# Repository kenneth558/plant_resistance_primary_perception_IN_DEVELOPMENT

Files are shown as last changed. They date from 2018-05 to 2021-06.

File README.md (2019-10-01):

[Project now moved to wiki.  Simply click here](https://github.com/kenneth558/plant_resistance_primary_perception/wiki/Entanglement-GWAAMC), and thank you for correcting your link records!

[Project purchase and building instructions here](https://github.com/kenneth558/plant_resistance_primary_perception/tree/Free/Where%20to%20find%20everything%20for%20making%20your%20own%20GWAAMC%20device)

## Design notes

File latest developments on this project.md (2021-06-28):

<p align=center>Do you have an idea for features?  Now is a great time for all interested parties to ask me about including capabilities you think would make this project as valuable as it can be.  Just submit an "Issue" (see the tab above) describing the device feature that would interest you.  rdetiger asks for compatibility with Adafruit μCs. I think that is a great direction for me to look into. My best guess is that the Adafruit Metro 328 will run this code and accept this board without any trouble.  Thank you!</p>

<dl><dt>28 Jun 2021</dt></dl>Just as I was about to place and solder, I realized that numerous ENIG pads had gotten their gold scratched off by my repeated cleaning the solder off them.  Not having any more unused boards, I have to order more.  Ordered 3 from OSH Park.  They take 10 to 20 days to arrive.

<dl><dt>18 Jun 2021</dt></dl>Apparently my idea of using sparing amount of paste solder on the MSOP-8 packages is not a good idea.  I tried minimizing the amount of paste in order to reduce solder bridging.  I'll need to abandon that idea and order a new stencil having normal apertures for the MSOP-8 packages.

<dl><dt>16 Jun 2021</dt></dl>The oxidized contamination combined with my crazy sleep schedule overwhelmed me and made me miss my sunrise goal...

<dl><dt>15 Jun 2021</dt></dl>I am nearly finished soldering the SMD components to the most populated side of the board.  I expect to start soldering components to the other side by sunrise tomorrow.  I hope to be able to apply power before Saturday 19th at the very, very latest.  NOTE: I expect I'll erase all these development stage updates when the board becomes operational.  The updates will then become informational on discoveries from me and others using the training aid.

A challenge I face is to recognize solder paste oxidizes in short order, the small amounts and just need to be discarded rather than salvaged.  That is against my life's learning about resource management.  What is happening is that I set a small amount of paste solder out to dip from, and as it oxidizes it becomes a source of contamination to the joints I try to add it to.

<dl><dt>03 Jun 2021</dt></dl>I've had to work on the 
[Surveillance project](http://github.com/kenneth558/KingdomComeIMeanItAndIMeanNowSurveillance) instead of this one, but I'm nearing smoother sailing with than one to where I'll be able to come back to this project.  In fact,I'm actually at a point where the final work on the Surveillance project can only be done on site, which means that while I am home I can work on this project.  Thank you Lord!!!

<dl><dt>03 Apr 2021</dt></dl>Basement water problem turned my work area into chaos.  I can't find a clean PCB to build, so I placed another order yesterday for 3 more boards.  It will be a number of days before they arrive.

<dl><dt>06 Feb 2021</dt></dl>My other project is still distracting me from this one......

<dl><dt>20 Jan 2021</dt></dl>Trying to squeegee the paste solder on to the PCB, I find that the stencil retains the paste inside many of the apertures.  I'll see if I can adjust my technique to overcome this latest challenge.

<dl><dt>19 Jan 2021</dt></dl>After dropping an SMD or two, I spread a white drape over my work bench and scrap linoleum under the work table to better allow the finding of such components I'll most surely drop again.  Cost of time and momentum, but I'm returning...

<dl><dt>17 Jan 2021</dt></dl>I received my new solder stencil.  I'll get back to work on this project today after I get a night's rest and attend church later this morning.

<dl><dt>12 Jan 2021</dt></dl>I just discovered that the solder stencil I've had since April had no alignment holes, making it unreasonably difficult to place over the PCB accurately.  I ordered a new one, and it is on its way to me.

<dl><dt>03 Jan 2021</dt></dl>I'm trying to develop a paste solder application scheme.  I have no known finish date, yet.

<dl><dt>27 Dec 2020</dt></dl>I'm just not satisfied with any of the USB microscopes I find for sale.  So instead, I will put together various lenses I have.  The advantage of that is high resolution and accurate color rendering, so I hope it will all be for the better.

<dl><dt>24 Dec 2020</dt></dl>Sigh...  In the re-arranging, my USB microscope broke.  I really need that thing!  Unable to disassemble it (it's probably epoxied).  The good side is that the next one I order should be better quality, if I can make that happen.  Shopping for it next...

<dl><dt>23 Dec 2020</dt></dl>I plan to return to this project today.  FINALLY!

<dl><dt>19 Dec 2020</dt></dl>No updates again, but the security system development is done enough that I'll start now to arrange this project for resumption...after a good night's sleep, maybe two.  During this interim period, I've had to physically re-arrange everything related to this project which makes it not merely a simple matter of picking up where I left off.

<dl><dt>19 Nov 2020</dt></dl>No update again.  Still distracted from this project by having to develop a security system for my father's property.

<dl><dt>08 Sep 2020</dt></dl>No update again.  Still distracted from this project by having to develop a security system for my father's property.

<dl><dt>23 Aug 2020</dt></dl>I'm now being pulled away from this important project by other urgencies, like thieves and vandals to my father's property which make me develop a security system.  His property is where my web server-to-be is located.

<dl><dt>28 Jul 2020</dt></dl>After some weeks of distraction, I am slowly returning to this project.  I think my next step is to place and solder componponents.

<dl><dt>14 Jul 2020</dt></dl>While awaiting components, I am configuring a server for the GWAAMC web site.  It will include a tight firewall ruleset from my poofitee project, knowing how there are so many malicious and mischievous malevolents on the internet.

<dl><dt>11 Jul 2020</dt></dl>My component order ended up being two orders.  One is scheduled to arrive next Thursday, 16 Jul 2020.  The other order, consisting of Q1 and Q2, is pending.  These two P-channel J-FETs one the second order are to demanding specs in noise level and V<sub>gs</sub> cutoff voltage.

<dl><dt>10 Jul 2020</dt></dl>This latest jig looks like it will work.  The quality of print is slightly under past prints I've received, but at least the design that I sent to the printer seems to be correct this time.  Loaded as many components as I had.  Discovered I need to order more components.  Did it.  Waiting for those components to arrive.

<dl><dt>09 Jul 2020</dt></dl>Given clues by the postal service, I found that they delivered to the wrong address.  Jig retrieved, looks like I got it right this time, assembling a board.  Files for printing a jig of your own here -> https://drive.google.com/drive/folders/1_j0E5dFC1kLGvFu55QTtv5UvltjqBdjs?usp=sharing.

<dl><dt>08 Jul 2020</dt></dl>The postal service says they delivered the latest jig to me, but there was no jig in the mailbox or even in the secondary delivery location.  I'll meet the postal delivery person tomorrow and have a talk with them about this.

<dl><dt>02 Jul 2020</dt></dl>Final jig is ordered.  No word if it will go into printing before the July 4 weekend.

<dl><dt>01 Jul 2020</dt></dl>The new jig has some too tight capacitor cavities.  Another one has to be made.  I also realized there are a few components I had yet to order, so I placed component orders.

<dl><dt>30 Jun 2020</dt></dl>While populating the jig, I found a couple issues that really need to be addressed still before it will work.  A new jig will arrive tomorrow which might work.

<dl><dt>27 Jun 2020</dt></dl>Done designing new jig and ordered it.  Now building a board with this jig that I took a utiiity knife to and made it workable.

<dl><dt>26 Jun 2020</dt></dl>Jig received.  Building a board while tweaking the jig design in small ways.

<dl><dt>24 Jun 2020</dt></dl>I will be receiving the jig by Saturday June 27.

<dl><dt>19 Jun 2020</dt></dl>Latest form design ordered.  As a clarification, this is the bottom side form I've been working on.  The top side was very easy and not even necessary but accomlished early on.  Later this day, I received notice that my order has already gone into production.  Based on previous dealings, I expect to receive the jig in 6 or 7 days.

<dl><dt>16 Jun 2020</dt></dl>Received my latest form/holder, and the VSSOP-8 wells are still too small.  Going for one last design now.

<dl><dt>11 Jun 2020</dt></dl>My son offered the term of "form" instead of "cassette" for these components holders.  I didn't care for calling them "cassettes".  I'll change their term to something like "holder" or "form".  They can also be called a "jig", but only as a last resort.

<dl><dt>09 Jun 2020</dt></dl>That cassette was better, but still not right.  Made corrections to design and ordered another.  A return notice is telling me the new cassette is already in production.

<dl><dt>05 Jun 2020</dt></dl>I received notice that my latest cassettes will arrive Monday, 08 Jun.

<dl><dt>03 Jun 2020</dt></dl>Again, The components wells were too small.  Ordered ones with larger wells and using three different materials.  I was promptly notified that my order went into production, for which I am pleased, of course.

<dl><dt>01 Jun 2020</dt></dl>The projected arrival date of my newest cassette has been changed to be today in about 4 hrs.

<dl><dt>28 May 2020</dt></dl>I had to modify the cavity sizes a bit larger in the bottom cassette and order a new one.  It is scheduled to arrive Tuesday June 2.

<dl><dt>17 May 2020</dt></dl>The cassettes are still in "Production started" status according to craftcloud3d web site.

<dl><dt>13 May 2020</dt></dl>I placed a new order for top and bottom resin cassette. No word as of 14 May 9am whether the order will get honored, but my last resin order did get made for me.  Product expected in 9 days.  Once the cassettes arrive I can start constructing boards.  I will also need to locate carbon fiber "tape".  Most of what I see for sale uses the term "graphite" in the sales lit.  Graphite and diamond are the WRONG forms of carbon for me to use.  I wish everyone would stay away from using the term "graphite" unless the molecular structure is actually graphite.  Bad terminology makes me have to dig deeper and even travel hundreds of miles to measure electrical resistance.

<dl><dt>12 May 2020</dt></dl>Both my cassette orders got canceled due to too fine of features for ABS.  I've arranged for someone to see if they can print the bottom.  No word back from them, yet....

<dl><dt>09 May 2020</dt></dl>Placed the order for the bottom cassette. 

<dl><dt>08 May 2020</dt></dl>Just placed an order for a new top aspect cassette.  Still working on the bottom to add one last item - some tin whiskers cages for the larger IC packages.  The design for MSOP package cages are done.  These cages will span across the IC packages to contain any tin whiskers that might form to only the pin they originate from.

<dl><dt>07 May 2020</dt></dl>Now making final changes to the bottom aspect cassette.

<dl><dt>05 May 2020</dt></dl>My cassette top will arrive tomorrow.  The design for the bottom is complete, sans any changes I will learn it needs from examining the top when I get it.  If all is well, I will order a bottom aspect shortly after I approve the top.

<dl><dt>03 May 2020</dt></dl>Still working on the cassette bottom.  Since it is substantially more detailed than the top side, it is taking longer.

<dl><dt>01 May 2020</dt></dl>I ordered a revised top aspect cassette (top "side" sounds strange) yesterday, and it is already being printed.  I'm close to being finished designing the bottom aspect.  It really could be done in an hour by someone with more stamina than I have.  I'll see what I can do...

<dl><dt>29 Apr 2020</dt></dl>I received the top side cassette from the 3D printing service.  The top is the simplest side, so I finished designing it first and will be able to apply whatever I learn to the design of the bottom side cassette.  I've learned the bare PCB needs greater clearance to slip on and off without forcing.  Applying said knowledge to the bottom side design now.

<dl><dt>23 Apr 2020</dt></dl>I've received my paste stencil, but without a cassette printed, I am hindered to lay out the components rapidly enough to before the paste dries.  I am working on designing and 3D printing cassettes to place an entire side of components simultaneously.

<dl><dt>12 Apr 2020</dt></dl>A very blessed Resurrection Sunday to you.  Are you aware we are entering into a season many years long in which many resurrections will take place?  Even some people that have had their bodies cremated will be resurrected!  As I observe our society, I can't help but realize we need some help getting to that point.  People need to learn to put their faith to work, and to work hard.  That is EXACTLY what this project is all about!  In Jesus' name

<dl><dt>11 Apr 2020</dt></dl>I ordered my first solder cream stencil from OSH Stencils.  I am so thankful they priced themselves below China, considering shipping.  Delivery time is also as fast or faster than any Chinese fabricator can do.

<dl><dt>10 Apr 2020</dt></dl>I changed the solder cream layers for the MSOP-10 packages to minimize the component pins mashing the cream into solder bridging between pins.  Added notes into gerbers as well b/c the fab house was confused about guard rings and copper zones joining traces.  Next, I am considering a unique technique to place the components down into previously laid solder cream.  It will consist of a stepped (multilayered) transparent stencil into which the components will be placed upside down.  The freshly creamed board will be laid down on top of the undersides of the components.  The assembly will be flipped over and the top stencil carefully removed.  Viola, one side ready to bake.

<dl><dt>07 Apr 2020</dt></dl>I'm hoping this latest technique works to place MSOP-10s on double-tinned pads works.  After double-tinning while pressing down on the solder (to better displace the gold), I use the hot air tip to smooth the pad flat.  One last solder layer, this time we convert to bismuth, then scoop the pad flat again.  That doesn't leave much solder there, but at least the MSOP-10 package stays put during hot air soldering, plus we've converted to low temp solder _on ENIG_ :-).  Note that you should not allow leaded solder to be sitting anywhere around lest you mistakenly use it and thus corrupt the bismuth.
<dl><dt> </dt></dl>
The sheer tediousness of the job compels me now to order stencils.  Soliciting quotes next...

<dl><dt>05 Apr 2020</dt></dl>MSOP10s are absolute bears!  Still not done.

<dl><dt>31 Mar 2020</dt></dl>Double-tinning without ending in shorts is not so straightforward.  And after that enough gold too often remains so the wetting is impaired.  Not impossible, though.  Continuing the work.

<dl><dt>29 Mar 2020</dt></dl>I am double-tinning the first board, after which I will flatten the solder, then place components.  All of this goes slow so I can update the instructions as I go along while letting wife sleep in the same small room.

<dl><dt>28 Mar 2020</dt></dl>I received my ckt boards from OSH Park and inspected them.  So now I'll change the gerbers to make smaller solder mask holes over the vias so they will be less likely to short over to nearby copper during soldering.  Until that new design is published, you'll just have to give extra attention when soldering those vias.  Some of you may wonder why you'd solder a via?  It's to hermetically seal inside the shields because the REF200 requires it for long-term stability if used for measurements in a laboratory environment.  I'm just trying to permit that use.  Note that I avoid using the term "measure" in normal intended use of this device - its normal use is for "observation", not measurement.  Yet I'll try to design not to preclude measurement use.
<dl><dt> </dt></dl>
BTW, when soldering vias, bismuth solder is preferred b/c it uniquely expands on solidifying.  Make sure you don't mix it with leaded solder, though.  Research it if you don't know why.

<dl><dt>25 Mar 2020</dt></dl>I received notice today that my lead-free HSAL boards from PCBCart will ship April 1.  My ENIG boards have been fabricated through OSH Park and are being shipped today my direction.  I am putting my time to use researching methods of assembly.  I'm planning to use an acrylic "footprint position" stencil made KiCAD's .pos file if I can determine how to render it into a stencil.  

<dl><dt>19 Mar 2020</dt></dl>While awaiting the arrival of boards with the two finishes, I'll state that I have high hopes in my board designs.  What I'm not sure about is which op-amp to specify for U2.  Right now it is the OPA2388.  Regardless, the footprint on the board is VSSOP-8_3.0x3.0mm_P0.65mm, which is a TI specific footprint but I chose it hoping it will also work for similar sized SO-8 dual op amps.

<dl><dt>14 Mar 2020</dt></dl>I am going to try to get boards in lead-free HASL instead of fighting with this ENIG that really needs a soldering fountain to wash off the gold.  I have no soldering fountain, so I'm trying to do it with a soldering pencil, and it is too frustrating.

<dl><dt>11 Mar 2020</dt></dl>In addition to keeping the two-board design, I had to combine boards into a single board design in order to make lead-free HASL quotes more convenient and reliable.  Those new files are available for you but only if you find them in this directory https://github.com/kenneth558/plant_resistance_primary_perception/tree/Free/Where%20to%20find%20everything%20for%20making%20your%20own%20GWAAMC%20device/Files%20you%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.

<dl><dt>04 Mar 2020</dt></dl>Received 1 oz boards and am losing pads during the double-tinning ENIG wash.  The 2 oz boards were more robust against this problem, but I am not given the ordering option of expediting 2 oz boards.  I do not advise 1 oz ENIG boards.  I will investigate ordering lead-free HASL boards from China unless I find a decent price locally.  HASL boards don't require the double-tinning wash.  In the meantime, I will try to get these other ENIG boards built.

<dl><dt>25 Feb 2020</dt></dl>I have completed yet another PCB design of both the main project board and the auxiliary board.  The project files at OSH Park are: main board https://oshpark.com/shared_projects/y7WQJ0Jt, aux board https://oshpark.com/shared_projects/kbQQkkZ4, both boards attached and combined into a single file https://oshpark.com/shared_projects/0zQW3Jms.  I am awaiting delivery next week, then I'll have to build them out.

<dl><dt>19 Feb 2020</dt></dl>I've received the newest PCBs and found numerous shorted traces the result of my design having violated manufacturing limits.  I will have to increase the size of annulars on the auxiliary board in a new design and re-order boards.  Day 2 of doing this: about 15% into the new design.  At that rate it will be the end of the month before the design is complete.  That rate is unacceptably slow, so I'll try harder.

<dl><dt>11 Feb 2020</dt></dl>Had to cancel the previous expansion board order for better hole alignment.  Now completed and new orders of both boards are being processed.  Expected delivery is by 18 Feb 2020

<dl><dt>24 Jan 2020</dt></dl>Received notice that my shipment of 3 main boards will arrive Monday (today is Friday).  I'll be able to begin placing those components then, but in the meantime I need to finish design of the flex circuit and get 3 of those on order.

<dl><dt>18 Jan 2020</dt></dl>Just finished fitting all copper traces onto the main PCB.  I did have to move the HX711 ADC off to the side onto an optionally cut-off tab due to lack of room.  I am now widening selected traces (Vcc and GND for example) and laying down the non-copper layers.
<dl><dt> </dt></dl>I am also having to redesign the auxiliary board that holds 25 MCP4262-502E/UN dPots.  This aux board now has to fit underneath a shield with different dimensions than before.  The good part is that I've already designed the pattern for that aux board, so seeing the aux board through from this point will be trivial.  UPDATE - I'm taking a rabbit trail to learn how to use a plug-in that replicates sub-circuit traces since I have 25+ subcircuits to replicate and KiCAD keeps producing rounding errors with its own replicating methods.  What should be trivial will now involve an additional learning curve.

<dl><dt>26 Dec 2019</dt></dl>I've been pulled away from this project by other assignments, but the larger issue that has me entangled is that I'm re-designing the main circuit board from ground zero to accommodate the fact that there was no drop-in replacement for the AD8244 that offered zero crossover distortion.  I would say two more months before I can finish the design, then another 4-5 weeks for PCBs of that design to arrive, then a week to build one up.  Fourteen weeks until the latest design is working.  April-ish.

<dl><dt>21 Nov 2019</dt></dl>My LMC662 came yesterday.  Other op amp types that I can compare with will arrive today.  The LMC662 has better noise and input bias current characteristics than the other ones I've ordered, but it doesn't work at 3.3 VDC.  We'll see if the noise characteristics are acceptable.  I figure by the time I'm done, the AD8692 will win out.

<dl><dt>18 Nov 2019</dt></dl>To avoid the input bias current caused "crossover distortion", as it seems to be called, I'll have to re-design stage 3 without the rail-to-rail input (RRI) AD8244 and use a non-RRI op-amp instead.  That takes the expected project completion date into December.  Sorry.  (Anyone know of a non-RRI quad unity gain buffer so I don't have to deal with more pins that go along with the op-amp solution?).  Until I change my mind, I'll be changing the design to use an LMC6036 and remove the AD8244 altogether.

<dl><dt>17 Nov 2019</dt></dl>Back in business.  Q1 needed to get a higher cutoff version (which I had anticipated as a possibility) and with Q2 out and Q2 footprint shorted Drain to Source (might get reverted later), there are no oscillations any more.  The downside is that there will be less possible gain without Q2.  Since I was only guessing around with gain anyway, I'm not going to sweat it until that extra gain shows itself being needed.  Onward sans Q2 to track down a bit of undesired hysteresis in the current-to-voltage stage (aka, 3rd stage) which is surely from AD8244 bias current "...rail-to-rail input stages have bias currents that change direction as the common-mode  voltage  passes  through  the  transition  region" (https://www.analog.com/media/en/training-seminars/tutorials/MT-038.pdf).  Exactly descriptive of what I'm seeing.  My solution for now will be to subtract the transition region from the output and see how it looks.

<dl><dt>16 Nov 2019</dt></dl>The latest thing that has slowed me down is needing to clean the circuit board at a location where there was no isopropyl alcohol.  Instead of alcohol, I found what I thought might work instead because its odor indicated an isopropyl main ingredient.  It was for cleaning lenses or something, so I used it.  That was a bad idea.  It left a seriously detrimental conductive residue underneath components.  I didn't understand for several days after why the circuit was acting strange after that.  I'll have to pull components and clean under them until I get proper operation back.

<dl><dt>14 Nov 2019</dt></dl>I'm seeing a low level of undesireable positive feedback so as to make the analog output at A0 a little unstable right around mid-point between rails.  It might be the effect of AD8244 bias current, but whatever the source, I'm intent to identify it and compensate.

<dl><dt>09 Nov 2019</dt></dl>Removing (shorting across pins 1 and 2) Q1 and Q2 seems to alleviate the oscillations.  The flip side of doing that is twofold - less gain can be gotten in the third stage and the voltage on the guard ring trace for U5 is slightly imperfect.  (Shorting across Q1 is probably overkill, and I may experiment with undoing that or using one of the other JFETs with higher pinch-off voltage for Q1 and even Q2.)  Neither issue is important enough to get wrapped around the axle over.  Full testing resumes now.

<dl><dt>08 Nov 2019</dt></dl>A better look at the oscillations produces evidence that they are produced by the 3rd stage high impedance creating a type of relaxation oscillation in the presence of any solute/DUT current at all.  Will work more on cleaning and inspecting the main board, especially since I've left a bit of solder flux on the board, and studying the design and datasheets.

<dl><dt>04 Nov 2019</dt></dl>Due to oscillations with apparent origins in inadequate power supply decoupling, I have changed the values of C3 and C5 to 10 µF.  Testing tomorrow....

<dl><dt>01 Nov 2019</dt></dl>I have gotten the manual tuning aspect of the sketch to function.  I envision a better method of tuning, but that path of programming eludes me for the time being.  The type of tuning that I hope to one day program into the sketch would treat the LM334 pair in opposing adjustment as one function block (entitled "DC level" or "DUT impedance balance") while that same LM334 pair working in in tandem adjustment as a different function block (entitled "dilution ratio").  That scheme in contrast to the easy-to-program manual tuning I'm resigned to run with for now.  The manual tuning is at level 4 of Diagnostics rather than being built into the main aspect of the sketch.  That is what I'll use to prove concept during tours so I can just get going and make this project known by demonstration.  Tested at 5 VDC only for right now.
<dl><dt> </dt></dl>
Engaged the DUT and the graph won't keep the trace inside the boundaries for me.  From the looks of it, the circuit gain is too high.  At least, that is my first suspicion.  If that is the case, I will have to modify the circuit.  Current signal circuits are very unusual, and their troubleshooting methodologies are different than those of normal circuitry. You can't just put a scope or meter on a node to see if operation is within normal limits.  I may have to develop circuit modifications purely for troubleshooting.
<dl><dt> </dt></dl>
I need to take a break right now.  I'll get back to things later today.

<dl><dt>22 Oct 2019</dt></dl>Yesterday I found a large difference in conductivity between attaching to the DUT plant while located at a tech library with fluorescent lighting vs. at a residential house with only incandescent lighting.  I'm suspicious that the difference had nothing to do with the lighting but may be attributable to either a circuit board intermittent or a second stage current balancing micro-amperage level.  The amount of current operating in the second circuit stage may end up being a very important tuning consideration.  Regardless of any aforementioned item, I have no reason to doubt anything about the circuit design except that more power supply decoupling may be in order.  In the next few days I'll add some via air-suspension to see if there is any reason to enhance the circuit with it.

<dl><dt>21 Oct 2019</dt></dl>Attached to a plant for the first time today - one electrode around the stalk and one enclosing a leaf.  I see far less conductivity than I expected.  That being the case, the interference from the fluorescent lighting is also annoyingly significant.  I'll need to get the sketch working and work on controlling the board's electrical and temperature environment next.

<dl><dt>17 Oct 2019</dt></dl>Updated [this flex board](https://oshpark.com/shared_projects/59YhWYRZ) to contain a U7 expansion section, since it doesn't cost any extra and it will help me use up a number of old valued U7's that I bought before I settled on using the 50K values that are in the final design.  If you don't want this cut-away piece on your flex board, just order normally and avoid using the link in the previous sentence.

<dl><dt>15 Oct 2019</dt></dl>Once I soldered J9 better and then kept the flex board clean every time I add a dPot on it, all works well.  I CONSIDER MY CIRCUITRY DEVELOPMENT TO BE SUCCESSFULLY COMPLETED NOW.  Finishing the sketch is the next on my list after some car repairs...

<dl><dt>13 Oct 2019</dt></dl>I'm beginning to suspect the flex board problem is a combination of J9 not being solidly soldered onto the main board and conduction on the flex board from traces of contamination that need to be cleaned off better.  I'll get back to work in a few hours.

<dl><dt>12 Oct 2019</dt></dl>I have the main board working consistently, but the flex board is misbehaving much of the time.  That is what I'll be working on next.  I'm quite sure the problem I'll find is a soldering problem rather than a board design problem.

<dl><dt>11 Oct 2019</dt></dl>I changed the flex board to accommodate a through-hole GNDD pad dedicated for shield grounding.

<dl><dt>09 Oct 2019</dt></dl>I've now verified operation of Rev. 8 and re-versioned the perfected rendition to Version 1.0.  You'll see lower noise in the output if you enclose the flex board in foil EMI protection, please.  I used aluminum foil with appropriate insulating tape for my prototype.  Note that I won't develop temperature compensation in the circuit any time soon, so I am avoiding the term "measure" in favor of "observe" when I refer to electrical conductance of the DUT.

<dl><dt>07 Oct 2019</dt></dl>I just corrected a short between GNDD and 5VDC due to the boards not getting fully etched.  I corrected the design at that location to prevent it from happening again.  Power applied and I'm now running and tweaking the diags...

<dl><dt>03 Oct 2019</dt></dl>The solder joint issues with the fine pich components seem to be never ending.  I'm still not done with the visual inspection, but when that is finished I'll apply power...

<dl><dt>29 Sep 2019</dt></dl>I just finished placing all components onto this board rendition.  Before I apply power, I'll have to spend a few hours examining the entire thing.  First, however, comes a night's sleep....

<dl><dt>28 Sep 2019</dt></dl>Yesterday I finished building out one rigid main board and built out one flex board.  I had much difficulty soldering down SMD components that I had the "wise" idea of laying out on the adhesive side of my Kapton flex prototype.   I'll re-build the entire flex board today after my night's sleep and after I clean those SMD components with contaminated leads.  Then I'll spend several hours examining the boards with loupe and microscope before applying power.  Then I'll repair whatever build mistakes I made, after which I'll know whether my design (sans wireless and SD Card) is all I hoped it would be.  Wireless and SD Card operation may or may not work, but checking their operation is low priority for my time at this stage.

<dl><dt></dt></dl>GOT TO WORK FOR THE DAY AND MY SOLDER STATION BROKE.  All soldering work is on hold while I await heaters for my solder station.

<dl><dt>27 Sep 2019</dt></dl>I received 4 copies and am building out one of the flex board.  I don't know why they sent 4 when they say 3, but I'm happy about it.  I also had to order some components in the LDO circuit stage that I overlooked buying.  I expect that order to arrive today.

<dl><dt>23 Sep 2019</dt></dl>While building my latest design boards, I will fine-tune various files here to reflect refinements I deem necessary.  Just updated iBOM and board designs at the KiCad file-type level, but not the gerbers yet.  New board designs are in recognition that solder mask seems to be an adequate hermetic seal for inside SHLD1.  Therefore, I removed the solder mask blocks I had placed on those micro-vias.

<dl><dt></dt></dl>

Also while building these boards now, I'm focusing on getting the boards to working condition the quickest I can so I'm not video recording.  I'll video record for you once I get a few more boards under my belt.

<dl><dt>22 Sep 2019</dt></dl>Although I didn't know it until today, I received my order of 3 main boards (not the flex boards) yesterday.  I will start ASAP to build them out.

<dl><dt>21 Sep 2019</dt></dl>Building my server complex has been curtailed by ISP blocking port 80 traffic into my modem.  This even though they assured me back when that they would not do such a thing.  Negotiating with other ISPs that can give me a data drop.  So far no success with that.  Anyone want to help me out here?  Open an Issue to let me know.  My specific need is acquire and install my SSL certificate for e-commerce, which requires my server to receive port 80 traffic.  Thank you!!!

<dl><dt>15 Sep 2019</dt></dl>I tweaked the J9 flex connector footprint in a PCB edit to strengthen it mechanically - I moved some nearby PTH vias into its GND attachments so that SMD pads weren't the only means of it staying attached.  With this change, solidified solder through the depth of the board under the flex connector's GND attachments will assist the board's SMD pads holding that connector down.  Not only that, but I made those vias large enough to place guy wire ends into so that connector could actually also be held down with a guy wire around the top side of it for even greater strength.  The OSH Park project is updated with this enhancement.

<dl><dt>13 Sep 2019</dt></dl>While I await the [hopefully] final boards, I'm building my server complex to host gwaamc.com and all my other domain names with pages, videos, and forums.  This will be a child-friendly and adult-friendly venue.  Any hostile, uncivil, and profane language posts will be removed and responded to with a permanent and uncompassionate ban from the site.  An iptables ruleset that I've developed myself will be modified as needed to ensure the utmost security for my server.

<dl><dt>09 Sep 2019</dt></dl>The final correction (of a backwards connector) has been incorporated into the latest PCB design.  Additionally, a flex board expansion board design is finished.  I would venture to bet this new main board and the flex expansion board will work just fine.  I have them on order from OSH Park now.  When they arrive in two or three weeks, I will expect to take about a week or so to prove their operation.  Mid-October-ish.

<dl><dt>06 Sep 2019</dt></dl>I'm changing schematic symbol numbers for U1 and up for the ICs and changing chip select pins from the MCU.  That means I'll be publishing a new schematic and any references to U numbers and CS pins in previous postings and documents are now obsolete.  Be sure when examining any documents referencing U numbers and CS pins that you realize those changes that occurred as of this date.  I'm hoping to correct a lot of it on GitHub within minutes.

<dl><dt>03 Sep 2019</dt></dl>I've adjusted the PCB design to accommodate an LDO for USB power decoupling and have been designing a flex board to hold gobs of MCP4262-502's in parallel.  It's tedious but coming along.  All those MCP4262's in parallel are going to reduce their resistance step size down from 5KΩ/256 (19.5 Ω) of a single Dpot to a possible 5KΩ/256/26 (0.751 Ω) with 26 Dpots.  The result will be much, much better fine tuning of the signal, biasing it to the best voltage level (1.494 VDC) for the 24-bit ADC (HX711).  If 26 Dpots ends up being too many, you can just place on the flex board the number of Dpots that works the best.  I intend to design that flex board to be able to be cut to size conveniently.

<dl><dt>26 Aug 2019</dt></dl>I've decided that the USB cables that power this board contribute too much Vcc noise when they're worn from a lot of use, so a zener diode off U2 [old U number] VREF is required.  Learning from performing the diags, I also want to add a couple current limiting resistors, one each for U4 and U5 [the new U numbering has changed these U references to U5 and U6]. That means shifting board traces to make room where there seems to be no room.  That will be PCB Rev 8.  Rev 7 does work, though, if you can't wait.  If you want to get PCB Rev 7 simply because Rev 8 isn't ready yet, you can air-bridge the zener diode on the Rev. 7 board if you want to.  You would put the diode cathode end on pins 2 &/or 3 of U2, the anode end to GNDA, but you'll likely have to add a little bit of a wire to one end or the other or both of the diode.  You'll have to do without the resistors, however. 
<dl><dt> </dt></dl>
Another change forthcoming in Rev 8, and even more vital, is stackable U6 [the new U numbering has changed these U6 references to U8, 9, 10, etc.] in order to obtain higher resolution by paralleling 5K U6's in a stack, less the SDO (MISO) pin 9's which aren't connected to anything.

<dl><dt>24 Aug 2019</dt></dl>The board now works fully at 5VDC after cleaning specks and other contamination from the area around U6.  It is not fully stable at 3.3VDC when a transient overload condition occurs.   Investigating this...

 <dl><dt>24 Aug 2019</dt></dl>The board works at 5VDC only.  I've posted new gerbers at OSH Park to change some pin assignments that tended to cause confusion while running diagnostics, but any differences between the newest board and the previous version are operationally inconsequential.  You may now buy PCB boards from wherever you want to  with assurance that the product works at 5VDC.  

In fact, this now works so well at 5VDC that the HX711 may not even be necessary!

I'm investigating now into 3.3VDC operation.  The difference seems to be that the U6 dPot with the buffering resistor isn't changing settings at 3.3VDC when being told to, yet it works just fine at 5VDC.

<dl><dt>23 Aug 2019</dt></dl>I've fixed everything I broke an am now ready to proceed with placing U3 and SHLD1, which should be done as a single step without allowing any interruptions so that U3 is not left to absorb moisture from the humidity in the air.  Let me say that this project is very, very difficult to build...nearly impossible for me.

<dl><dt>22 Aug 2019</dt></dl>I'm hopeful I found the last of the circuit problems...about half dozen broken traces and lifted pads and about twice that many solder joints that didnt take.

<dl><dt>21 Aug 2019</dt></dl>I am having fits with an apparent open circuit in the programming resistor circuit of U5.  Yet another nightmare, but everyone building this will benefit from the improved diags that it makes me write and PCB test points I lay down.

<dl><dt>19 Aug 2019</dt></dl>Today I found that I had placed two U7s instead of a U6 and U7.  Would have made definite progess otherwise.  Replaced.  Starting again writing the diags for this step.

<dl><dt>18 Aug 2019</dt></dl>I've made more progress on the diagnostics after having to abandon my first U1 [the new U numbering has changed these U1 references to U2] due to solder cross contamination.  Early on I tinned the leads of that component with leaded solder and have been plagued ever since with it rejecting other solders.  I handled it so much that its leads started falling off.  $6.  The new U1 took low-temp paste solder like a champ, but the whole experience sure tested my patience.  These new bismuth solders don't mix well at all with the old leaded solder!  A word to the wise.

When I resume development, I'll be writing diags for U6 and U7, the dPots.  I'm hoping the ones I've installed have no issues for me to troubleshoot, but I can't expect a perfect world.

After that comes placing ADC1 and writing those diags.  Then U3 w/last of diags, SHLD1, J1, and the potentiometers.

<dl><dt>17 Aug 2019</dt></dl>I've been working on developing the build instructions which are found in the BOM named ibom.html in this directory https://github.com/kenneth558/plant_resistance_primary_perception/blob/Free/Where%20to%20find%20everything%20for%20making%20your%20own%20GWAAMC%20device/On%20buying%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.  On my own board, I'm up to the diags right before placing ADC1.  What remains after any troubleshooting the diags make me do is to place ADC1, U3, SHLD1, J1, and the potentiometers.  BTW, I'm writing the diags as I go, so that adds to the slowdown.

<dl><dt>12 Aug 2019</dt></dl>I'm to the stage of fine position adjusting so this board best fits an MCU while I'm powering up for build diagnostics.  The components I have left to place are ADC1, U3, the RF shield, J1, the potentiometers, and the wireless module.  These have to wait until I develop diagnostic code for the state of the build as is.  However, I'm taking a family road trip now and won't be making any more progress on this until late this week.

<dl><dt>10 Aug 2019</dt></dl>While building, I've just learned one has to place the two-leaded components and U2 [the new U numbering has changed these U2 references to U3] after the multi-leaded ones other than U2.  U2 is so compact that it is as susceptible to collateral de-soldering as the two-leaded components are.  In other words, I've been slowed down building because U2 had to be soldered on twice, and it is a bear to do it even once.  Past that, now...

<dl><dt>08 Aug 2019</dt></dl>Building a new board that I expect will become the first working rendition of this project.  I'm placing components, then performing diagnostic tests on what I've just placed.  I've succeeded in the first diagnostics step of getting function from U2 and now in process of installing LEDs and their driving circuitry.

<dl><dt> </dt></dl>I'm trying to work the word "Entanglement" into this project's title.  I think it works best being the type of gardening..."Entanglement Gardening".

<dl><dt>06 Aug 2019</dt></dl>I just made one last improvement - I freed up pin D4 so it may be stacked on top of an SD card shield to store the plot during learning sessions.  Code has not yet been written for that feature, though.

<dl><dt>03 Aug 2019</dt></dl>I've been making scores of cosmetic changes to the PCB design and some copper changes to enable ESP-01 wireless module to work.  J6 is now 9 pins long for wireless modules.  I emphasize that I have no code to operate any wireless right now.  Rx of the MCU runs to Tx of the module and vice versa.  Some modules may have pinouts that will require solder jumpering of nearby pads.  I've eliminated solder mask in those places to facilitate such jumpering.  My hopefully functional boards of a previous edit level should arrive in a day or two and we'll assemble, troubleshoot, and publish instructions immediately.

<dl><dt>26 July 2019</dt></dl>I'm seeing that if you choose to use solid wire solder (not that I'm recommending that, but if that is a limitation...), you'll need to use Kapton polyimide tape over both the components and the two tiny pieces of appropriately sized solder (obtained from being mashed down then cut with scissors &/or knife blade) at the component ends, and a hot air solderer is best.  The Kapton tape stands up to the heat and holds everything in place while the solder melts.  To allow the hot air to reach the PCB traces (a necessity or the traces won't get hot enough to adhere to the solder), you'll need to have the edge of the tape follow the center lines of the three pieces lined up end-to-end - solder, component, solder: one half of each of them are under the tape.  Aim the hot air into them from beside the tape.  They will tend to fly out of place unless you also add some flux or rosin on them before starting the air.  When finished soldering, the same piece of tape can be re-used for the next component, as tough as Kapton is.
<dl><dt> </dt></dl> 
I've added guide traces (fiducials) for pick and place contracting and have updated the PCB.  That way you can have a vision-capable pick and place machine place the components.  

<dl><dt>25 July 2019</dt></dl>Even though I have the PCB on order, I'm looking through the PCB design for anything that I might have missed because OSH Park has been very accommodating with me pulling the orders and replacing them when up until they send it out for etching if I find any little thing I decide I can improve in the PCB design.  Those changes would be mostly in minor silkscreen edits rather than anything affecting operational specifications.  There are a couple places where i've had to compromise with circuit guard rings in the two layer design.  A four layer or flex design would perfect those issues, but at a cost that I can't justify right now.

<dl><dt> </dt></dl>Well looky there - I just got now notified that OSH Park sent the board in to get fabbed.  Nice!  While I wait on this final board design, I'll use  all the prior designed boards I've accumulated to perfect the special soldering techniques I need on these ENIG boards.  When soldering onto a new ENIG pad, the gold layer migrates into the solder and raises that melting point noticeably by making the solder less eutectic.  I had not anticipated that in my first placement attempts so had my soldering temperatures set to just barely melt the solder.  That didn't work, and I had to find out why.  I now realize I have to raise the soldering temperature to overcome that new-ENIGed-pad effect.  One option I'll consider is to remove the gold layer with double tinning that is required industry standard practice now, but I'll prefer a single-pass placement rather than a two-pass.  Why is this such an ordeal?  Because I'm trying to avoid leaded solder, which leaves me possibly using higher temperature solder even while one of the components, U3 [the new U numbering has changed these U3 references to U4], specifies a soldering temperature lower than is common for electronics components.  Besides, lead and gold don't play solder together at all, yet ENIG gold plate keeps the pads nice and flat for fine pitch components.  Adding the place-assist holes around those fine pitch components like I've done in these later PCB designs may allow everyone now to use lead-free but not flat HASL instead of ENIG and allow single-pass placement.  Lead-free HASL tinning melts at about 450F, so that is getting close to the limit for U3 where temperature control and limiting will absolutely be essential.

<dl><dt>24 July 2019</dt></dl>I put alignment assist holes around U1, U2, U6, U7 and the shield and put the new PCB design.  I finally feel very good about the state of this PCB design but emphasize it is still UNTESTED.

<dl><dt>20 July 2019</dt></dl>I am developing a different method of soldering the center pad of U2 - I am putting a via underneath it that I will give a slightly oversized hole.  That much is in the latest PCB files here on GitHub, but since I am also adding line-up holes around the more difficult to place components in a design later today, I pulled the OSH Park order until I finish that enhancement.

<dl><dt>19 July 2019</dt></dl>Today I discovered that disparate solder types/compositions cannot be mixed.  That tells me why I have been having so much trouble building my first boards.  I've been cavalier about mixing 138C Bi/Sn eutectic solder and leaded solders, for instance.  That causes Bi solder to fail when thermal cycled above 95 degrees C.  Other types of cross contamination simply won't adhere by increasing the melting point too much.  I'll have to start building a board all over with a clean, new board and clean, new components.  Lesson learned.  I expect much easier building after this!  I also updated the PCB to space components better and fix silk screen imperfections.  The PCB now also contains a warning against mixing solder types so we never forget.

<dl><dt>16 July 2019</dt></dl>Soldering clearances were less than ideal.  Increased them on PCB and put the new one here and on OSH Park.
<dl><dt>15 July 2019</dt></dl>When I powered up the board-under-construction, the prelim diags showed I had given Q3-7 a wrong pinout at the footprint.  I pulled that PCB design off and put up a new corrected design.

<dl><dt>13 July 2019</dt></dl>I made some very minor adjustments on the PCB to move some words in silk screen and solder mask to where I think they would look more professional.  That PCB design won't appear at OSH Park until my next order, but you do find it here at GitHub, as always.

<dl><dt>12 July 2019</dt></dl>Added a jumper near ICSP1 pin 2 for ease of disconnect in case the power there doesn't match a 3V3 MCU Vcc.  I discovered that will sadly be the case with most 3V3 MCUs.  PCB files updated, new OSH Park order placed for the project on OSH Park.

<dl><dt>11 July 2019</dt></dl>I discovered the Arduino 101 is a 3V device with onboard BLE that could allow this HC-05 capability to then be used for wifi instead of BT/BLE.  Since that would be a nice feature, but the Arduino 101 is 3V only, I modified the PCB a little to allow easy jumpering to 3V operation without needing to cut any trace.  Just pull out pin 5 of J2 if using the Arduino 101 and use part of it or a similar size wire segment to solder down as a jumper instead of cutting a trace.  If you do this, don't ever use the board in a 5V environment without reversing this mod!  
<dl><dt> </dt></dl>
I have not tested 3V operation idea, and I would not expect Q1 and Q2 to allow for it unless those two JFETs are shorted across S to D.  However, it would be very nice to find they don't need to be.  There are 3 different versions of that JFET (MMBF5460, MMBF5461 & MMBF5462) - one or even all of them might work fine in the 3V environment without shorting them out of operation.  I still haven't built a board completely, so I don't even know which JFET version I'll end up with anyway.

<dl><dt>08 July 2019</dt></dl>I added BlueTooth module capability, which means a new PCB design is out there now.  I have not added the BlueTooth module to the parts list...its up to you to find one that suits you.  Get one that follows the same pinout as HC-05, a very common pinout for wireless modules in applications like this.

<dl><dt>07 July 2019</dt></dl>I made a few tweaks on the PCB design and couldn't think of any more to make, so I ordered that latest PCB design which updated the PCB design published by OSH Park to the very latest.  Still, be aware that I have NOT assembled any PCB fully enough to operate.  I expect I will do so in about a week, but I cannot claim any of this project works in its present design.  All developers of hardware and software know enough that future changes in circuit and software should still be expected at this stage of the project.

<dl><dt>06 July 2019</dt></dl>Discovered I neglected to order one last(?) component needed for board completion.  Ordered it from USA, and I expect arrival in a week maybe.  I also discovered a silkscreen imperfection and posted a new PCB layout on this site only (not on OSH Park site until my next PCB order happens) correcting it.  

<dl><dt>03 July 2019</dt></dl>Today I placed my electronics component order that I expect will complete my purchase of all remaining components I need to populate and energize the first rendition of this project.  Enough of the order should arrive in two days to get it working.

<dl><dt>29 June 2019</dt></dl>After spending another couple hours trying again to solder C1 down, I realize that the problem of there being too much space between C1 pads for both to attach to C1 simultaneously, if this board version had to be salvaged, would require some makeshift piece of solid copper to bridge  to one or the other pad.  I'll get back to that possible workaround once I get a more workable board designed and ordered.  

In my judgment, the specific C1 I'm working with right now is actually too small for the 0201 pad.  It should have been spec'd for the next smaller size pad, which is actually not feasable with my PCB software nor fabricating house.

<dl><dt>27 June 2019</dt></dl>Discovered that I spec'd C1 far too small physically to handle and solder onto the PCB.  I lost about 8 of them from their small size while simply trying to develop a means of soldering them to the PCB with solid solder.  That step took about 4 or 5 hrs and I ended up pulling the C1 footprint off the board.  I'll have to wait until my low temperature paste solder arrives later to resume my attempt to build my first working PCB.  BTW, this small C1 will fit into a space half or less the size of a pinhead and just might be the smallest component to claim a 0201 pad.  Every time I observed one through the magnifying glass, I was newly amazed all over again how microscopic it is.  It is not even long enough to connect between both pads without adding some sort of bridging conductor.

I'll be making a new PCB design once again <sigh...>

<dl><dt>15 June 2019</dt></dl>PCBs on their way to me for arrival Monday 17 June.

<dl><dt>09 June 2019</dt></dl>It won't be too much longer before I get my PCB (bare) I have on order. I have enough components to build it out. Depending on how many build mistakes I make I could have it built by July week 1. After that my guess is another 3 weeks sketch development time.

<dl><dt>06 June 2019</dt></dl>My ultimate design has been put into PCB design and three PCBs have been ordered.  Once those are built up, I'll test this latest and final circuit design.  Note that I haven't tested this design due to the breadboarding challenges I didn't want to deal with.

<dl><dt>31 May 2019</dt></dl>With the recent sub-nano scale enhancement, I realized I'll have to add shielding and more extreme guard tracing to gain the full benefit.  Back to work on the PCB design, and I've cancelled the PCB order until the new one is designed...

<dl><dt>25 May 2019</dt></dl>The annotation numbering was changed today for the components, and the signal input 4K stabilizing resistor was changed to two resistors in series: a 3900 and a 100.  AND silk screen adjustments for better presentations.  Newest files uploaded for you.
<dl><dt>24 May 2019</dt></dl>Neither the BOM nor the sketch are updated fully for the latest circuit.  Until I actually build a board using the latest design, I won't know if it can even be done, considering soldering iron clearances, etc. so please know that. Rev. 6 PCB is being fabricated now with an expected fab finishing date of 10 June.  I've uploaded the project file and PCB gerber files for you.
<dl><dt>20 May 2019</dt></dl>Pondering done, I will utilize the ADL5315 (for pico-scale adaptation and plant level signal current creation and duplication) along with two LM334s (for programability with MCP4262s, tempco offsetting, and micro-scale adaptation needed for the REF200AU) and the REF200AU (for high impedance current-to-voltage signal transcreation).  The high impedance that the REF200AU offers is needed to maintain viability of a pico-scale signal current amongst the micro-scale operating current.  Although pico-scale signal viability may end up being wishful thinking, I'm confident from reading the datasheets that at least nano-scale viability will be within reach. 
<dl><dt>17 May 2019</dt></dl>I have decided to dramatically change the front end of the circuit in v.6 to do away with the LM334's and the REF200AU in favor of the ADL5315 if I can figure out how to convert a few nA sourced signal current to a signal voltage centering at 1.5VDC without lowering its impedance into oblivion (where oblivion happens to be the very range of the MCP4262s that I'm using :-().  However, I've already ordered boards to be made at the v.5 level, and those boards will be delivered in a week or two.  I'll probably build them out as my reference point while I ponder...

<dl><dt>10 May 2019</dt></dl>While we await this latest PCB to be made and sent to me, I'll explain that I do expect a certain amount of undesirable temperature effect on the circuit and I don't intend to use mathematics to predict its amount and design it away.  Instead, I'll wait and take the empirical approach to deal with that.  Suffice it to say at this point that you should try to maintain an unvarying temperature on the circuit board during operation until v.6 of this project.

<dl><dt>09 May 2019</dt></dl>The still untested v.5 circuit board design is here: https://github.com/kenneth558/plant_resistance_primary_perception/blob/Free/embeddeds/v.5%20training%20aid%20board%20gerbers.zip.  No further circuit changes after that should be expected until I decide how to incorporate temperature compensation based on experimentation with v.5.  Alternately, I may decide to incorporate the ADL5315 in v.6 to replace the two LM334's and REF200AU.  Regardless, v.5 PCB version contains helpful construction-time diagnostic capability for helping the person building the board to catch any soldering mistakes (shorts and opens) early enough to repair them without having to remove umpteen other components that would otherwise block access to the soldering mistakes that will be inevitable sometime, somewhere.  This PCB version also contains an untested sensitivity enhancement which can be jumpered out of operation in case it ends up not being viable.

<dl><dt>26 Apr 2019</dt></dl>As of 26 Apr 2019, I have not gotten any PCB rendition of this circuit working, plus I've decided to incorporate additional circuitry onto the board which will enhance sensitivity to a more reasonable capability. The board space that the additional circuitry uses forces me to use SMD much more, thus requiring extensive layout redesign. That board will be Rev 4. [UPDATE: V.4 design aborted due to the coming of a second enhancement that caused me to pause v.4 development] Though I personally have not gotten the circuit working with the PCB design I publish here, I do believe someone with electronics skills will be able to gain a great deal of headway with it. (I am talking about Rev 3.). I am proceeding at a leasurely pace with Rev 4 [UPDATE: v.5] PCB design.
<dl><dt>17 Apr 2019</dt></dl>My first try with MCP4262 dual dPots and a real printed circuit board is not working.  Am troubleshooting....

<dl><dt>08 Apr 2019</dt></dl>I have corrected the known errors in the printed circuit board design.  These errors were: Q1-3 body shown in silkscreen was backwards and VR1-2 adjustment directions were backwards.  I also spread apart the leads for Q1-3 and for U1-2.  The new board is designated v.3 in the file name.

<dl><dt>07 Apr 2019</dt></dl>After trying unsuccessfully to place components on my first three boards, I offer this word of advice: use low-temp solder on the MSOP packages.  I delaminated those traces on two boards while the third board is left with shorts who knows where.  Though I know the boards were subjected to higher soldering temperatures than my previous soldering jobs, I feel just the same that by paying the highest price in the world for this batch, I should have received more durable boards...thank you for bearing with the complaint.

<dl><dt>01 Apr 2019</dt></dl>Increased value of R2 from 1Mohm to 1.5Mohm for possibly a little better temperature tracking with the DUT leg.  Improved the Bill of Materials to be an interactive web page (download/offload it because GitHub won't serve it as its own web page like needs to be done for it).  May populate it later with vendors, but its main use is to track components as they are placed on the board.  Components need to be soldered lowest profile ones first so the taller ones don't get in the way of the soldering iron and burnt.

<dl><dt>29 Mar 2019</dt></dl>I added a green LED for confidence that the electrodes are connected properly.  I uploaded my PCB gerber files to here: https://github.com/kenneth558/plant_resistance_primary_perception/blob/Free/embeddeds/v.5%20training%20aid%20board%20gerbers.zip (link updated for v.5 09 May 2019).  The BOM is near the bottom of this page: https://github.com/kenneth558/plant_resistance_primary_perception/blob/Free/More%20construction%20details.md

<dl><dt>14 Mar 2019</dt></dl>I completed the PCB design and will use tomorrow to find a PCB maker beginning with local sources (a community college, a state university).  Have received most of the components to build the innards of several training aids.  When we have a couple working training aids, I will develop the best form of the rest of the training station design to include the project box. Top view of circuit board: https://github.com/kenneth558/plant_resistance_primary_perception/blob/Free/embeddeds/top%20side%20training%20aid%20extension.png  Bottom view of circuit board: https://github.com/kenneth558/plant_resistance_primary_perception/blob/Free/embeddeds/top%20side%20training%20aid%20extension.png

<dl><dt>26 Feb 2019</dt></dl>Note that the latest sketch version contains an untested feature - gain adjust via potentiometer or a 3 position switch with voltage divider resistors.  Also I have not tested any gain other than 128, and to remind you, a gain of 32 is going to require INA+/- of the HX711 to be paralleled with INB+/- of that same HX711.
I am still working on the PCB design, and until I master that, I don't foresee any other project advancement happening.  UPDATE - 14 March 2019 - still working on the PCB design in KiCad.

<dl><dt>20 Feb 2019</dt></dl>Using KiCad for making a PCB from my first schematic is SO un-intuitive for me b/c I set some traps for myself in the way I created the schematic.  Seems like I'll have to create a new schematic from scratch while I simultaneously develop the PCB with each change I make in the schematic.  This sets my expectations aback.  On another note, I'll be adding a visual and/or audible indicator to assist the operator in achieving enough conductance while placing the plant-side (upper) electrode.  If you remember, I decided that the standard electrode placement will be with the reference electrode pushed into the soil or other root-circuit substrate.  Electrically, the reference electrode can be either one during this development phase via the 4-way switch, but mechanically it will be fitted with a probe instead of the flat conductive sheets.

<dl><dt>15 Feb 2019</dt></dl>In studying the HX711 datasheet better, I understand how INA and INB (channel A and channel B inputs) are selected to be read from.  To read at a gain of 32 I simply parallel INA+/- with INB+/- and compile the sketch for 32 gain.  That is nice because the plant I attached to needed a substantially lower gain than the 128 I used for it.  Since I left channel B inputs at NC (no connection), I will have to so some soldering and schematic modifying.  Where the AD8244 buffers where paralleled, I will change the wiring to have one pair of buffers drive the INA and the other pair drive INB.  Simple as that.

One single challenge remains to me: configuring the electrodes so as to acquire high enough conductivity for the LM334 circuit to work by surface contact electrodes.  Right now, I can only achieve high enough conductance for meaningful operation if I pierce the leaf membrane with the signal electrode.

<dl><dt>31 Jan 2019</dt></dl>I've been considering what the best electrode design is to be, and I've discovered a company named ERG Aerospace Corp. that makes what they call Reticulated Vitreous Carbon (RVC) that I believe would be a fine active electrode surface. I've ordered a sample from their U.S.A. distributor, Duocel.  I'm sure hoping to obtain all subassemblies and parts from Judeo-Christian friendly economy sources, so I'm happy that this source qualifies.

<dl><dt>30 Jan 2019</dt></dl>With the higher than anticipated resistance, my plan is that one electrode will be put into the ground and the other will be placed onto leaf surfaces (multiple, if needed) so that a much greater contact area can result in a lower resistance.

<dl><dt>21 Jan 2019</dt></dl>A big Thank You! to the maker bunch at Turbine Flats in Lincoln, NE for letting me demonstrate the GWAAM-Sea training aid.  What went wrong, you would ask.  In reality, the problem wasn't exactly the electrode contact resistance, but rather the resistance through the leaves.  That plant I brought to the demo was not selected based on the necessary criteria, which would have been its electrical conductivity.  Instead, it was selected based on availability and price.  It was from a funeral of an uncle of mine last summer.  Its conductance through the leaves was just far higher than the sketch as of today is able to handle.  It remains to be seen whether its conductance is too low for the circuit with LM334 being used.  If I find out it is too low, I just may modify the bridge to use only dpots - a bit more expensive of a scenario.  My first course of action will be to invert the initial linearity calibration such that the bridge balancing begins with maximum dpot resistance rather than minimum.

<dl><dt>15 Jan 2019</dt></dl>YOU NOW HAVE THE PUBLISHED VERSION v.Free, DATED 15 JAN 2019 THAT IS FUNCTIONAL TO THE EXTENT I RAN IT.  To read about the only configuration I've run it under, see [Current Operational Status](https://github.com/kenneth558/plant_resistance_primary_perception/blob/Free/Current%20Operational%20Status.md)  Testing now has to be done to locate all bugs.  Many defunct and obsolete remnants and printed messages remain.  I do intend to add wifi connectivity and SD Card local storage in the future.  I do expect bugs to be found, but they should be very easy ones to fix.  THANK YOU, LORD!

<dl><dt>08 Jan 2019</dt></dl>I've been working hard at this, which is due to several structuring changes that needed to be made in order to allow for various enhancements.  The new structure is now complete.  Bug track-downs are next.  None of the remaing bugs should necessitate the whole scale re-writes that have taken so much time.  They should be simple fixes, but I'll take a few hours of leisure right now.

<dl><dt>17 Dec 2018</dt></dl>Taking time from sketch development in order to beef up the prototype circuit from residing on breadboard to more residing on perfboard.  I wish I had a fiberglass perfboard lying around, but all I find is phenolic.  That will have to do for now...

<dl><dt>11 Dec 2018</dt></dl>A person could wonder why I'm not providing updates more often.  There seem to be several reasons for that, one of which is that when I am in the process of investigating hinderance with the project, it may take several days for me to accurately discover down the cause.  Such is the case for the latest hinderance.  I thought I had it characterized correctly, but am having already to correct my post of a minute ago and I know better now than to even say what my initial incorrect posting was.  SIGH.

<dl><dt>08 Dec 2018</dt></dl>Sketch development is now the farthest along and working, just needing some cleanup before I put this latest version out for you.  Give me a day or so, please.  Thank you!  The sketch you will then have will be the skeletal basis for future enhancemants and expansion.

<dl><dt>03 Dec 2018</dt></dl>A follow-up to the idea of wifi capability: I believe I mention somewhere that I am writing this sketch specifically for the Arduino IDE Serial Plotter, which I am.  Connection to that Serial Plotter is unidirectional data flow, making an inherently bidirectional wifi connection a level beyond the immediate scope of development.  Not only that but the data flow also becomes incapable of connecting to the USB-only IDE plotter.  Wifi capability eventually will be part of my planned client-side development as evidenced by the fact that I've already started accommodating it by means of extensive data now being included in the outgoing data stream.  The Arduino serial plotter conveniently ignores this additional data, but a future client renderer will use it.  When I do get around to coding for the wifi, my current thinking is that it will utilize HTML5 SSE (preferred) or WebSockets (with the plant side being a web server), both of which I have not yet developed for.  Client-sent data would be via HTTP put() methods that would allow some means of operational adjustment at the plant end of the wifi connection.

My current state of development is debugging the predictive auto-adjust.  I tripped over an attempted WEMOS XI compatibility effort and have to go back over those changes I made during that effort.  All for nought, it seems, b/c I discovered the WEMOS XI has been discontinued.<SIGH>

UPDATE: Sollae Systems has developed Web Serial Plotter which uses WebSockets and integrates so well into the Arduino IDE that I would not have to code my own client-side renderer.  NICE!  The disadvantage is that my super-inexpensive ESP8266 modules will only be useful at the computer end of the wifi connection while the plant end would require a $$$ part costing more than all the rest of the circuitry combined, and I only hope their use of WebSockets over SSE is for the better.  I'm sure the PHP server is in their shield so it would be well nigh impossible to reverse engineer the PHPoc source code to emulate the expensive board at the plant end while still using the Sollae Systems Web Serial Plotter at the computer end. 

UPDATE: A more cost-effective solution would be a peer-to-peer wifi connection that down-converts the data back to USB.  Then I could use duffster's (duff2013's or duff's) more fancy ["Arduino Serial Plotter 2.0"](https://www.esp32.com/search.php?author_id=6107&sr=posts), if it will be made available.

<dl><dt>30 Nov 2018</dt></dl>Thanks to Brook for suggesting that I add wifi connectivity, SD Card storage and a means of plotting plant growth.  On attempting to include to first two, I've found RAM limitations could be a serious challenge with boards only having 32K RAM or less.  The plant growth idea may not even need to connect into the Arduino, if it could be a standalone video camera.  Unidirectional growth upward might easily be included, though.  I don't plan on offering any of these enhancements in the free sketch version.

<dl><dt>16 Nov 2018</dt></dl>Scalability changes made to the sketch.  DO NOT USE PREDATED VERSIONS TO ADVANCE DEVELOPMENT!!!!!!!  Many changes have been made as of this date to accommodate future scalability.  This specific upgrade effort has been what has kept me busy lately.  Had I not done this, I couldn't have improved the sketch beyond the very unimpressive level it stalled at.  There are still places that need attention, but I needed to get this scalable style out here for community involvement.  Somewhere along in the process I lost indenting, in case anyone would like to take that on as a little project.  Just fill out an Issues entry so we don't get multple people on that one project.

<dl><dt>2 Nov 2018</dt></dl>I'm rebuilding my prototype circuitry to improve robustness, considering that I'm traveling hither and yon with it.  I've made more progress with sketch transition, but there is still more to do with it.  The sketch posted in the base sketch directory here on GitHub is still as far along in performance as any version I am working on locally.

<dl><dt>22 Oct 2018</dt></dl>Using the 20 Sep version to regain functionality, I'm taking smaller, baby steps to expand the sketch.  My current goals are 

- to allow for use of less than 3 and more than 3 DPots/leg
- to allow for using DPots without LM334 in bridges
- to allow for using unbridged DPots
- to allow for multiple HX711s
and, of course
- to allow for faster conductance range changes when DUT conductance goes out of range.

In the meantime, I have coded a new pre-processor macro PLOT_ONLY_THE_SIGNAL_LEG_OF_SUPERIMPOSED_DPOT_LEG_BRIDGE_INBOARDS to suppress the reference plotlines of superimposed traces.  Using this macro, however, may alter the intuition behind specifying how many inboard lines are to be plotted.  I'm not concerned at all about that probable disconnect from intuition, since it is only a matter of very little experimentation for you to determine how many inboards to plot if you use the new macro.  Specifically, if you define this new macro in your compilation while superimposing bridged traces, fewer traces will be plotted than specified by the NUM_OF_INBOARDS_PLOTTED is defined for.  If this becomes confusing to users, I can consider changing it in the future.  It works great as is, so I'm moving on to the other goals in the meantime.

<dl><dt>11 Oct 2018</dt></dl>There was something to be said for the 20 Sep 2018 version even though it auto-adjusted slow.  At least it auto-adjusted whereas changes since then have never worked as well.  Am reverting back to 20 Sep in the auto-adjust respect only and re-publishing with other modifications included that do work fine.  Hope to finish this publish goal today....
<dl><dt>06 Oct 2018</dt></dl>Sketch versions dated today and later will now accommodate the dual pot version of MCP42xxx.  The way the second pot in the package is controlled to that its pin number will have the pin number of first pot in the package OR'd with a hex value of 40 (0x40) as being the pin number for the second digipot in the package in the defines section of the sketch right where the digipot pins are currently defined.  

<dl><dt>04 Oct 2018</dt></dl>Its been very slow progress in recent days as I realized the sketch needed an overhaul to its inter-function flow to remove some algorithm duplicates when I found it overly difficult to get the bracketing within the code correct.  Better to deal with it now than later.

One function to debug, then sketch will be published in beta test mode.  That function is labeled with an #error preprocessor directive for ease of locating.
<dl><dt>20 Sep 2018</dt></dl>Breakthrough with the software today.  I'll post the latest code and begin working on the electrodes aspect of the project.  It has non-predictive auto-adjust on the digipots and thus an auto adjust takes quite a bit of time.  I think the free version will stay that way.
<dl><dt>19 Sep 2018</dt></dl>Still working on this.  I'm suspicious of my breadboard connections being intermittent.  I will resort to soldering things together on a perfboard for increased robustness.
<dl><dt>16 Sep 2018</dt></dl>I'm able to dedicate more time to finishing this project now.  I need to give it the ability to auto-adjust to the widest range possible of operational conductance levels.  Up until now, I've only been getting the project to function  with the DUT being a fixed 1Mohm resistor, which now works very well in itself but is not very practical working with conductances other than 1Mohm.  Obviously, you can't expect a plant to be exactly centered on that value, so I'll be working on that now...
<dl><dt>26 Aug 2018</dt></dl>In the sketch, I've laid out the direction for the new array concepts in self-documenting macros.  If you compile the sketch, it will stop at an explicit preprocessor error line stating as much.  The rest of the sketch next needs to be brought into compliance with the macros as they are aptly named.  This new array concept should at last bring the sketch into a bug-free and useable state.  After a good night's sleep...
<dl><dt>26 Aug 2018</dt></dl>The sketch bugs I have been struggling against have been due to me wanting to develop in too straight of a course in that some arrays are made too multi-purpose and have indices that are too different, both from each other and in the various possible configurations.  That approach lends itself to too complex of troubleshooting.  I am breaking out those arrays into smaller, more specifically named dedicated arrays with more specifically named indices and macros/variables specifying their sizes simply to speed up sketch development.
<dl><dt>24 Aug 2018</dt></dl>Bug found relative to displaying multiple traces while one or more are from inboard analog pins in combo with magnified and who knows what.  I am forced by the reality of things to strongly suggest that  until this sketch has been bug-free at the latest revision level for at least three or four weeks, all potential users just hold off unless you are prepared to fix my sketch bugs.  Sorry.  The current "bug" might instead be circuit malfunction, but until I finish troubleshooting, I don't know.
<dl><dt>23 Aug 2018</dt></dl>Added ability to reduce the magnification via a pot connected to a spare analog input pin specified with a new preprocessor define POT_WIPER_TO_THIS_ANALOG_INPUT_PIN_TO_ADJUST_MAGNIFICATION_FACTOR.  Fixed all known bugs, specifically with magnification trace plotting.  One thing left to code is auto-adjust when readings go off-scale.  Code for this is commented out right now.  It will use preprocessor macro LOOP_COUNTER_LIMIT_THAT_TRACE_IS_ALLOWED_TO_BE_OFF_CENTER.  I have decided that the 10K digipots are better off being 5K instead.  Ordered new ones.  A few lines of code will have to be changed to use the lower values by adding 10 to some rollover literals.
<dl><dt>22 Aug 2018</dt></dl>I'm able to code periodically.  When I changed the plotting algorithm to handle larger values it generated a bit of required coding time that I'm in the middle of.  I also purchased a few 74LVC138 decoders to allow more digipot banks.  They should arrive today thanks to Arrow's free overnight shipping.
<dl><dt>10 Aug 2018</dt></dl>A number of non-project tasks have arisen that I need to place in higher priority than this.  Expecting nearly a month delay...
<dl><dt>02 Aug 2018</dt></dl>Not a memory management problem but is a casting problem: The print command won't print ( long long ), (long) is the closest it can get, and when casting down to a (long) is loses value.
<dl><dt>31 July 2018</dt></dl>I've noticed one sketch bug in the printing of the magnified traces in that they don't stay within bounds any more.  Older sketch versions never had that problem.  I'm not sure where it began, but it seems to be a memory management problem from my inital troubleshooting rather than any type of algorithm weakness.  I'll work on that when I'm able...
<dl><dt>29 July 2018</dt></dl>I finally feel confident in the condition of the sketch.  I have corrected all bugs that I've ever found in it and have it completed to a useful level.  I recommend using it with two LM334s in the Wheatstone bridge input stage - one LM334 in the positive half of each bridge leg.  Each LM334 in turn has its current controlled by three digipots in series - two MCP4162-104 and a MCP4162-103.  Note that the two MCP4162-104s may be able to be replaced by a single MCP4262-104 instead, but I have not tested that idea.  I would also recommend yet another resistance in series with those three to prevent too low of a set resistor value if the digipots associated with an LM334 should all get set to zeros (very likely considering I've not prevented endless loops).  Which tells me that there is still some sketch work to do relative to handling specific failure or over-limit conditions that can arise.  For now, though, I have other projects needing my attention.

I also recommend using an AD8244 if you can solder tiny things.  Perhaps I'll eventually employ small toroid inductors in series with the LM334s, but the noise level right now looks low enough.

To take the sketch operationally (the code will never be elegant in appearance) to a professional level, I will need to handle the input voltage level tracking on the electrode from the plant.  I say voltage but you do realize, I hope, that the voltage level is simply produced by the Wheatstone bridge and it correlates to a plant resistance.

Eventually, I'll get a schematic published for you.
<dl><dt>18 July 2018</dt></dl>My two HX711s read differently from each other, so I'll have to order two more.  Expect them no earlier than 30 July, costing me $3.03 due to added shipping cost to get them that early.  Until they come I'll work on repairing the differential conversion algorithm for negative 24-bit values, at least for two's complement ADC libraries like the HX711.
<dl><dt>17 July 2018</dt></dl>AD8244 arrived at 09:07.  Nice!  However, it's MSOP pin spacing is well less than SSOP.  I had to spread the pins a little bit to solder it onto the SSOP adapter board I had on hand.  Initial power up indicates I have a wire misplaced, but this is too late at night to continue today.  Tomorrow I would do well to focus on the garage roof instead of this project.
<dl><dt>16 July 2018</dt></dl>Since I conclude that buffers like AD8244 will be needed in any case, the Wemo XI Analog Inputs and ADS1x15 become just as viable as any other ADCs.  I will change comments in source code to that effect.

Received notice that my AD8244 has been shipped with overnight expidite, no extra charge.  ETA tomorrow, by 4:30pm.  Thank you, Lord!
<dl><dt>15 July 2018</dt></dl>Just discovered the HX711 input Z is way too low.  The datasheet hadn't specified it in any way, nor would I have deduced the implications anyway.  Regrouping...will need to use High-Z buffers (AD8244 or equivalent) or a different 24-bit ADC as the base device.  Ordered a AD8244....
<dl><dt>08 July 2018</dt></dl>My efforts continue to be sidetracked by the urgencies of property maintenance and repair.  My mower has broken irreparably, and with zero income, I haven't the money to do anything about it other than mow my lawn with a hand-held string trimmer.  I had to fire the crew that was repairing my garage due to their admitted inability to pass a drug test after I had been dismayed with their poor workmanship.  City hall has verbally indicated that the city is eyeing my property as being on the verge of getting written notices, only three which are allowed before city action to de-blight.  A realty company is having a hard time seeing a win-win path for me to sell due to the cost of fixing the house and garage.  

In light of all this, It would be irresponsible of me to work on this project at the expense of my house.  Progress on this telempathic gardening training aid, therefore, can be expected to be minimal for months to come.

<dl><dt>28 June 2018</dt></dl>My efforts have been sidetracked for some days by the urgencies of property maintenance and repair.

<dl><dt>20 June 2018</dt></dl>I had assumed the excitation voltage from the HX711 across the bridge circuit would be higher than it is in reality.  I though it would be high enough to include headroom for LM334s to operate in the upper halves of the bridge.  Not so.  The positive excitation voltage is less than 2.5 vdc using the high impedance scenario with the plant.  Not only that, but the negative bridge power is about a diode drop above ground.  I will have to supply the bridge from +5 and GND and see what that does to the noise floor.  Datasheet for HX711 says to supply less than within .1 vdc of Vdd, so I am risking a $1 part here...

<dl><dt>19 June 2018</dt></dl>I received the correct digi-pots and should be able to work on this project after I get some yard and house work done.  I added a .png screen shot file of a comparison between one inboard Analog Input vs. HX711.  Note that LM334s are being used as the top component of both bridge legs.  That will be a standard inclusion in the circuit hereafter.

I am still unsure of the 24-bit differential non-magnified display amplitude.  It seems far too insensitive because it should max out with a 20mV tweak up or down, and I don't see it maxing out at all.  I'll investigate.  The good news is that this is nothing more than my suspicions of display amplitude of the lesser important trace, so I'm not declaring it a bug and especially not a real problem.

<dl><dt>17 June 2018</dt></dl>[OBSOLETE:Since the Wemos XI/TTGO XI and maybe other boards have worthless Analog Input pins, yet] two full-scale input pins connected to the two bridge compare points can be very useful when a 24-bit high sensitivity load cell ADC is used, I am contemplating how to change the sketch to accommodate, not just one, but two add-on ADCs.  This will also enable the sketch to be used with micro-controller board without any Analog Input pins, and ARM micro-computers (which have no Analog Input pins).  The alternative of using an analog buffer for the Wemos/TTGO would not be scalable to boards that have no Analog Inputs at all. I envision one of the add-on ADCs to be a full-scale ADC used for digital potentiometer setting to balance bridge legs and the other ADC will be the high-sensitivity ADC for magnified display.  The full-scale ADC levels will only be displayed when DEBUG_BRIDGE_BALANCING mode is defined.  The inputs of both ADCs will be in parallel, so both must be high impedance.  Note that the ADS devices are indeed full-scale and inexpensive, but they are not truly high-Z.  

In my datasheet research, I am finding that inexpensive ADCs like the ADS1x15 in general undesireably make the source (the plant in this case) charge a S/H capacitor.[This point is moot if you just use an AD8244]  I'll investigate the ramifications of that after I get the digital potentiometers working to track and autobalance. 

I continue to be encouraged as I learn that most people I talk with pseudo-randomly accept the premise on which this project is based.  I really didn't use to think the acceptance level for telempathic horticulture was that high.  I'd say the time is finally right for this!

<dl><dt>15 June 2018</dt></dl>Received four MCP4162-103E/P instead of four MCP4162-104E/P...I've made the same mistake again!!!  Ordering again.

Using the MCP4162-103E/P that I had, I learned how to address two of them in case I need a second one in circuit for finer adjustment.

<dl><dt>08 June 2018</dt></dl>Had to re-order the programmable potentiometers due to the resistance value of 100 kOhm not being available from Chinese site, forcing me to order a 10 kOhm value that will require a series resistor and limit the adjustment range.  I must have gotten interrupted during that shopping effort and forgot to continue.  Will do what I can with the one I got and ordered from a stateside supply house for $5 shipping instead of free or pennies.  Upside is that I may receive the order in a week or two.

<dl><dt>05 June 2018</dt></dl>HX711 now supported...you'll have to balance the bridge yourself, though since my programmable potentiometer hasn't arrived.  Use a SAMPLE_TIMES of one.  I only tested with PGA A at default gain of 128.  This is a sensitivity breakthrough, since this little ADC converts a swing of a mere few millvolts into 24 bits compared with the ADS1115 converting rail-to-rail swing to 15 bits.  The ADS1115 sensitivity doesn't hold a candle to any ADC with a full-scale conversion range in the millivolts.  The library to use with HX711 is https://github.com/bogde/HX711  

I haven't completed constructing a satisfactory electrode subsystem yet...

<dl><dt>04 June 2018</dt></dl>Home maintenance issues are taking much of my time away from this project.  I am trying to develop a method of holding the electrode assembly against the leaf and keeping a good seal.  In a shopping trip to Menards-type and Walmart-type stores, I put together a few items to try various methods.

My programmable potentiometers haven't come in as of yesterday.  They are important for getting the HX711 going.  Otherwise, the only differential input devices I can support are those that have a full-scale range of near-rail-to-rail.

<dl><dt>29 May 2018</dt></dl>Considering supporting AD7780.  Looks like a good value 24-bit ADC for full-scale differential input...  ADS1242 as well.

<dl><dt>29 May 2018</dt></dl>Decided I will need to support the ADS1231 as well. The HX711 will be difficult due to max scale occuring at 0.08 volts or less, and I feel that will be wishful thinking at best to insist on that close of a match between A0 and A1 legs in the lay person world besides dealing with the noise from all sources and junction contacts at that amplification.  Considering LTC2400, AD779x and MAX112x0.

<dl><dt>28 May 2018</dt></dl>I realized the advantage of reading differential when using the LM334s.  When I get differential reads working it will allow use of 24-bit load cell-type ADCs.  I have two 24-bit HX711 on hand, so the project will eventually additionally use HX711.  I expect first or second  week of June will see this project working with differential while still keeping the capability for single-ended.  I have secured domain names for "reviving civility" and "telempathic horticulture" which point here where they will remain pointed until I get a better page built.

<dl><dt>19 May 2018</dt></dl>I received the LM334 and tested the noise level with and without it.  I am pleased to say that the noise level IS lower when that part is used in the circuit as the source of the current going through the plant signal electrode.  However, in my efforts to investigate into more detail, I discovered that the ADS ADC I was using is exactly what I ordered - an ADS1015.  That means it is only a 12-bit ADC, and I want the 16-bit ADC for greater resolution.  Work on this project will therefore be stalled until my newly-ordered ADS1115 arrives in a couple weeks (I paid $2.35 extra for expedited delivery this time).  24 May - ADS1115 arrived, but unable to work on it for a few days due to being out of town for an extended family gathering.

When I was testing with the LM334, which alternately is a temperature sensor, the temperature drift was too overwhelming to work without temperature compensation.  Temperature compensation is provided by a silicon diode and two resistors (instead of one) setting the current.  Those two resistors must be of an exact ratio to one another to cause the proper portion of the diode's temperature coefficient to exactly offset the LM334's opposite temperature coefficient.  Since I'm not going to force myself to buy the specified diode that provides exactly -10 times the LM334's temperature coefficient, and with programmable potentiometers available (AD5242 and MCP41100) I don't need to, I'm just going to use a common diode such as 1N4148/1N914/1N4000 and write Arduino code that will proportion the resistances correctly for whatever diode is in the circuit and store that as a calibration in EEPROM.  Writing that code will add another week or more because I'll need to have the right conditions drop into my lap to get the time and conditions to work on it.  (Note to myself: the 1N457 has/had a tempco of -2.5mV/C while a 1N4148 might be anywhere between -2mV/C and -2.5mV/C, a 1:7.8 vs. 1:10 resistor ratio.)  UPDATE - I intend to forego the diode idea in favor of software compensation ujtilizing a second LM334 circuit sending a temperature driven analog signal to a second analog input.

I am unable to find programmable pots of sufficient resistance to directly utilize the zero tempco circuit as presented in application notes, so I will have to try variations on that theme.  Add more days/weeks to the tempco effort with an as yet unpredictable outcome.

When I've finished these tasks, I hope to offer a good estimate of how much better the LM334 is than just using a resistor to supply the current to the plant.  I expect to find that the use of an LM334, two programmable potentiometers, and a diode or so will actually be indispensible to use in place of a simple series resistor to the signal electrode.

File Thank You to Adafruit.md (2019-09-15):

Thank you, Adafruit, especially for being open-minded toward the reality of the phenomenon:

>Whatever you think of the phenomenon, the fact is that something *is*  happening, we just don’t know what (yet).

from
https://blog.adafruit.com/2018/04/23/primary-perception-and-the-arduino-code-to-measure-it

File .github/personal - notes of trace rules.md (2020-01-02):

When laying out the PCB - 

1. This rule philosophy replaces the notion of having vertical traces on one side of the board and horizontal traces on the opposite board side.  The added advantage is that it allows for better filling of zones [planes].
 -  Long runs across board:  
Any scenario where other yet-to-be-laid-down runs might need to cross current run, weave the trace repetitively from one board side to the other throughout length of travel.  Each stitch should be long enough for one or several cross-directional traces to run side by side each other "underneath" the stitch.
The aforementioned scenario does not and cannot exist along board edges and along the sides of shields and pads of other components where those pads are of longer lengths.  Such regions can be great places to run traces, but do NOT weave them running past and alongside those pads - keep the new traces on one board side or the other for that entire distance so that the other side of board is totally free to be used for an exact replica (you can't place any vias along these traces without making the other board side non-viable for passing traces, so avoid placing vias alongside the aforementioned edges and extended length pads).  
Similarly and for the same reason, avoid any weaving at all alongside even a short pad while circumventing that pad.
 -  During weaving of multiple adjacent traces, maintain synchronous stitching so cross-directional traces don't get blocked.
 -  Weaving may not be feasible under shields for sensitive runs or maybe even at all because the traces would then be leaving protection of the shield for every other stitch and/or compromising the continuity/integrity of the ground plane.

2. Under shields that are used or can be used in any sense for hermetic sealing, try to place all vias within pads so they get solder-sealed when components are placed.  Unless you are agreeable to using solder mask as the sealing material, any vias under a shield and not located in a pad need to be given the extra attention of getting the solder mask removed on the opposite side of the shield, at least, where it can be solder sealed even after the shield gets placed.  Better is to remove the solder mask on both sides so that molten solder during sealing has a chance of reaching into the interior of the via without there being solder mask material that got applied from the other side to stop it.  Note in KiCAD that placing a solder mask graphic means it blocks solder mask rather than applies it - just a little non-intuitive tidbit to remember.

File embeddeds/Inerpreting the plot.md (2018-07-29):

Below is a screen shot of a trace from an ADS1015 configured as single-ended by virtue of HighestBitResFromAddonADC being set to 11 (that's 11 bits of resolution).  The sketch was compiled for no analog pin connections and one ADS1X15 connection.  That ends up being two traces because one is unity scaled (blue) and the other is magnified (red).  This screen shot being of an older sketch version, the third line that appears at full-scale half the time and at the bottom the other half the time is simply the time and scale marker.  The color legend in the upper right corner of the image shows the three line colors in the order that the sketch sends to readings to the plotter monitor.  Both the unity-gain trace of any particular signal and the magnified one of that signal will show up in the color legend adjacent to each other with the magnified trace being the second one.  In the most recent sketches, the first color in the legend is now the time and scale marker.  No other color control nor labeling is allowed by the IDE - nothing can be done about that without the IDE getting upgraded.

The setup uses a 1 Mohm resistor and a red bell pepper plant almost fresh from the store with the reference electrode poked into the very wet soil.  I tried for only a moment to convince the plant to show a response, but I'm not at all confident that one electrode in the soil is the best way of connecting the electrodes.  I'll try to determine the best way with more experimentation.  I DID notice that the whole arrangement has polarized conductance.  That means that it is very likely going to matter which electrode goes to which of your two chosen electrode locations as to whether you may even be able to see a response, but the polarization might instead originate at dissimilar materials junctions as it does in a semiconductor diode between the bipolar (negative doped and positive doped) layers.

You will notice that the blue unity gain line appears almost perfectly halfway in the range for that pin.  That just happened to work out with the 1 Mohm resistor.  Frankly, I was surprised that it worked out like that since that was the first resistor value I tried!

Why all the noise?  I haven't investigated that, yet, but I was VERY lax employing any noise filtering practices for this trace.  I have an LM334 on order to remove power supply noise, and I'm thinking I'll just wait until that part arrives to worry any more about it.  If its not power supply noise, it could be noise on reference ground or environmental electrical noise induced into my wires, maybe even from a cell phone or wifi device.  If it were more random, I would have suspected loose connection[s] somewhere.  If it shows a very regular pattern, it likely indicates aliasing with a radiated power line, cell phone, wifi device or radio signal.  Coax for the electrode leads may be in order, but allow for easy polarity swapping as close as possible to the plant end of the leads so that the shield can always remain connected to signal ground.  That can be done with a four-way light switch at the plant end of the coax.  Regarding noise mitigation, read my document offering more construction details.
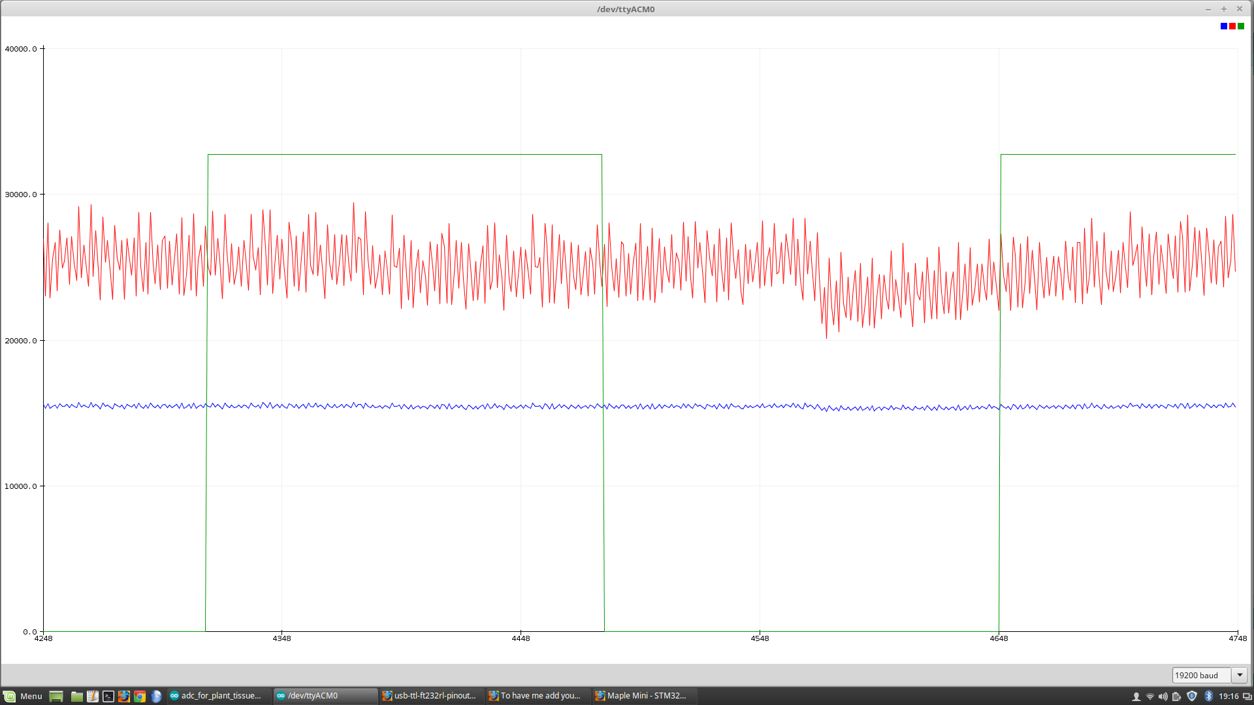
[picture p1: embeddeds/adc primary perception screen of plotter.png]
Image of plot line from my setup using a 1 Mohm resistor and a red bell pepper plant almost fresh from the store with the reference electrode poked into the very wet soil


BE SURE TO UNDERSTAND THIS: The _vertical positioning_ of the _magnified_ trace has no meaning...it is just at some height that the run-time calculations decided it would duly locate within the max and min scale for that pin.  **_When the signal deviation would cause the magnified trace to print outside it's linespace bounds, the height of the magnified trace will get adjusted so it will continue to appear in bounds._**  When this happens, the trace is continuous (and there's **nothing** we can do about it) so it appears as a spike all the way to the repositioned point. The [preprocessor macro] definition REPOSITION_RATIO_OF_MAGNIFIED_VIEW_WHEN_LIMITS_GET_EXCEEDED provides you with a way to have some flexibility repositioning the magnified trace back into the range when it would otherwise extend beyond an upper or lower limit.  Yes, we all do wish that the time-past part of the line could get height-adjusted right along with the time-future part of the line, but alas, the IDE provides no way to do that.  If you don't understand this, it can contribute to much confusion about the spike artifact appearing in a magnified trace that may be getting repositioned ad infinitum.  To avoid being confused you need to mentally remove the [almost vertical] retraces and mentally paste the true signal movements together to understand what the magnified trace is really telling you.  

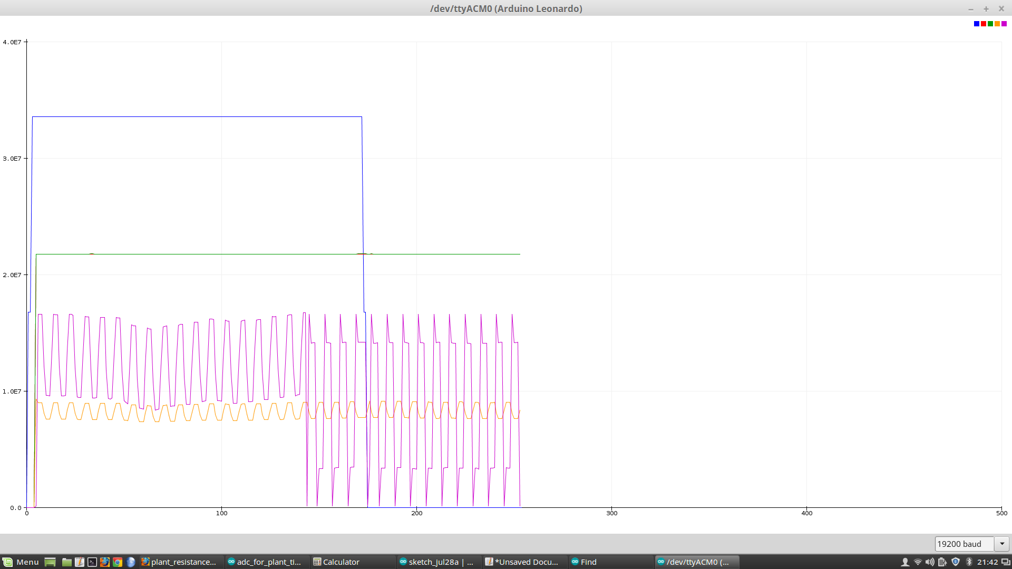
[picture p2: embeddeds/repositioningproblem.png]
Known repositioning issue
Below is an example of the POTTESTWOBBLENEGATIVE signal riding on the magnified trace but getting repositioned in the linespace (a few seconds into the plot) to cause the issue I'm trying to describe.  The two parts of the magnified trace look different from each other but are really the same on either side of the reposition point:If you're wondering about the orange line, it coincides almost exactly with the green one; hence, it is rarely visible.
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

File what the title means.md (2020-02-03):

Jesus taught us to pray "Thy kingdom come, thy will be done on earth as it is in heaven."  It is difficult at best to know what heaven culture is without REVELATION by God to us.  God is in the business of revealing to us what He wants us to know.  I believe He wants us to know what Heaven culture would look like so we don't fight it when we see it.  God uses a few different revelatory techniques for this.  The one He calls "more sure" is written revelation that He inspires.  The Bible is widely recognized as the primary means of that more sure level of revelation.  Near death experiences (NDEs) are another revelatory technique, but at a less "sure" level, as are direct
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

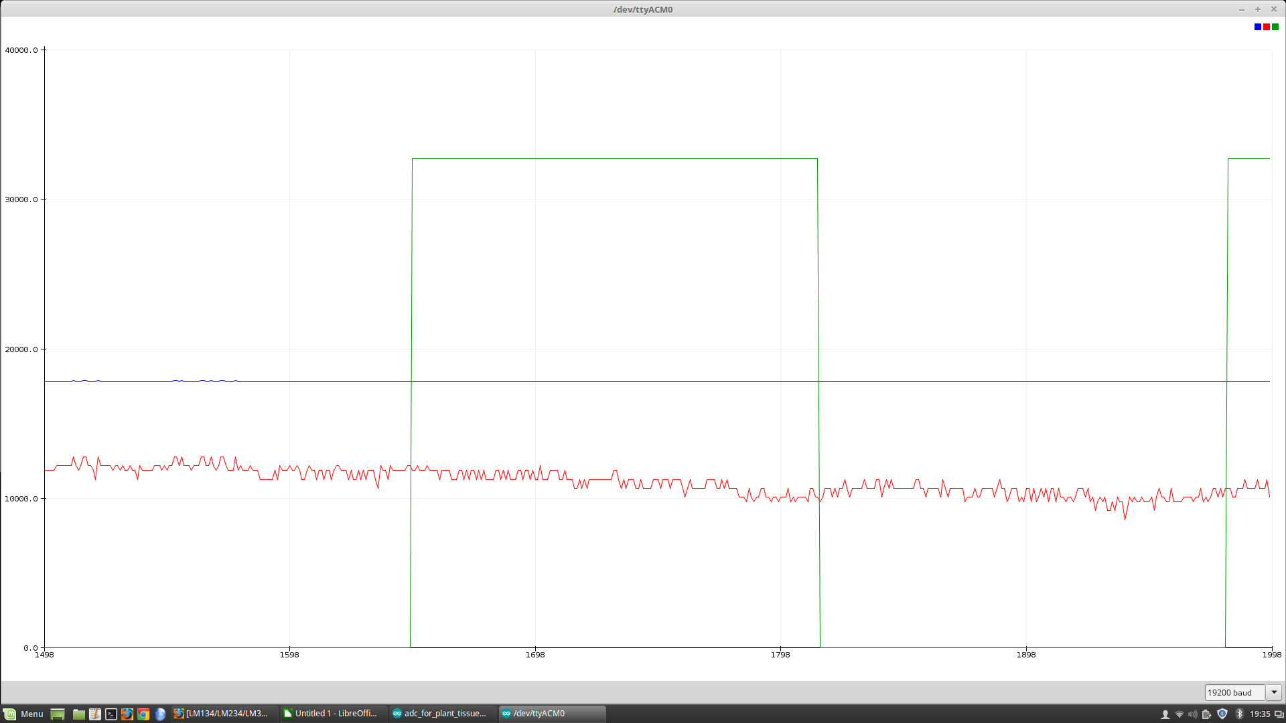
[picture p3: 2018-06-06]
embeddeds/with lm334 mag=300x.png

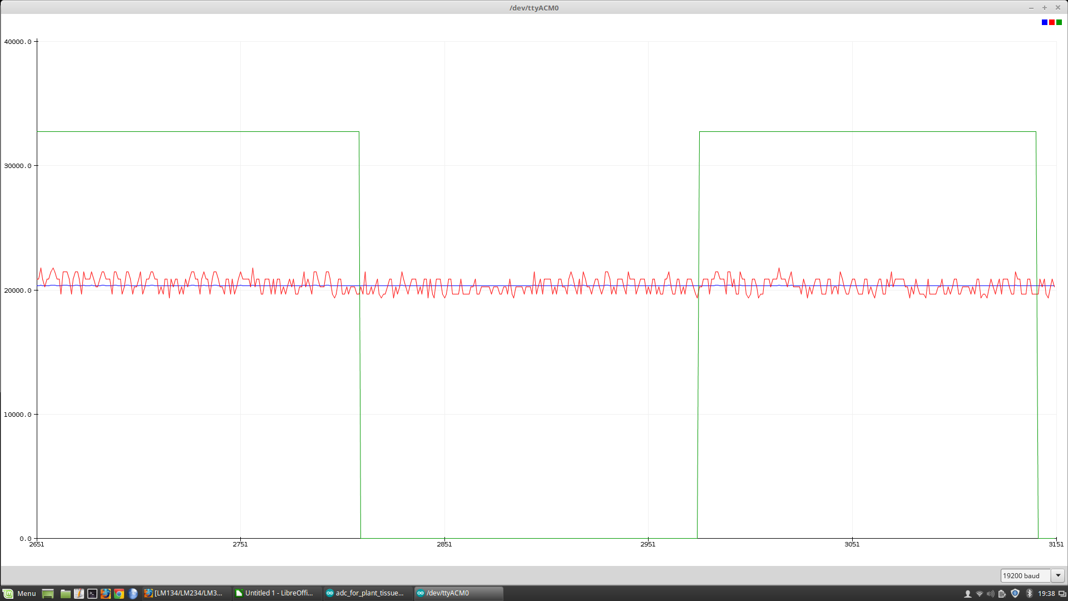
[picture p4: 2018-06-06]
embeddeds/1mohmR mag=300x.png

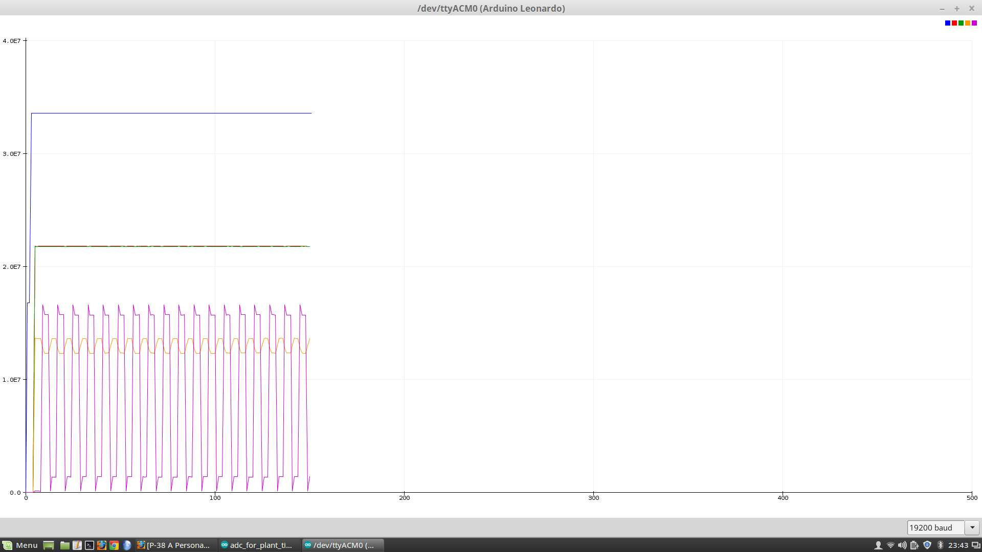
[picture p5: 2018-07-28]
embeddeds/out_of_sync_mag_factor_vs_reposition_ratio.png

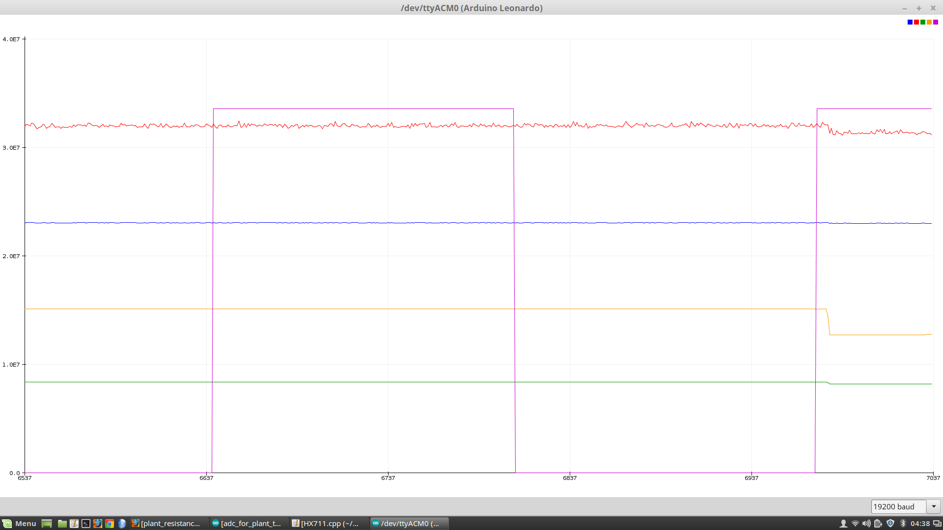
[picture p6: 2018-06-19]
embeddeds/One_inboard_analog_one_HX711_resistor_added_magnification_12.png

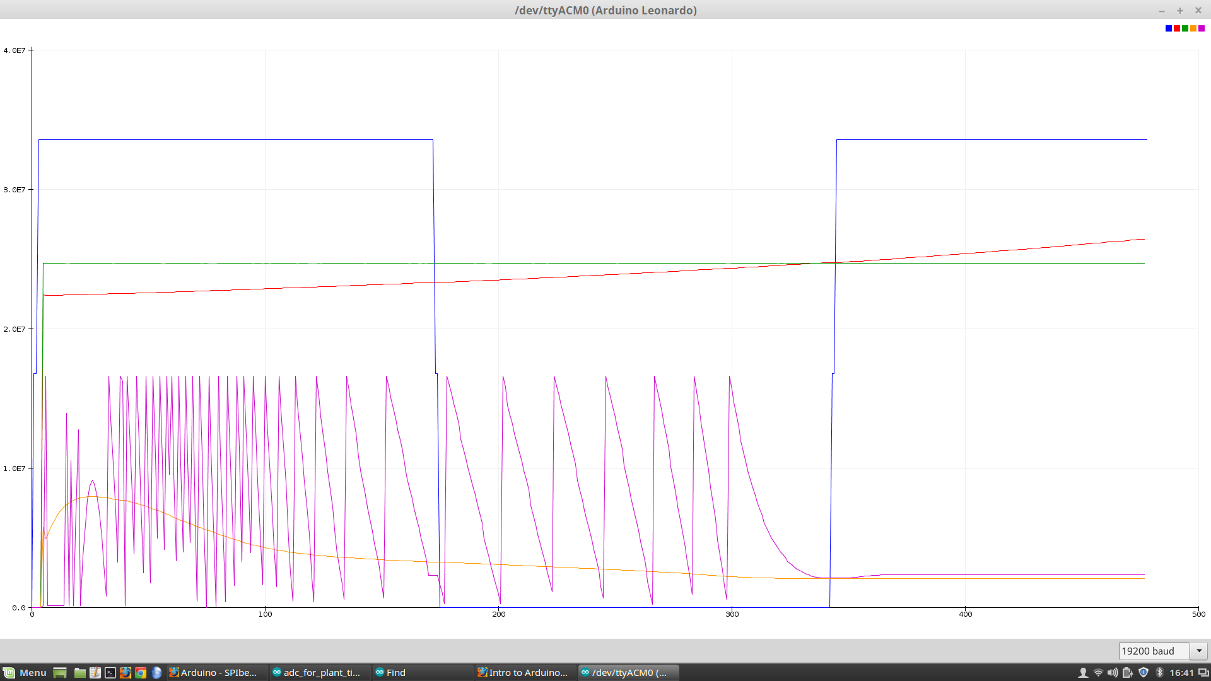
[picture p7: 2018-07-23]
embeddeds/POTTESTSTEPUPDOWN.png

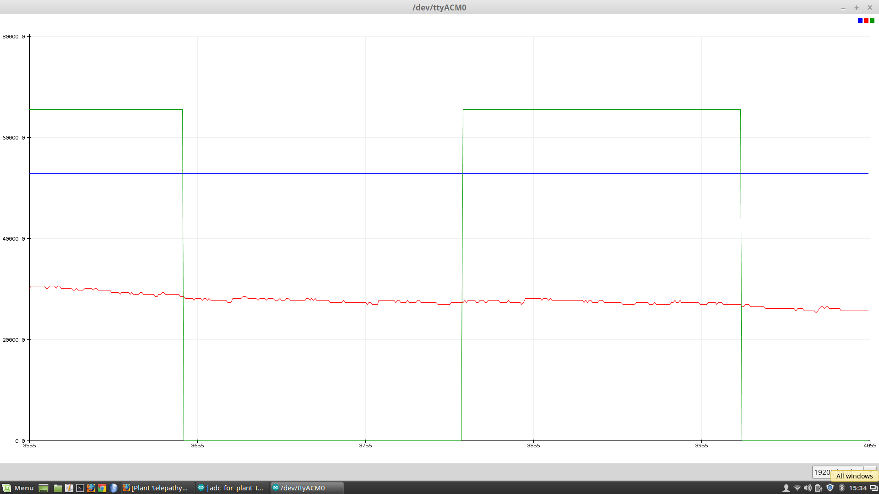
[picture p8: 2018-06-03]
embeddeds/Differential (16-bit) ADS1115 with two LM334s feeding two 1Mohm instead of plant 400x magnification.png

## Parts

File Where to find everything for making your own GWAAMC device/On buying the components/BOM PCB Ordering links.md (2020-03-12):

### PCB Gerber files - you'll need BOTH boards
##### Here is a link to the main board gerber files of my PCB design: 
https://github.com/kenneth558/plant_resistance_primary_perception/blob/Free/Where%20to%20find%20everything%20for%20making%20your%20own%20GWAAMC%20device/Files%20you%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.  

The PCB project is also published by OSH Park PCB fabrication here: https://oshpark.com/shared_projects/258j1Ml9.  They would appreciate your business if you're going to buy the gold plated board (ENIG) only.  Board 2 of 2 is linked below.

##### Here is a link to the auxiliary board gerber files:
https://github.com/kenneth558/plant_resistance_primary_perception/blob/Free/Where%20to%20find%20everything%20for%20making%20your%20own%20GWAAMC%20device/Files%20you%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

Aux Board 2 of 2 at OSH Park all ready to order without having to upload files:
https://oshpark.com/shared_projects/kbQQkkZ4

#### *NEW!* [Main and aux board in a single file](https://github.com/kenneth558/plant_resistance_primary_perception/tree/Free/Where%20to%20find%20everything%20for%20making%20your%20own%20GWAAMC%20device/Files%20you%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) gerbers and stencil.  Boards are single piece until you separate them...and carefully.  [OSH Park combined project page](https://oshpark.com/shared_projects/GQtCN367)

### PCB Comparison sites
##### Printed circuit boards can be ordered from any one of a multitude of fabricators.  Compare between fabricators by visiting one or more of the fabricator comparison sites like https://www.pcbdirectory.com/get-quotations or https://pcbshopper.com or read the fabricator site collection list at https://www.eevblog.com/wiki/index.php?title=PCB_Manufacturers or search "online pcb quote".

I would encourage you to order RoHS (environmental friendly) wherever you're given that option, paying a very slight extra to do so.  Especially if you appreciate me making these plans freely available and so plan to send me your excess.
### BOM
https://github.com/kenneth558/plant_resistance_primary_perception/blob/Free/Where%20to%20find%20everything%20for%20making%20your%20own%20GWAAMC%20device/On%20buying%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.  Sorry for the inconvenience about how this file is viewed - it cannot simply be clicked on.  It must be offloaded from GitHub because Github doesn't serve it to your computer as a simple web page.

RELIABILITY NOTE:
OUR MANY YEARS OF EXPERIENCE DATA ACCUMULATION INDICATE
THAT SOLDER HEAT IS A MAJOR CAUSE OF EARLY AND FUTURE
FAILURE.  PLEASE PAY ATTENTION TO YOUR SOLDERING PROCESS.

Despite the grammar fail, you'll do well to take to heart its meaning, both for components and the printed circuit board.

### BOM Comparison sites
https://www.findchips.com/search/
AliExpress   https://www.aliexpress.com
Arrow https://www.arrow.com
Mouser https://www.mouser.com
Digi-Key https://www.digikey.com
Jameco https://www.jameco.com
Newark https://www.newark.com/
eevblog Wiki article https://www.eevblog.com/wiki/index.php?title=Component_Search_Engines
 
###  If you end up ordering excess parts and circuit boards and you appreciate my efforts at making these plans available for free to you, I would appreciate donations of your excess.  Please open an "Issue" to ask me for address.

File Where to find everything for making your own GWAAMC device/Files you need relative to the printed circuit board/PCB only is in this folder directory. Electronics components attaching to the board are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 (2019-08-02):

[Click this if you're trying to see the components that attach to the PCB, or even the ones that don't](https://github.com/kenneth558/plant_resistance_primary_perception/tree/Free/Where%20to%20find%20everything%20for%20making%20your%20own%20GWAAMC%20device/On%20buying%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)

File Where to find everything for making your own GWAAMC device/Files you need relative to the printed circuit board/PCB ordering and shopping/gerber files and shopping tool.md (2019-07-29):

### PCB Gerber files
##### Here is a link to the gerber files of my PCB design: https://github.com/kenneth558/plant_resistance_primary_perception/blob/Free/Where%20to%20find%20everything%20for%20making%20your%20own%20GWAAMC%20device/Files%20you%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.  
 While I really like ENIG as it provides a nice flat surface for easier placement of fine pitch components, on tiny pads you'll need to "wash" the pad by double-tinning the gold off or gold migration will make the solder brittle.  Tinning, double or otherwise, negates the whole reason in getting a flat surface, so the PCB design includes place-assist holes to help hold fine-pitch components in place during soldering.  Whether they'll serve the purpose remains to be seen, but if they do, you should be able to order HASL boards instead of ENIG.

### PCB Comparison sites
##### Printed circuit boards can be ordered from any one of a multitude of fabricators.  Compare between fabricators by visiting one or more of the fabricator comparison sites like https://www.pcbdirectory.com/get-quotations or https://pcbshopper.com or read the fabricator site collection list at https://www.eevblog.com/wiki/index.php?title=PCB_Manufacturers or search "online pcb quote".

The PCB project is also published by OSH Park PCB fabrication here: https://oshpark.com/projects/UHm82RXw.  
They would appreciate your business so long as you're buying only gold plated.  
 
 I would encourage you to order RoHS (environmental friendly) wherever you're given that option, paying a very slight extra to do so.  Especially if you appreciate me making these plans freely available and so plan to send me your excess.

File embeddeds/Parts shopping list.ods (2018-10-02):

Part # | Qty | Arrow Price | Arrow URL | AlliExpress Price | AlliExpress URL | Mouser Price | Mouser URL | DigiKey Price | DigiKey URL
AD8244 | 1 | 4.88 | https://www.arrow.com/en/products/ad8244brmz/analog-devices | -
MSOP-10 PCB ADAPTER BOARDS | 1 | - | - | 1.89/50 | https://www.aliexpress.com/item/50PCS-SOT23-MSOP10-UMAX-to-DIP10-Transfer-Board-DIP-Pin-Board-Pitch-Adapter-NEW/32902829277.html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
LM334 | 2 | 1.75 | https://www.arrow.com/en/products/lm334znopb/texas-instruments | 1.88/5 | https://www.aliexpress.com/item/5PCS-LM334Z-TO-92-LM334-3-Terminal-Adjustable-Current-Source-new-and-original-IC/32856893079.html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
MCP4162-502 | 2 | 0.9 | https://www.arrow.com/en/products/mcp4162-502ep/microchip-technology | - |  | shipping alone $5 | https://www.mouser.com/ProductDetail/Microchip-Technology/MCP4262-502E-UN | shipping alone $8
alt MCP4262-502 soon | 1 | maybe by request? | - | - | - | shipping alone $5 | https://www.mouser.com/ProductDetail/Microchip-Technology/MCP4262-502E-UN | shipping alone $8
MCP4162-104 | 2 | 0.9 | https://www.arrow.com/en/products/mcp4162-104ep/microchip-technology | - |  | shipping alone $5 | https://www.mouser.com/ProductDetail/Microchip-Technology/MCP4262-502E-UN | shipping alone $8
alt MCP4262-104 soon | 1 | 1.07 | https://www.arrow.com/en/products/mcp4262-104eun/microchip-technology | - |  | shipping alone $5 | https://www.mouser.com/ProductDetail/Microchip-Technology/MCP4262-502E-UN | shipping alone $8
HX711 | 1 | - | - | 0.74 | https://www.aliexpress.com/item/Dual-Channel-HX711-Weighing-Pressure-Sensor-24-bit-Precision-A-D-Module-for-arduino-DIY-Electronic/32878181081.html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
alt HX711 NewerVersion | 1 | - | - | 0.7 | https://www.aliexpress.com/item/Free-shipping-Goose-electronic-HX711-module-weighing-sensor-24-AD-module-pressure-sensor-AD-module-SCM/32441222056.html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
alt ADS1X151 | 1 | - | -
1MOhm resistor | 1

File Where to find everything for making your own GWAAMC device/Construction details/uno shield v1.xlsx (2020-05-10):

Prj: | uno shield v1.xml |  |  |  | Board Qty: | 100
Co.: |  |  |  |  | Unit Cost: | $0.00
Prj date: | Sun 10 May 2020 01:07:30 AM CDT |  |  |  | Total Cost: | $0.00 |  |  |  | $0.00 | 0 |  |  |  | $0.00 | 0 |  |  |  | $0.00 | 0 |  |  |  | $0.00 | 0 |  |  |  | $0.00 | 0 |  |  |  | $0.00 | 0 |  |  |  | $0.00 | 0 |  |  |  | $0.00 | 0
$ date: | 2020-05-10 01:07:52
Global Part Info |  |  |  |  |  |  | Arrow |  |  |  |  | Digi-Key |  |  |  |  | Farnell |  |  |  |  | LCSC |  |  |  |  | Mouser |  |  |  |  | Newark |  |  |  |  | RS Components |  |  |  |  | TME
Refs | Value | Footprint | Manf# | Qty | Unit$ | Ext$ | Avail | Purch | Unit$ | Ext$ | Cat# | Avail | Purch | Unit$ | Ext$ | Cat# | Avail | Purch | Unit$ | Ext$ | Cat# | Avail | Purch | Unit$ | Ext$ | Cat# | Avail | Purch | Unit$ | Ext$ | Cat# | Avail | Purch | Unit$ | Ext$ | Cat# | Avail | Purch | Unit$ | Ext$ | Cat# | Avail | Purch | Unit$ | Ext$ | Cat#
C1 | 390 pF | C_0603_1608Metric_Pad1.05x0.95mm_HandSolder | https://static6.arrow.com/aropdfconversion/49ec807b959b60718e041765739a26df3c5be107/cl10c391jb8nnnd-19.pdf | 0 | $0.00 | $0.00
C2 | .22 µF | C_0603_1608Metric_Pad1.05x0.95mm_HandSolder | https://static6.arrow.com/aropdfconversion/e8d848dc912b3e5d98046e6e34ee002631d712c/y5v.pdf | 0 | $0.00 | $0.00
C3,C5 | 10 µF | C_0603_1608Metric_Pad1.05x0.95mm_HandSolder |  | 0 | $0.00 | $0.00
C4,C11 | 0.1 µF | C_0603_1608Metric_Pad1.05x0.95mm_HandSolder |  | 0 | $0.00 | $0.00
C7 | 1uF | C_0603_1608Metric_Pad1.05x0.95mm_HandSolder | https://static6.arrow.com/aropdfconversion/1f443eab4acf01f089a96c9291c2d9208a40ac8/nmchc.pdf | 0 | $0.00 | $0.00
C8 | 10-51 pF | C_0603_1608Metric_Pad1.05x0.95mm_HandSolder |  | 0 | $0.00 | $0.00
C9,C10 | .022 µF | C_0603_1608Metric_Pad1.05x0.95mm_HandSolder |  | 0 | $0.00 | $0.00
D1 | Red: Electrodes shorted | LED_Rectangular_W5.0mm_H2.0mm |  | 0 | $0.00 | $0.00
D2 | Yellow: Inadequate electrode conductance | LED_Rectangular_W5.0mm_H2.0mm_yellow |  | 0 | $0.00 | $0.00
D3 | Green: Proper electrode conductance | LED_Rectangular_W5.0mm_H2.0mm_green |  | 0 | $0.00 | $0.00
ICSP1 | ICSP Socket | PinSocket_2x03_P2.54mm_Vertical |  | 0 | $0.00 | $0.00
J19,J32 | Conn_01x01_Male |  |  | 0 | $0.00 | $0.00
J5 | Conn_3.5mm | Jack_3.5mm_CUI_SJ1-3534NS_Horizontal_CircularHoles |  | 0 | $0.00 | $0.00
J6 | Conn_01x09_Female | PinSocket_1x09_P2.54mm_Vertical |  | 0 | $0.00 | $0.00
J1-J4 | CONN_01X01 | TestPoint_Keystone_5010-5014_Multipurpose |  | 0 | $0.00 | $0.00
J6_A7 | Conn_01x02_Male | PinSocket_1x02_P2.54mm_Vertical |  | 0 | $0.00 | $0.00
J7-J18,J20-J25 | Conn_01x01_Male | Hole_0.9mm |  | 0 | $0.00 | $0.00
J7_A7 | Conn_01x02_Female | PinSocket_1x02_P2.54mm_Vertical |  | 0 | $0.00 | $0.00
JP1 | C1_leak_mitigator | SolderJumper-3_P1.3mm_Bridged12_RoundedPad1.0x1.5mm_NumberLabels |  | 0 | $0.00 | $0.00
JP12 | SolderJumper_2_Open | SolderJumper-2_P1.3mm_Open_RoundedPad1.0x1.5mm |  | 0 | $0.00 | $0.00
JP2 | C2_bias_reducer | SolderJumper-3_P1.3mm_Bridged12_RoundedPad1.0x1.5mm_NumberLabels |  | 0 | $0.00 | $0.00
JP3 | Cut_JP3_if_installing_HX711_option | SolderJumper-2_P1.3mm_Bridged2Bar_Pad1.0x1.5mm |  | 0 | $0.00 | $0.00
JP4 | HC-05_EN/KEY | PinHeader_1x02_P2.54mm_Vertical |  | 0 | $0.00 | $0.00
JP5 | HC-05_KEY/STATE_LED | PinHeader_1x02_P2.54mm_Vertical |  | 0 | $0.00 | $0.00
JP6 | Bridge in 3Vdc | SolderJumper-2_P1.3mm_Open_Pad1.0x1.5mm |  | 0 | $0.00 | $0.00
JP7 | SolderJumper_3_Bridged12 | SolderJumper-3_P1.3mm_Bridged12_Pad1.0x1.5mm |  | 0 | $0.00 | $0.00
JP8-JP11 | SolderJumper_3_Bridged12 | SolderJumper-3_P1.3mm_Bridged12_Pad1.0x1.5mm_NumberLabels |  | 0 | $0.00 | $0.00
P2 | Power | PinHeader_1x09_P2.54mm_Vertical |  | 0 | $0.00 | $0.00
P3 | Analog | PinHeader_1x06_P2.54mm_Vertical |  | 0 | $0.00 | $0.00
P4 | Digital | PinHeader_1x10_P2.54mm_Vertical |  | 0 | $0.00 | $0.00
P5 | Digital | PinHeader_1x08_P2.54mm_Vertical |  | 0 | $0.00 | $0.00
Q1,Q2 | MMBF5460 (2N5460) | SOT-23_Handsoldering | https://www.onsemi.com/pub/Collateral/MMBF5462-D.pdf | 0 | $0.00 | $0.00
Q3-Q7 | DMN601K-7 | SOT-23_Handsoldering |  | 0 | $0.00 | $0.00
R1,R2 | 100 Ω | R_0603_1608Metric | https://static6.arrow.com/aropdfconversion/92767ba402f81f7b2b89a2bb7df37eaf75b9d9b4/sei-rmcf_rmcp.pdf | 0 | $0.00 | $0.00
R10,R12,R13 | 1 MΩ | R_0603_1608Metric |  | 0 | $0.00 | $0.00
R11,R14 | 470 Ω | R_0603_1608Metric |  | 0 | $0.00 | $0.00
R15,R17 | 14.7 KΩ 0.1% 0.063W ±25ppm/°C (NTR06B1472CTRF) | R_0603_1608Metric | https://static6.arrow.com/aropdfconversion/669b41e07e7b791c3fd809a54c1187fadb989b67/697940354256393ntr.pdf | 0 | $0.00 | $0.00
R16,R18 | 390 KΩ 0.1% 0.063W ±25ppm/°C (CPF0603B390KE1) | R_0603_1608Metric | https://static6.arrow.com/aropdfconversion/a97c085df217e1ed86a021becbd4caec4d5559d7/817849869510639817842178598239eng_ds_1773200_g.pdf | 0 | $0.00 | $0.00
R19 | Optional_Rf | R_0805_2012Metric_Pad1.15x1.40mm_HandSolder |  | 0 | $0.00 | $0.00
R3 | 3.9 KΩ | R_0603_1608Metric |  | 0 | $0.00 | $0.00
R4 | 21 KΩ | R_0603_1608Metric | https://static6.arrow.com/aropdfconversion/3cece72dd289ffbadc164fbcd05f638dd7240f7b/rc_datasheet_150330.pdf.pdf | 0 | $0.00 | $0.00
R5,R9 | 10 KΩ | R_0603_1608Metric |  | 0 | $0.00 | $0.00
R6 | 44.2 KΩ 0.1% 0.1W(1/10W) ±10ppm/°C (1676343-2) | R_0805_2012Metric_Pad1.15x1.40mm_HandSolder |  | 0 | $0.00 | $0.00
R7 | 22.6 KΩ 0.1% 0.125W(1/8W) ±10ppm/°C (ERA6ARB2262V) | R_0805_2012Metric_Pad1.15x1.40mm_HandSolder |  | 0 | $0.00 | $0.00
R8 | 15 KΩ | R_0603_1608Metric |  | 0 | $0.00 | $0.00
SHLD1,SHLD2 | MS263-20C (cover only of MS263-20) | Masach_Tech_MS26320_26x19.50mm | https://www.masach.com/rf-shield-ms263-20-emi-shielded-can.html | 0 | $0.00 | $0.00
SHLD3 | MS544-10C (cover only of MS544-10) | Masach_Tech_MS54410_54x23.90mm | https://www.masach.com/rf-shield-ms263-20-emi-shielded-can.html | 0 | $0.00 | $0.00
U1 | 3V LDO | SOT-23 | http://ww1.microchip.com/downloads/en/DeviceDoc/20001826D.pdf | 0 | $0.00 | $0.00
U2,U35 | OPA2388IDGKR | VSSOP-8_3.0x3.0mm_P0.65mm | http://www.ti.com/document-viewer/OPA2388/datasheet | 0 | $0.00 | $0.00
U3 | ADL5315ACPZ-R7 | ADL5315ACPZ-R7 | https://www.analog.com/media/en/technical-documentation/data-sheets/ADL5315.pdf | 0 | $0.00 | $0.00
U4 | REF200AU | SOIC-8_3.9x4.9mm_P1.27mm | www.ti.com/lit/ds/symlink/ref200.pdf | 0 | $0.00 | $0.00
U40,U41 | LM334Z-LFT1 | TO-92_Spread_for_LM334Z | http://www.ti.com/lit/ds/symlink/lm134.pdf | 0 | $0.00 | $0.00
U5,U6 | LM334M | SOIC-8_3.9x4.9mm_P1.27mm | http://www.ti.com/lit/ds/symlink/lm134.pdf | 0 | $0.00 | $0.00
U7 | MCP4262-503E/UN | MSOP-10_3x3mm_P0.5mm | http://ww1.microchip.com/downloads/en/DeviceDoc/22059b.pdf | 0 | $0.00 | $0.00
U8-U34 | MCP4262-502E/UN | MSOP-10_3x3mm_P0.5mm | Microchip | 0 | $0.00 | $0.00
VR1,VR2 | 50 KΩ | Potentiometer_Bourns_PTV09A-2_Single_Horizontal | https://www.bourns.com/docs/Product-Datasheets/PTV09.pdf | 0 | $0.00 | $0.00
VR3,VR4 | 20 KΩ | Potentiometer_Bourns_PTV09A-1_Single_Vertical | https://www.bourns.com/docs/Product-Datasheets/PTV09.pdf | 0 | $0.00 | $0.00
 |  |  |  |  | Total Purchase: | $0.00 |  | 0 |  | $0.00 |  |  | 0 |  | $0.00 |  |  | 0 |  | $0.00 |  |  | 0 |  | $0.00 |  |  | 0 |  | $0.00 |  |  | 0 |  | $0.00 |  |  | 0 |  | $0.00 |  |  | 0 |  | $0.00
KiCost\N{REGISTERED SIGN} v.1.1.4 |  |  |  |  | Purchase description: |  |  | 0 |  |  |  |  | 0 |  |  |  |  | 0 |  |  |  |  | 0 |  |  |  |  | 0 |  |  |  |  | 0 |  |  |  |  | 0 |  |  |  |  | 0
 |  |  |  |  |  |  |  | 0 |  |  |  |  | 0 |  |  |  |  | 0 |  |  |  |  | 0 |  |  |  |  | 0 |  |  |  |  | 0 |  |  |  |  | 0 |  |  |  |  | 0
 |  |  |  |  |  |  |  | 0 |  |  |  |  | 0 |  |  |  |  | 0 |  |  |  |  | 0 |  |  |  |  | 0 |  |  |  |  | 0 |  |  |  |  | 0 |  |  |  |  | 0
 |  |  |  |  |  |  |  | 0 |  |  |  |  | 0 |  |  |  |  | 0 |  |  |  |  | 0 |  |  |  |  | 0 |  |  |  |  | 0 |  |  |  |  | 0 |  |  |  |  | 0
 |  |  |  |  |  |  |  | 0 |  |  |  |  | 0 |  |  |  |  | 0 |  |  |  |  | 0 |  |  |  |  | 0 |  |  |  |  | 0 |  |  |  |  | 0 |  |  |  |  | 0
 |  |  |  |  |  |  |  | 0 |  |  |  |  | 0 |  |  |  |  | 0 |  |  |  |  | 0 |  |  |  |  | 0 |  |  |  |  | 0 |  |  |  |  | 0 |  |  |  |  | 0
 |  |  |  |  |  |  |  | 0 |  |  |  |  | 0 |  |  |  |  | 0 |  |  |  |  | 0 |  |  |  |  | 0 |  |  |  |  | 0 |  |  |  |  | 0 |  |  |  |  | 0
 |  |  |  |  |  |  |  | 0 |  |  |  |  | 0 |  |  |  |  | 0 |  |  |  |  | 0 |  |  |  |  | 0 |  |  |  |  | 0 |  |  |  |  | 0 |  |  |  |  | 0
 |  |  |  |  |  |  |  | 0 |  |  |  |  | 0 |  |  |  |  | 0 |  |  |  |  | 0 |  |  |  |  | 0 |  |  |  |  | 0 |  |  |  |  | 0 |  |  |  |  | 0
 |  |  |  |  |  |  |  | 0 |  |  |  |  | 0 |  |  |  |  | 0 |  |  |  |  | 0 |  |  |  |  | 0 |  |  |  |  | 0 |  |  |  |  | 0 |  |  |  |  | 0
 |  |  |  |  |  |  |  | 0 |  |  |  |  | 0 |  |  |  |  | 0 |  |  |  |  | 0 |  |  |  |  | 0 |  |  |  |  | 0 |  |  |  |  | 0 |  |  |  |  | 0
 |  |  |  |  |  |  |  | 0 |  |  |  |  | 0 |  |  |  |  | 0 |  |  |  |  | 0 |  |  |  |  | 0 |  |  |  |  | 0 |  |  |  |  | 0 |  |  |  |  | 0
 |  |  |  |  |  |  |  | 0 |  |  |  |  | 0 |  |  |  |  | 0 |  |  |  |  | 0 |  |  |  |  | 0 |  |  |  |  | 0 |  |  |  |  | 0 |  |  |  |  | 0
 |  |  |  |  |  |  |  | 0 |  |  |  |  | 0 |  |  |  |  | 0 |  |  |  |  | 0 |  |  |  |  | 0 |  |  |  |  | 0 |  |  |  |  | 0 |  |  |  |  | 0
 |  |  |  |  |  |  |  | 0 |  |  |  |  | 0 |  |  |  |  | 0 |  |  |  |  | 0 |  |  |  |  | 0 |  |  |  |  | 0 |  |  |  |  | 0 |  |  |  |  | 0
 |  |  |  |  |  |  |  | 0 |  |  |  |  | 0 |  |  |  |  | 0 |  |  |  |  | 0 |  |  |  |  | 0 |  |  |  |  | 0 |  |  |  |  | 0 |  |  |  |  | 0
 |  |  |  |  |  |  |  | 0 |  |  |  |  | 0 |  |  |  |  | 0 |  |  |  |  | 0 |  |  |  |  | 0 |  |  |  |  | 0 |  |  |  |  | 0 |  |  |  |  | 0
 |  |  |  |  |  |  |  | 0 |  |  |  |  | 0 |  |  |  |  | 0 |  |  |  |  | 0 |  |  |  |  | 0 |  |  |  |  | 0 |  |  |  |  | 0 |  |  |  |  | 0
 |  |  |  |  |  |  |  | 0 |  |  |  |  | 0 |  |  |  |  | 0 |  |  |  |  | 0 |  |  |  |  | 0 |  |  |  |  | 0 |  |  |  |  | 0 |  |  |  |  | 0
 |  |  |  |  |  |  |  | 0 |  |  |  |  | 0 |  |  |  |  | 0 |  |  |  |  | 0 |  |  |  |  | 0 |  |  |  |  | 0 |  |  |  |  | 0 |  |  |  |  | 0
 |  |  |  |  |  |  |  | 0 |  |  |  |  | 0 |  |  |  |  | 0 |  |  |  |  | 0 |  |  |  |  | 0 |  |  |  |  | 0 |  |  |  |  | 0 |  |  |  |  | 0
 |  |  |  |  |  |  |  | 0 |  |  |  |  | 0 |  |  |  |  | 0 |  |  |  |  | 0 |  |  |  |  | 0 |  |  |  |  | 0 |  |  |  |  | 0 |  |  |  |  | 0
 |  |  |  |  |  |  |  | 0 |  |  |  |  | 0 |  |  |  |  | 0 |  |  |  |  | 0 |  |  |  |  | 0 |  |  |  |  | 0 |  |  |  |  | 0 |  |  |  |  | 0
 |  |  |  |  |  |  |  | 0 |  |  |  |  | 0 |  |  |  |  | 0 |  |  |  |  | 0 |  |  |  |  | 0 |  |  |  |  | 0 |  |  |  |  | 0 |  |  |  |  | 0
 |  |  |  |  |  |  |  | 0 |  |  |  |  | 0 |  |  |  |  | 0 |  |  |  |  | 0 |  |  |  |  | 0 |  |  |  |  | 0 |  |  |  |  | 0 |  |  |  |  | 0
 |  |  |  |  |  |  |  | 0 |  |  |  |  | 0 |  |  |  |  | 0 |  |  |  |  | 0 |  |  |  |  | 0 |  |  |  |  | 0 |  |  |  |  | 0 |  |  |  |  | 0
 |  |  |  |  |  |  |  | 0 |  |  |  |  | 0 |  |  |  |  | 0 |  |  |  |  | 0 |  |  |  |  | 0 |  |  |  |  | 0 |  |  |  |  | 0 |  |  |  |  | 0
 |  |  |  |  |  |  |  | 0 |  |  |  |  | 0 |  |  |  |  | 0 |  |  |  |  | 0 |  |  |  |  | 0 |  |  |  |  | 0 |  |  |  |  | 0 |  |  |  |  | 0
 |  |  |  |  |  |  |  | 0 |  |  |  |  | 0 |  |  |  |  | 0 |  |  |  |  | 0 |  |  |  |  | 0 |  |  |  |  | 0 |  |  |  |  | 0 |  |  |  |  | 0
 |  |  |  |  |  |  |  | 0 |  |  |  |  | 0 |  |  |  |  | 0 |  |  |  |  | 0 |  |  |  |  | 0 |  |  |  |  | 0 |  |  |  |  | 0 |  |  |  |  | 0
 |  |  |  |  |  |  |  | 0 |  |  |  |  | 0 |  |  |  |  | 0 |  |  |  |  | 0 |  |  |  |  | 0 |  |  |  |  | 0 |  |  |  |  | 0 |  |  |  |  | 0
 |  |  |  |  |  |  |  | 0 |  |  |  |  | 0 |  |  |  |  | 0 |  |  |  |  | 0 |  |  |  |  | 0 |  |  |  |  | 0 |  |  |  |  | 0 |  |  |  |  | 0
 |  |  |  |  |  |  |  | 0 |  |  |  |  | 0 |  |  |  |  | 0 |  |  |  |  | 0 |  |  |  |  | 0 |  |  |  |  | 0 |  |  |  |  | 0 |  |  |  |  | 0
 |  |  |  |  |  |  |  | 0 |  |  |  |  | 0 |  |  |  |  | 0 |  |  |  |  | 0 |  |  |  |  | 0 |  |  |  |  | 0 |  |  |  |  | 0 |  |  |  |  | 0
 |  |  |  |  |  |  |  | 0 |  |  |  |  | 0 |  |  |  |  | 0 |  |  |  |  | 0 |  |  |  |  | 0 |  |  |  |  | 0 |  |  |  |  | 0 |  |  |  |  | 0
 |  |  |  |  |  |  |  | 0 |  |  |  |  | 0 |  |  |  |  | 0 |  |  |  |  | 0 |  |  |  |  | 0 |  |  |  |  | 0 |  |  |  |  | 0 |  |  |  |  | 0
 |  |  |  |  |  |  |  | 0 |  |  |  |  | 0 |  |  |  |  | 0 |  |  |  |  | 0 |  |  |  |  | 0 |  |  |  |  | 0 |  |  |  |  | 0 |  |  |  |  | 0
 |  |  |  |  |  |  |  | 0 |  |  |  |  | 0 |  |  |  |  | 0 |  |  |  |  | 0 |  |  |  |  | 0 |  |  |  |  | 0 |  |  |  |  | 0 |  |  |  |  | 0
 |  |  |  |  |  |  |  | 0 |  |  |  |  | 0 |  |  |  |  | 0 |  |  |  |  | 0 |  |  |  |  | 0 |  |  |  |  | 0 |  |  |  |  | 0 |  |  |  |  | 0
 |  |  |  |  |  |  |  | 0 |  |  |  |  | 0 |  |  |  |  | 0 |  |  |  |  | 0 |  |  |  |  | 0 |  |  |  |  | 0 |  |  |  |  | 0 |  |  |  |  | 0
 |  |  |  |  |  |  |  | 0 |  |  |  |  | 0 |  |  |  |  | 0 |  |  |  |  | 0 |  |  |  |  | 0 |  |  |  |  | 0 |  |  |  |  | 0 |  |  |  |  | 0
 |  |  |  |  |  |  |  | 0 |  |  |  |  | 0 |  |  |  |  | 0 |  |  |  |  | 0 |  |  |  |  | 0 |  |  |  |  | 0 |  |  |  |  | 0 |  |  |  |  | 0
 |  |  |  |  |  |  |  | 0 |  |  |  |  | 0 |  |  |  |  | 0 |  |  |  |  | 0 |  |  |  |  | 0 |  |  |  |  | 0 |  |  |  |  | 0 |  |  |  |  | 0
 |  |  |  |  |  |  |  | 0 |  |  |  |  | 0 |  |  |  |  | 0 |  |  |  |  | 0 |  |  |  |  | 0 |  |  |  |  | 0 |  |  |  |  | 0 |  |  |  |  | 0
 |  |  |  |  |  |  |  | 0 |  |  |  |  | 0 |  |  |  |  | 0 |  |  |  |  | 0 |  |  |  |  | 0 |  |  |  |  | 0 |  |  |  |  | 0 |  |  |  |  | 0
 |  |  |  |  |  |  |  | 0 |  |  |  |  | 0 |  |  |  |  | 0 |  |  |  |  | 0 |  |  |  |  | 0 |  |  |  |  | 0 |  |  |  |  | 0 |  |  |  |  | 0
 |  |  |  |  |  |  |  | 0 |  |  |  |  | 0 |  |  |  |  | 0 |  |  |  |  | 0 |  |  |  |  | 0 |  |  |  |  | 0 |  |  |  |  | 0 |  |  |  |  | 0
 |  |  |  |  |  |  |  | 0 |  |  |  |  | 0 |  |  |  |  | 0 |  |  |  |  | 0 |  |  |  |  | 0 |  |  |  |  | 0 |  |  |  |  | 0 |  |  |  |  | 0
 |  |  |  |  |  |  |  | 0 |  |  |  |  | 0 |  |  |  |  | 0 |  |  |  |  | 0 |  |  |  |  | 0 |  |  |  |  | 0 |  |  |  |  | 0 |  |  |  |  | 0
 |  |  |  |  |  |  |  | 0 |  |  |  |  | 0 |  |  |  |  | 0 |  |  |  |  | 0 |  |  |  |  | 0 |  |  |  |  | 0 |  |  |  |  | 0 |  |  |  |  | 0
 |  |  |  |  |  |  |  | 0 |  |  |  |  | 0 |  |  |  |  | 0 |  |  |  |  | 0 |  |  |  |  | 0 |  |  |  |  | 0 |  |  |  |  | 0 |  |  |  |  | 0
 |  |  |  |  |  |  |  | 0 |  |  |  |  | 0 |  |  |  |  | 0 |  |  |  |  | 0 |  |  |  |  | 0 |  |  |  |  | 0 |  |  |  |  | 0 |  |  |  |  | 0
 |  |  |  |  |  |  |  | 0 |  |  |  |  | 0 |  |  |  |  | 0 |  |  |  |  | 0 |  |  |  |  | 0 |  |  |  |  | 0 |  |  |  |  | 0 |  |  |  |  | 0
 |  |  |  |  |  |  |  | 0 |  |  |  |  | 0 |  |  |  |  | 0 |  |  |  |  | 0 |  |  |  |  | 0 |  |  |  |  | 0 |  |  |  |  | 0 |  |  |  |  | 0
 |  |  |  |  |  |  |  | 0 |  |  |  |  | 0 |  |  |  |  | 0 |  |  |  |  | 0 |  |  |  |  | 0 |  |  |  |  | 0 |  |  |  |  | 0 |  |  |  |  | 0
 |  |  |  |  |  |  |  | 0 |  |  |  |  | 0 |  |  |  |  | 0 |  |  |  |  | 0 |  |  |  |  | 0 |  |  |  |  | 0 |  |  |  |  | 0 |  |  |  |  | 0
 |  |  |  |  |  |  |  | 0 |  |  |  |  | 0 |  |  |  |  | 0 |  |  |  |  | 0 |  |  |  |  | 0 |  |  |  |  | 0 |  |  |  |  | 0 |  |  |  |  | 0
 |  |  |  |  |  |  |  |  |  |  |  |  |  |  |  |  |  |  |  |  |  |  | 0

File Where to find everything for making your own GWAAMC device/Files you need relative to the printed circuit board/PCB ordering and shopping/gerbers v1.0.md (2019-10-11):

https://github.com/kenneth558/plant_resistance_primary_perception/blob/Free/Where%20to%20find%20everything%20for%20making%20your%20own%20GWAAMC%20device/Files%20you%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

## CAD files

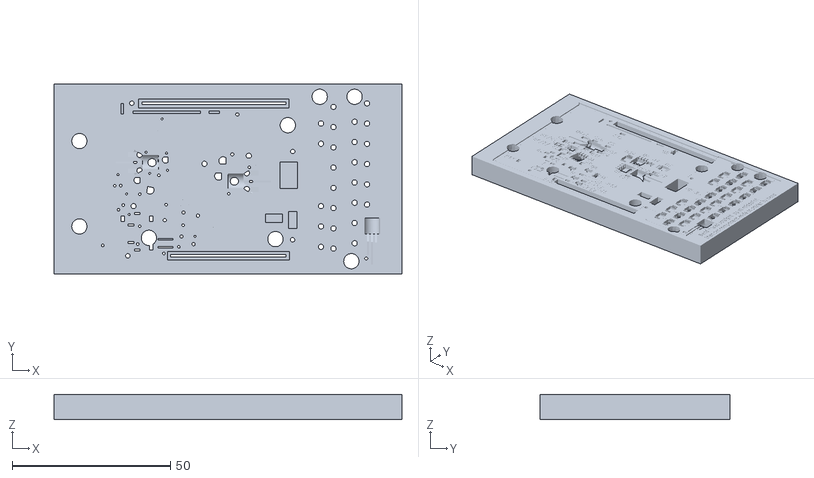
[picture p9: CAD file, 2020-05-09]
Where to find everything for making your own GWAAMC device/Construction details/Bottom PnP Component Stencil.stl
110.0 x 60.0 x 8.00

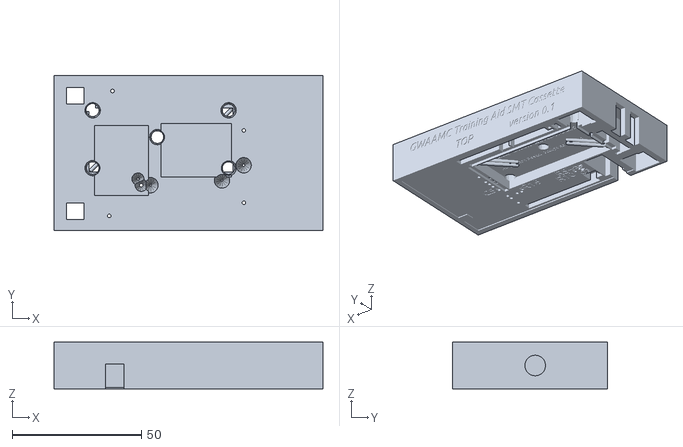
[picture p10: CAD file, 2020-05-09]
Where to find everything for making your own GWAAMC device/Construction details/Top PnP Component Stencil.stl
104.0 x 60.0 x 18.0

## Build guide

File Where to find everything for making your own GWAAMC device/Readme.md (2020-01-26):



[Schematic in PDF](https://github.com/kenneth558/plant_resistance_primary_perception/blob/Free/Where%20to%20find%20everything%20for%20making%20your%20own%20GWAAMC%20device/schematic.pd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)

[More CAD renderings showing components already placed](https://github.com/kenneth558/plant_resistance_primary_perception/tree/Free/Where%20to%20find%20everything%20for%20making%20your%20own%20GWAAMC%20device/Construction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)

[See the bare boards](https://github.com/kenneth558/plant_resistance_primary_perception/blob/Free/Where%20to%20find%20everything%20for%20making%20your%20own%20GWAAMC%20device/Files%20you%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)

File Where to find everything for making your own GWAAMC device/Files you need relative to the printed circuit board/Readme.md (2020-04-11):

To buy your own PCB you'll send [this file](https://github.com/kenneth558/plant_resistance_primary_perception/blob/Free/Where%20to%20find%20everything%20for%20making%20your%20own%20GWAAMC%20device/Files%20you%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) and [this file](https://github.com/kenneth558/plant_resistance_primary_perception/blob/Free/Where%20to%20find%20everything%20for%20making%20your%20own%20GWAAMC%20device/Files%20you%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) to OSH Park, BasicPCB, PCBWay, or to wherever you choose, then pay and wait.  [This](https://oshpark.com/shared_projects/fb4IIqwY) is the OSH Park project link for even easier ordering of the main board...and [aux board](https://oshpark.com/shared_projects/tLj5WHoL) at OSH Park. A minimum quantity purchase of 3-5 boards is normal.  

*NEW!* [Boards combined](https://github.com/kenneth558/plant_resistance_primary_perception/blob/Free/Where%20to%20find%20everything%20for%20making%20your%20own%20GWAAMC%20device/Files%20you%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) but able to be carefully separated before or after after components get soldered down.  May be temporarily air-wired into operation while still in one piece.  This style may help you in PCB soliciting quotes and ordering, but it will be risky separating them due to proximity to board edges of conducting traces.  [Boards combined OSH Park project](https://oshpark.com/shared_projects/ZdywHSTk).

I actually can't recommend the ENIG boards because industry wisdom is now that the gold on ENIG boards is better washed off ("cleansed") by double tinning - I've found that I have to wash it off, anyway, to get acceptable results.  That negates the entire advantage of ENIG's flat pads for fine pitch components because it takes several hours to double tin and flatten out the pads.  Then on top of that, the last HASL boards I ordered had taken sufficient precautions to give me flat pads on the side of the board it mattered most for me...without me even suggesting it!  That left only one single fine-pich component for me to worry about, and I took care of that easily with Kapton tape/hot air/hot iron pad flattening.  Besides, ENIG boards are limited to a six month shelf life.  So I'm going to recommend just getting 2oz,TG170+, lead-free HASL boards, requesting the fab house try to put flattest pads on the surface with the most fine-pitch packages, and flatten any other fine pitch pads yourself.  On the ENIG boards, a little solder flux helps conduct the heat and makes things less frustrating.  If there is any chance you'll use bismuth solder and you're going the HASL route, specify "lead-free" HASL or the solder won't stick to the pads.

If you are determined to purchase ENIG boards, you can't go wrong with OSH Park because their [rigid] boards handle the heat so well without the copper delaminating nor heat damage occuring otherwise.  I've read they use TG170.  Chinese boards default to TG140 and will darken and char at much lower heat levels than OSH Park boards, and their copper delaminates from the board at lower heat levels than OSH Park's 2 oz. boards.  OSH Park's flex boards, however, won't handle full-scale air heating without risking bubbles, but if you're careful to pop those bubbles while they're small, you should be fine.

When I got sloppy with the ENIG boards by putting on way more solder than I needed to, I did pull pads up, so you might as well be neat and frugal while tinning, including only tinning one side - the side you need to tin - on the plated through holes.  Here's how I convert ENIG to lead-free HASL:  
- I use hot air, 
- press lead-free solid wire solder against all gold that needs to be soldered to until the gold is absorbed into molten solder
- I do this twice
- I scoop the surface flat with hot air, then convert to bismuth (low temperature) solder with one more pass and scoop flat again.  If you've been thorough on every step, your board is ready to accept bismuth cream and placed components and heat to melt the low-temperature solder.

Stencil stock thickness should be no more than 4 mil (0.1mm).  Don't trust stacking stencils to obtain that thickness because the stencil apertures must have smooth enough walls not to pull the paste solder off the board when removed.  Remove the stencil quick enough after applying the paste that the paste doesn't dry enough to adhere to the stencil apertures walls.

Stencils are [here](https://github.com/kenneth558/plant_resistance_primary_perception/blob/Free/Where%20to%20find%20everything%20for%20making%20your%20own%20GWAAMC%20device/Files%20you%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).

*NEW!* Combined board stencils [here](https://github.com/kenneth558/plant_resistance_primary_perception/blob/Free/Where%20to%20find%20everything%20for%20making%20your%20own%20GWAAMC%20device/Files%20you%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).

Bare board renderings courtesy of OSH Park

Front/Top view

Back/Bottom view

[Go to populating the board or the populated board instead](https://github.com/kenneth558/plant_resistance_primary_perception/tree/Free/Where%20to%20find%20everything%20for%20making%20your%20own%20GWAAMC%20device)

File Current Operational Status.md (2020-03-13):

As of 13 Mar 2020 due to coronavirus caution, I have stopped traveling to the maker space in Omaha, NE where I have been doing my soldering. My boards remain unfinished. I am temporarily housed in a bedroom unsuitable for soldering fumes so I need someone who believes in this project to please offer some project space to me knowing I have no income and not even enough savings to see this project through to a marketable state short of a miracle. Please use the "Issues" option above, then "New Issue" to contact me.

**Current Operational Status:** Three new circuit boards arrived and are being built up for testing the latest circuit design. The first board lost a couple pads while getting solder tinned, but I always repair these types of failures by adding air-wires.  Expected finish in April, except as noted above.

I'm changing out the Rail-to-Rail Input (RRI) unity gain buffer for a input Zero CrossOver (ZCO) op-amp to alleviate the killer input crossover distortion.  Today (18 Jan 2020) I completed the rough PCB design as far as needed to ensure it will work, and I've begun a second examination for optimizing it.  Give me another 3 months to finish.  Once I get the project working with the new device, I'll focus on sketch upgrading.  I haven't even thought much about a project enclosure for it, either.  I do think it needs an enclosure to slow down the temperature changes when the ambient air moves.  A grounded metal one would also attenuate the effect of moving electrical charges nearby.  Both effects are very, very noticeable.  Until they are dealt with, I withhold judgment as to the functionality with a realistic DUT.  

Version 1.x built units will be labeled "This Version 1.x Training Aid Is Without Temperature Compensation, Useful For Observing Conductance Behavior, But Not For True And Honest Measuring.  Development Level Units Prior To Version 2.0 Are Not Intended For Repeatable Or Reproducible Precision Laboratory-Class Measurements".

Units built and manufactured at this Version 1.x level should meet the expectations of the vast majority of users to *observe* the plant's response, but true *measuring* (as opposed to *observing*) with electrodes is very dependent on electrode contact surface area and other factors that are not easily and conveniently controlled outside a laboratory setting.

I hope to begin development on a temperature-compensated Version 2.0 in the future, but I'll need to catch up financially first by selling kits and fully-built units at the current version level.

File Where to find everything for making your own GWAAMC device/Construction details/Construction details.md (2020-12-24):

THIS PROJECT IS VERY DIFFICULT TO BUILD.  

I can't envision anyone successfully building this circuit board who doesn't know what a short and open is and who doesn't know why and how to both visual and meter for them and to meter for voltage and resistance.  Please don't embark on building this yourself without at least that level of knowledge unless you are the world's most perfect solderer.

The hardest aspect of construction is soldering the SMDs.  You might not expect this, but will be easier if you understand about eutectic composition of alloys if soldering to a plated or tinned board, as well as understand about gold embrittlement of solder.  The plating/tinning supplied by the board manufacturer cross contaminates the solder you are adding, making your solder's melting point higher, which tends to de-wet the pads.  Worse yet, atoms of gold and silver tend to produce molecular bonds instead of metallic bonds.  Atoms actually MOVE from their mechanically stronger bonded alloy states into "intermetallic" and mechanically weak substances over time.  If you have a hard time believing that atoms  within solid metal are actually migratory, read up on "tin whiskers".  

If your board is plated rather than tinned, or tinned with some alloy dissimilar to your solder, you'll have to brute force it by using 30-50°F hotter soldering temperature than your solder liquidus temperature, with 30-50°C (54-90°F) hotter actually being the official industry recommendation.  Yes, this does apply even for precious metal plated.  Removal of gold plating is **mandated** by industry wisdom if using Sn**Pb** solder, **yet no-lead solder is still negatively affected** by gold, albeit with a less abrupt failure curve than SnPb.  (An exception might be for an Indium-containing solder that actually turns the lead beneficial for use with gold if done right.)  "Wash" the ENIG off by double tinning before soldering with any solder with Pb is the necessary practice.  I gently "squeegie" the washing tinning with a hot air nozzle of a sodering station.  

The very best high-temp solder would be SN100C, but only if you order TG170 or higher PCB since the melting point is significantly high at 227°C.  Note importantly that U4 allows absolutely no higher soldering temperature than 260°C, and that happens to be the absolute minimum temperature recommended for SN100C wave soldering.  You MUST use bismuth solder to seal vias into all shields because that is the only solder type that expands instead of contracting when hardening.  I strongly advise bismuth solder (low temp) be used to solder down all shields in case you have to remove any of them later...it just makes removal easier.  Generally, I recommend using not using the same melting temp solders on both sides so the soldering process will only melt one side at a time.  I suggest high temp on the top side and low temp for the top side because the top side most needs to be done in an oven.

Note that **bismuth cross contaminated by lead is to be avoided at all costs** due to any lead whatsoever will always weaken that solder by forming 95°C melting point aspects within the final joint, not to mention the joint will tend to be full of frustrating intermetallics of some unknown nature in the meantime.  Therefore bismuth solder is suitable for use only on boards made to be lead-free.  I haven't noticed bare copper boards to have the problem of cross contamination de-wetting, but you should realize that copper oxidizes so quickly that you will likely need rosin/flux applied along with the solder to de-oxidize pads on a bare copper board.  So if you find yourself being frustrated by components not taking solder, my first guess would be that either you mixed solders or didn't double tin surfaces thoroughly.

In summary, I recommend bismuth paste solder for components with more than two leads and as long as you realize you need to get it hotter while cleansing new plating.   When I build a board _without_ paste or cream solder, I'll expect two solder attempts.  The first is with 97% tin, 3% silver solid solder (especially on two leaded components) and the second pass is spot soldering with bismuth solder of any kind after microscopic inspection of all joints.  I will diligently avoid having Pb solders in the area whenever I have any hopes to use bismuth solders, ever.  I will avoid tinning the through plating of PTH (Plated Through Holes) until final placement of the component, and will tin those annular rings with bismuth solder after wash-tinning them.  When assembling PTH connectors not soldered in finality, firmly and thoroughly press that component against the board as you temp-solder it.  Otherwise the component transmits pushing forces and too easily pushes the far side annular ring, breaking it free from the board.

To keep components pieces from blowing away in hot soldering, I dabbed a tiny bit of rosin on their undersides.  

Loupes will be useful when you need true color and highest resolution to differentiate between metallic and non-metallic specks, when and if you can provide the lighting and short focal distance they need.  The microscope would be useful when you need an adjustable focal range and can tolerate the lack of vendor honesty about the resolution and operating system compatibility from the manufacturer, and inability to adjust color and lighting settings adequately.  If you can find in your heart to get a microscope, you'll be able to put it to good use later to visually magnify growth of the plant at the ends of branches as yet another means of real-time feedback.  If I could have designed the circuit to employ components packaged in more manageable sized packaged, believe me, I would have done so.  Between U3 and one or the other MCP4262, there is no getting around using the microscopic packages that the component manufacturers calously decided upon, so the remainder of the packages might as well follow suit, IMHO.  In retrospect, I don't think I could have fit the circuit into an UNO-sized board if I would have used larger packages anyway.

### DO NOT OPEN U4 (REF200) PACKAGING UNTIL YOU ARE READY TO SOLDER IT IN PLACE AND SOLDER-SEAL SHLD1, SHLD2, and SHLD3 IN PLACE WITH DISSICANT AS A SINGLE STEP!  That IC is a high precision component that is designed to give you highest performance when always kept in a very low humidity environment.  (This is also why the micro-vias under only one shield should be solder-sealed into hermetically sealed containment.)  If you open that package too soon, here are the instructions to remedy: 
 1. Calculated shelf life in sealed bag: 12 months at <40°C and <90% RH from bag seal date.
 2. Peak component body temperature for soldering: 260°C(500°F)
 3. After bag is opened, devices that will be subjected to reflow solder or other high temperature process must be 
   a) Mounted within 168 hrs of factory conditions of <30C/60% RH, or
   b) Stored per J-STD-033
 4. Devices require bake before mounting if:
   a) Humidity indicator card reads >10%
   b) When 3a or 3b are not met
 5. If baking is required, refer to IPC/JEDEC J-STD-033 (Level 3 MSL components, 1.75mm thickness, 260°C peak body temp) for the prescribed bake procedure.

#### The dessicant package you receive with U4 and which you won't be able to see until the moment you need to place it will likely be too large to place inside SHLD1 where it eventually needs be placed.  You will be wise, therefore, to keep your eyes open for a smaller dissicant package that you can repurpose from some other product that will fit inside the SHLD1 lid.  Bake it for most of a day in an electric oven at a temperature near the boiling point of water, then keep it dry (hermetically sealed) until you go to place it.

Electrodes are vaporware as of yet: I'm hoping to use non-impregnated carbon fiber tow, not the prepreg tow.  The carbon fiber must establish its electrical connection to the circuit via gold plated contact or else corrosion will ensue.  Alternatives to gold are fewer and more rare.

Hours of my development time has been wasted because I had no solder wick left.  Do yourself a favor and make sure to have solder wick available.

Link to BOM: https://github.com/kenneth558/plant_resistance_primary_perception/blob/Free/Where%20to%20find%20everything%20for%20making%20your%20own%20GWAAMC%20device/On%20buying%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

NOTE IF 3.3V OPERATION IS DESIRED:  Pin 5 of J2 will have to be omitted and the pad of the adjacent pin 4 J2 will have to be shorted over to the pad of that pin 5.  I neglected to leave room for the jumper to do this.  Sorry!   Only do this when pin 2 of ICSP1 from the MCU is also providing +3.3V!!!!

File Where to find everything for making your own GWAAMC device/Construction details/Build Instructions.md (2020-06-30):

1.  With the jigs, highlight all their debossed references.  One way to do this might be to mark into them with a permanent marker and clean up the overspill.
2.  Soldering to such small pads requires absolute cleanliness to be maintained of all surface mount surfaces to be soldered to.  Let no bodily sweat, oils nor fluids touch the SMD component leads prior to placing nor touch the printed circuit board pads prior to soldering. Wearing surgical gloves might be a good idea.  Cleaing those surfaces with isopropyl alcohol immediately prior to soldering might be a good idea, too.  Unfortunately, adhesive tape of any kind will 
3.  Components must fit into their cavities loosely enough that they would fall right out if gently flipped over, but tightly enough that they are very accurately placed.  Their solder surfaces should be flush with the top surface around their cavities.
4.  SMD capacitors have no markings so cannot be differentiated without testing if intermixed with each other.  Keep track of them carefully.
5.  Whoever makes the jig has an impact on the accuracy of its cavity dimensions, so changing producers should only be done advisedly and conservatively.  Undersized cavities are problematic.  Oversized cavities will require some manual component placement guidance in them.

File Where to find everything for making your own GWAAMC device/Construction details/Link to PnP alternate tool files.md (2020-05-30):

https://drive.google.com/drive/folders/1_j0E5dFC1kLGvFu55QTtv5UvltjqBdjs?usp=sharing

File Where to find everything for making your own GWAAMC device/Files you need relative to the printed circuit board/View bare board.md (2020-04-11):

NOT TO SCALE WITH EACH OTHER.  Bare board renderings courtesy of OSH Park

Front/Top view

Back/Bottom view

Expansion (aux) front/top view

Expansion (aux) back/bottom view

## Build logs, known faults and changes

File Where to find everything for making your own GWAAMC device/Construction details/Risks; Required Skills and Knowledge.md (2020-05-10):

### DISCLAIMER

I am forced by the reality of all the development complexities to strongly suggest that until this sketch has been bug-free at the latest revision level for at least three to four weeks after I claim it to be bug-free, all potential users just hold off unless you are prepared to fix my sketch bugs. Sorry for not being perfect.

In the sketch source code of this project, you'll find some self-explanatory-named constants near the top that you'll need to set for your preferences and configuration.  Find and adjust these:

-  NUM_INPUTS_TO_PLOT_OF_INBOARD_ANALOG
-  NUM_INPUTS_TO_PLOT_OF_ADDON_HIGHEST_SENSI_ADC
-  HIGHEST_SENSI_ADDON_ADC_TYPE (at this time only HX711 is supported)
-  MULTIPLICATION_FACTOR
-  HIGHESTBITRESFROMHIGHESTSENSIADDONADC
-  ANALOGINPUTBITSOFBOARD
-  SAMPLE_TIMES
-  DELAY_TIME_BETWEEN_SAMPLES_MS
-  DELAY_TIME_BETWEEN_SAMPLES_US
-  look for others in the same source code vicinity (i.e., near the very top of the sketch) that get added as I enhance the code over time

The specific purpose of this project is to monitor electrical conductance changes of plant tissue, such as a leaf, in vivo.  Tested with UNO and Leonardo.  Mac and Windows are assumed to work as well as Linux.  Avoiding STM32F103C8T6 due to bootloader issues in Linux with common USB-serial adapters, avoiding ATTINY85 due to no hardware serial.  Other boards having at least one analog input can be used, or add the very inexpensive ADS1115 or HX711 for best resolution.  IMPORTANT: When selecting a board you'll use for this project, make sure it has a USB port or that you are otherwise able to fashion serial communications. The output from the Arduino is formatted for input into the Arduino IDE serial plotter rather than the serial monitor.  

With the rudimentary (periodic improvements are to be expected to this project) sketch I publish here for you, you can observe for yourself that plants actually can know your sentiments as they relate to the plant's well-being.  You'll also need to fashion the electrode system and attach it.  I suggest you not get so wrapped up in being scientifically credible that you miss the point of all this.  The point is that the electrical conductance of a plant does respond to someone's intent to substantively affect its well-being.  The point is NOT that any particular readings can be precisely replicated.  With that caveat and because of it, I suggest a very primitive electrode system that does not involve the salinated agar-on-cotton gauze-on-stainless steel system that Mr. Backster thought he had to use for scientific credibility.  Until I am satisfied with successful proof-of-concept of this project, I am suggesting using the more bio-compatible elements of mud inside a coarse-knit pouch made of non-dyed, non-bleached plant-derived fabric like burlap, linen, cotton, and/or hemp.  I, however, am keen to develop a ciliated electrode made from PDMS (and acetylene black if needed) with carbon fibers from each cilia to the connector.  For you, I suggest for each pouch/electrode used that you fashion a sling to bear the weight of the pouch using a matching strip of fabric.  What bothers me about stainless electrodes is that metals produce galvanic voltage from their very contact with dissimilar materials.  I suspect a galvanic potential could also be generated by contact with some other element of this apparatus also.  The significant chromium content of stainless is another concern I have.

Poke the electrode wires into the pouches (or maybe one into a pouch and one into the soil?), but keep the metal of the wires from direct contact with any plant tissue, since metals are foreign to living organism tissues and so may produce an unaccounted for reaction.  To ensure an acceptable quality contact between the mud and electrode wires, the wire should transition into a minimal resistance contact into the electrolyte.  In the beginning in my haste to want an immediate transition away from metal, I used graphite motor brushes, but I'm suspicious that the priority should be changed to favor a lower resistance contact (such as a metal screen soldered/brazed) on the end of the electrode wires but still not allowed to outright touch any plant tissue.  Note that a piece of screen allows for a lower resistance contact than a similarly shaped and sized solid metal "leaf".

I prefer using mud instead of salt as an electrolyte for my confidence achieving maximum bio-compatibility. Ensure the mud is adequately liquified and the brush is fully inserted into the mud and the muddied pouch is in intimate and stable contact with the leaf or other plant tissue.  You also may want to learn the difference between hypostomatous and hyperstomatous leaves relative to the plant you use if you care to avoid blocking the gas-exchange stomata.  Blocking the stoma with the electrode apparatus may generate yet another source of stress for the plant, thus I recommend stoma-blocking be minimized in terms of time and surface area.  Nearby fluorescent lighting and other high-harmonic and/or heavy electric loads may produce unwanted artifacting, so they are best kept away from.

You'll have to rig some sort of pouch-holding device of your own design.  Maybe a large non-conductive (plastic/wooden) easel could be used to support the fabric sling.  Unless your plant has large leaves, you may find it difficult to place opposite electrodes on a single leaf without one pouch shorting across to the opposing pouch, so I suggest trying to put each electrode-pouch on its own leaf.  The weight of the mud-filled pouch on the top side of the leaf will be enough force to maintain a solid electrical contact.  This configuration is for hypostomatous, the most common type leaves you'll be using.

Note that you'll be best served by understanding the electrical circuit being formed by your electrode placements.  As long as you do so, multiple electrodes of each polarity might be of benefit, but I really think you're better off avoiding any circuit more complex than you understand.

**_Note that the electrode circuit must also consist of a resistive component attached by you between the power supply rail and the analog input pin of the signal electrode._**  That resistor is located locally to the board so does not require a third length of wire. The electrode wire not going to the analog input pin goes to signal ground and will be referred to as the reference electrode.  **_All mention of LM334 in this project refers to replacing that resistor with an LM334 and a few support components._**  Signal ground is determined by you as a ground pin of the active device that contains the ADC, preferably a pin provided for the precise purpose of being  signal ground.  For best practice, avoid attaching the reference electrode to any point on circuit board ground that connects to a component other than the ADC device before connecting to the ADC.  Ideally, the value of resistance of the above mentioned resistive component will be as equal as practical to the resistance of the plant tissue under test.  The resistance of the plant tissue between the electrodes can be decreased or increased by adjustment of the surface area in contact with the electrode pouches - more contact area gives less resistance as well as a better signal-to-noise ratio but also probably produces greater undesirable measurement effect. At this stage, end-users are on their own to learn about how to avoid electrical current leakage paths.  As far as avoiding radiated electrical noise, maintain adequate distance from fluorescent and neon lighting and any other source of noise you discover, understanding that your computer and cell phone are definite noise sources.  Wifi capability is planned .

Note: According to Mr. Backster, the plant under test must have already become "acclimated" to the person performing the primary perception procedures for the phenomenon to be observable.  Take that to mean what you will.  I believe it means you'll need to spend some time initially watering the plant or otherwise caring for it before you can expect significant results from this project.  Until I'm shown wrong, I'm fairly certain that hostile or hurtful sentiments toward the plant are counter-productive to sustained acclimation, Mythbusters!  If you can video record your success with this phenomenon, I will be very interested in including your resultant YouTube video in my playlist here: https://www.youtube.com/playlist?list=PL5o95K6gCP735crox7Aoe7EkTgvywbxmJ.  Note that I am quite UNinterested in videos that express negative sentiments, so I may not link to them.  Instead of exercising your negative power over plants, please try to show us results from POSITIVE sentiments...and thank you for that!  Note to anyone wanting this device for tobacco, marijuana, coca, weaponizing or similar uses: You'll not have ANY support from me for purposes not intended to make the world a better place.  Don't even try to get my support for those type purposes that make the world a worse place rather than better.  Notice the period at the end of that statement.

Purchase the components from the vendors suggested (I’ve done the price shopping for you), and build the board in the suggested component order. SMD soldering ability required with SMD packages including MSOP10 and SOT-0201. Those packages require advanced soldering ability. If you need to acquire that level of soldering skill, you may readily do so using SMD solder practice kits and soldering equipment commonly available. I suggest low-temperature paste solder, PCB oven (makeshift can work), and hot air + tip soldering iron.  

BOM: https://github.com/kenneth558/plant_resistance_primary_perception/blob/Free/ibom.html

For those who won’t be able to build their own, their projected cost for us to build each training aid device, test it, and sell it will be in the range of $2000 USD…far more expensive than you might first think. But to see that the most people possible can get the training this device facilitates, we encourage you who can't afford to support GWAAMC to just build your own. DIY'ers building their own GWAAM-Sea training aid will pay for the components the same price that we would pay and from the same vendors we buy from. In making such an arrangement, we are trying to be as consistent as possible to the hallmark of the Kingdom of God: “the Gospel is preached to the poor. ” (Matt. 11:5)  "...Hath not God chosen the poor of this world rich in faith..." (Jas. 2:5)  We can't say this will be an easy project for you (it's hard), but we've done what we can to give you all the building info a DIY'er needs.

You may be interested to read some of the Biblical justification for this project.  See the document entitled on that subject listed among the documents of this project.

For those who have any regard to NDEs, you would be interested to research Howard Storm's NDE relative to world lifestyle of the future.

Submit an "Issue" or post in the "Wiki" (tabs above) to have me add your YouTube video to the official playlist for this 
project.

------------

As of 30 April 2018, this sketch is functional, only requiring low-noise construction techniques of the connections and circuitry.  However, until further notice, THIS .INO FILE IS UPDATED **_OFTEN_** FOR IMPROVEMENTS AND BUGFIXES.  
        
If you are using the ADS1015 or ADS1115, using a AD8244 is recommended and be sure to install the supporting library Adafruit_ADS1015 since this sketch depends on it.  Thank you, Adafruit!  If you're using the HX711, using a AD8244 is required and install the .cpp and .h files located here: https://github.com/bogde/HX711 (thank you to bogde) Consideration is being given to adapting a fork of this project to the Raspberry Pi-ish ARM single board computers.  This sketch *version* is FREE so that anyone can enjoy it.  For those of you who can afford to support my work on this project, I will offer a "not-free" sketch version when the parts arrive that has the following enhancements:

-  Arrange for adjustments of various kinds during run time based on keyboard inputs.  The current plotter included with 
        the Arduino IDE does not accommodate this, so this feature will have to be coded with a different language and run
        by software other than the IDE.
-  Use an LM334 or two to prevent power supply noise from plotting (i.e., convert from monitoring resistance to monitoring 
        conductance, which means that power supply noise is eliminated!).  A toroid-based noise suppression coil in series 
        with the LM334 might be needed as one of the supporting components.  Since the part includes a temperature coefficient,
        a second one is also needed for offset for stable balance with temperature drift.
-  Use digital potentiometer (MCP41XX2 or MCP42XX2) for more automated balancing of the two serial resistances.

Add-on ADCs, especially the more affordable ones, tend to have inputs that are of such low-impedance that they don't work unbuffered in this project where the plant is high impedance (high resistance).  That problem might be able to be partially overcome by increasing the leaf surface contact area of the electrodes, but the more reliable and proper way is to buffer the electrodes with an AD8244 when using an outboard ADC (or when using the inboard Analog Inputs if using the TTGO XI/Wemos XI board).  Two challenges with that are the added cost would justify using a more expensive, high input impedance ADC.  I don't know which one[s] would so work because input impedance is not usually specified in ADC datasheets.  The other challenge is the extremely tiny package (MSOP) of the AD8244, not to mention the additional failure risks whenever the complexity and parts count of any electronics device is increased.  With the tiny package, the part is very difficult solder and even just keep track of in a hand-constructed project...it is too easily dropped and not easily found afterward.  The 'M' in MSOP could just as well mean "microscopic".  That said, in the interest of simply moving forward with the project, I'm using the AD8244 in my own development environment, benefiting from the flexibility I gain from using that part to drive whatever ADC I want to develop for.  [My most recent source buying the AD8244.](https://www.arrow.com/en/products/ad8244armz-r7/analog-devices)  A recent enhancement of the circuit now allows electric current through the plant tissue of less than a nano ampere to be detected and observed.

        "...it is given unto you to know the mysteries of the kingdom of heaven..." Matt. 14:11

To repeat from few paragraphs above for the sake of emphasis:
Note to anyone wanting this device for tobacco, marijuana, coca, or similar uses: You'll not have ANY support from me for purposes which are not intended to make the world a better place.  Don't even try to get my support for those type purposes that make the world a worse place rather than better.  Notice the period at the end of that statement.
<p align="center">Plans and Arduino sketch for the training aid under GNU General Public License.  
This project is made possible in large part by DoSpace, a privately owned, non-profit technology library/makerspace in Omaha, NE.</p>

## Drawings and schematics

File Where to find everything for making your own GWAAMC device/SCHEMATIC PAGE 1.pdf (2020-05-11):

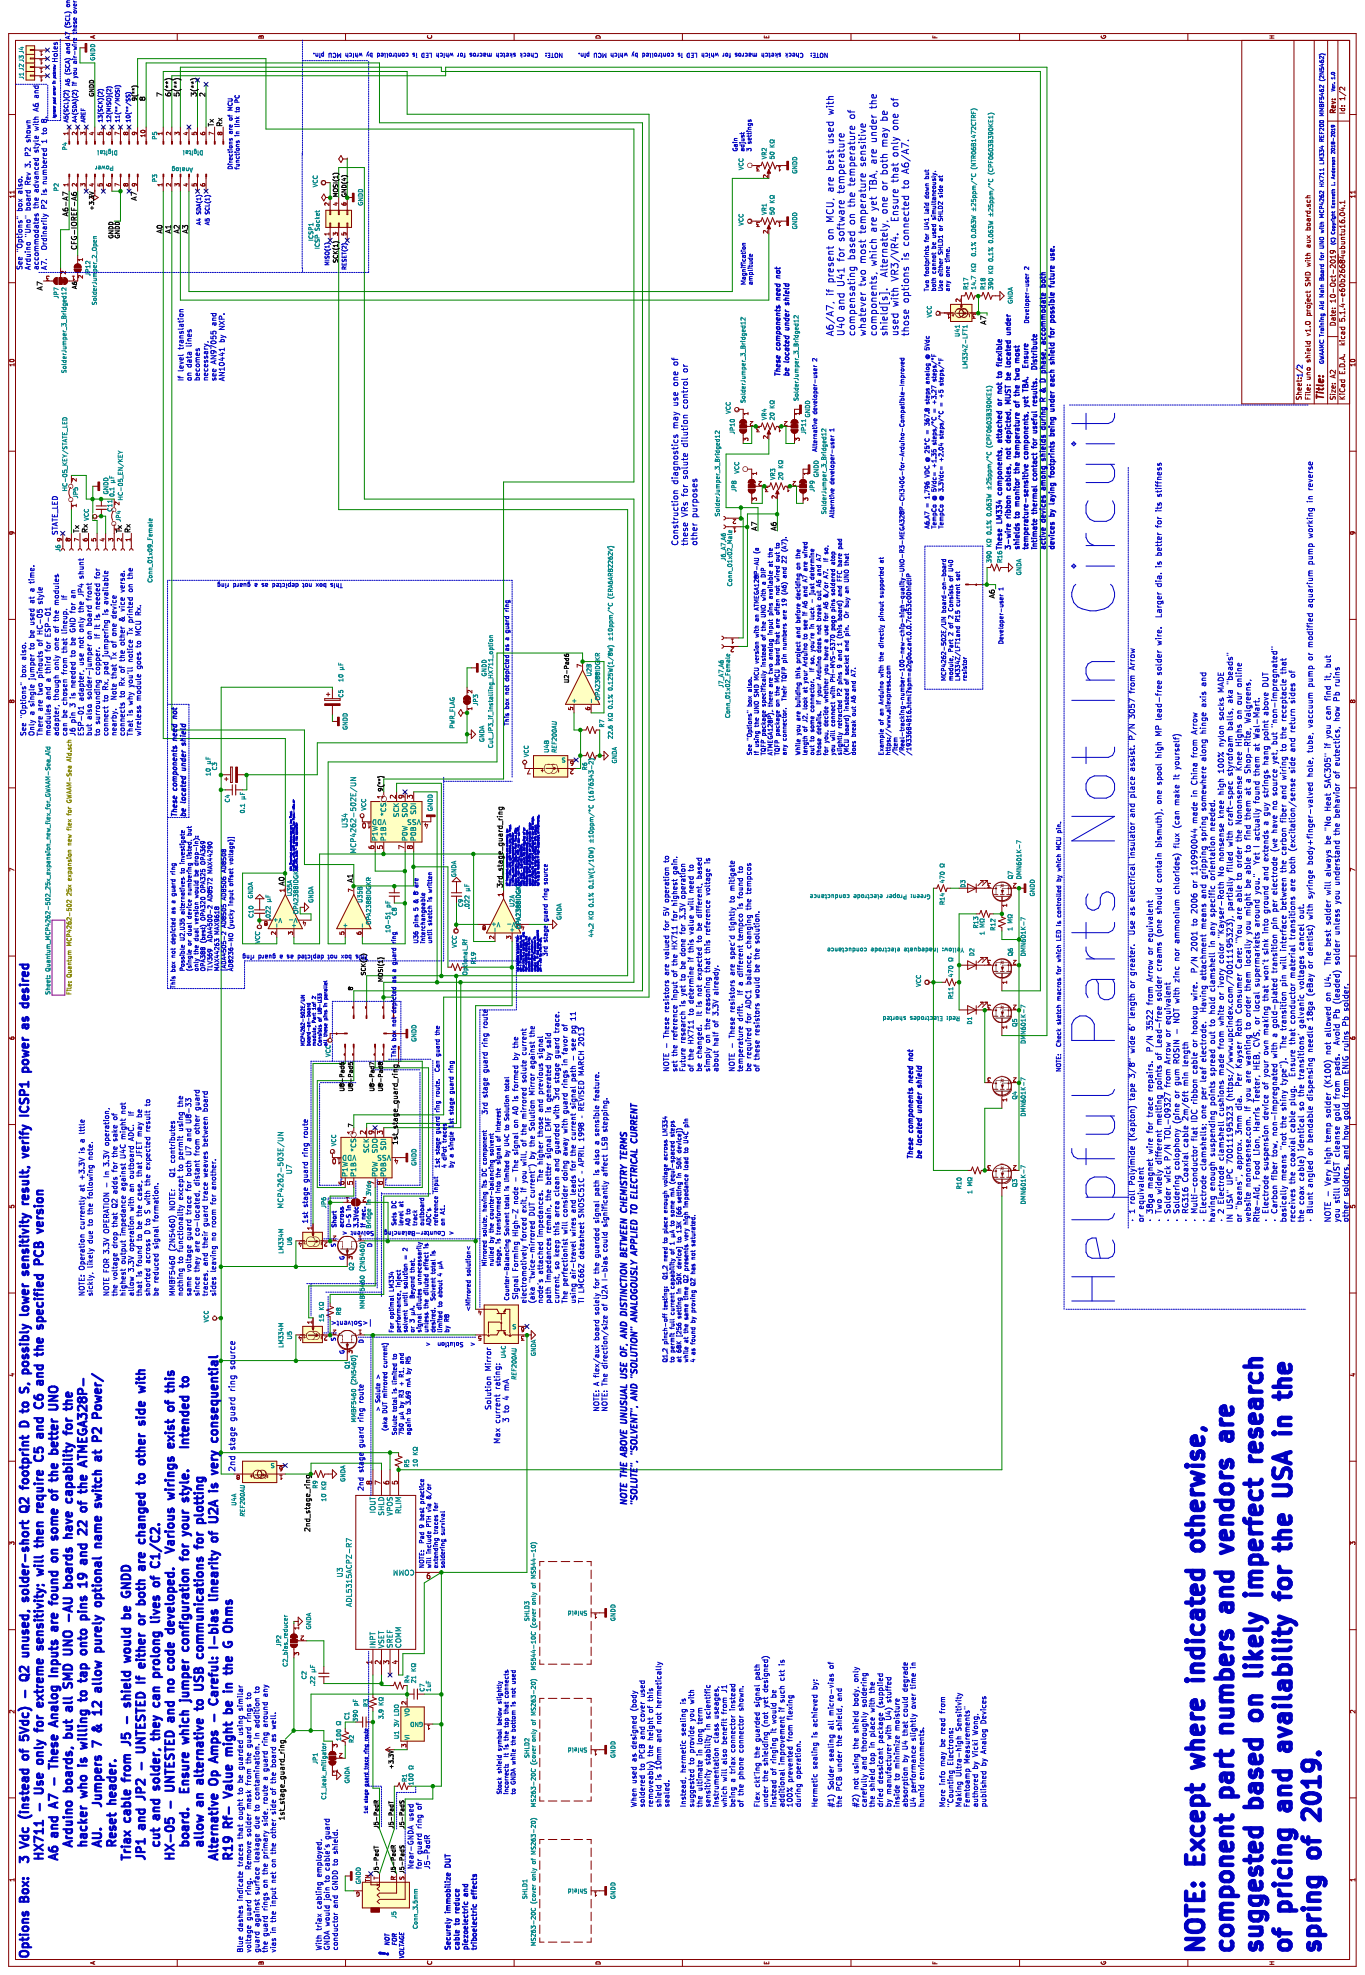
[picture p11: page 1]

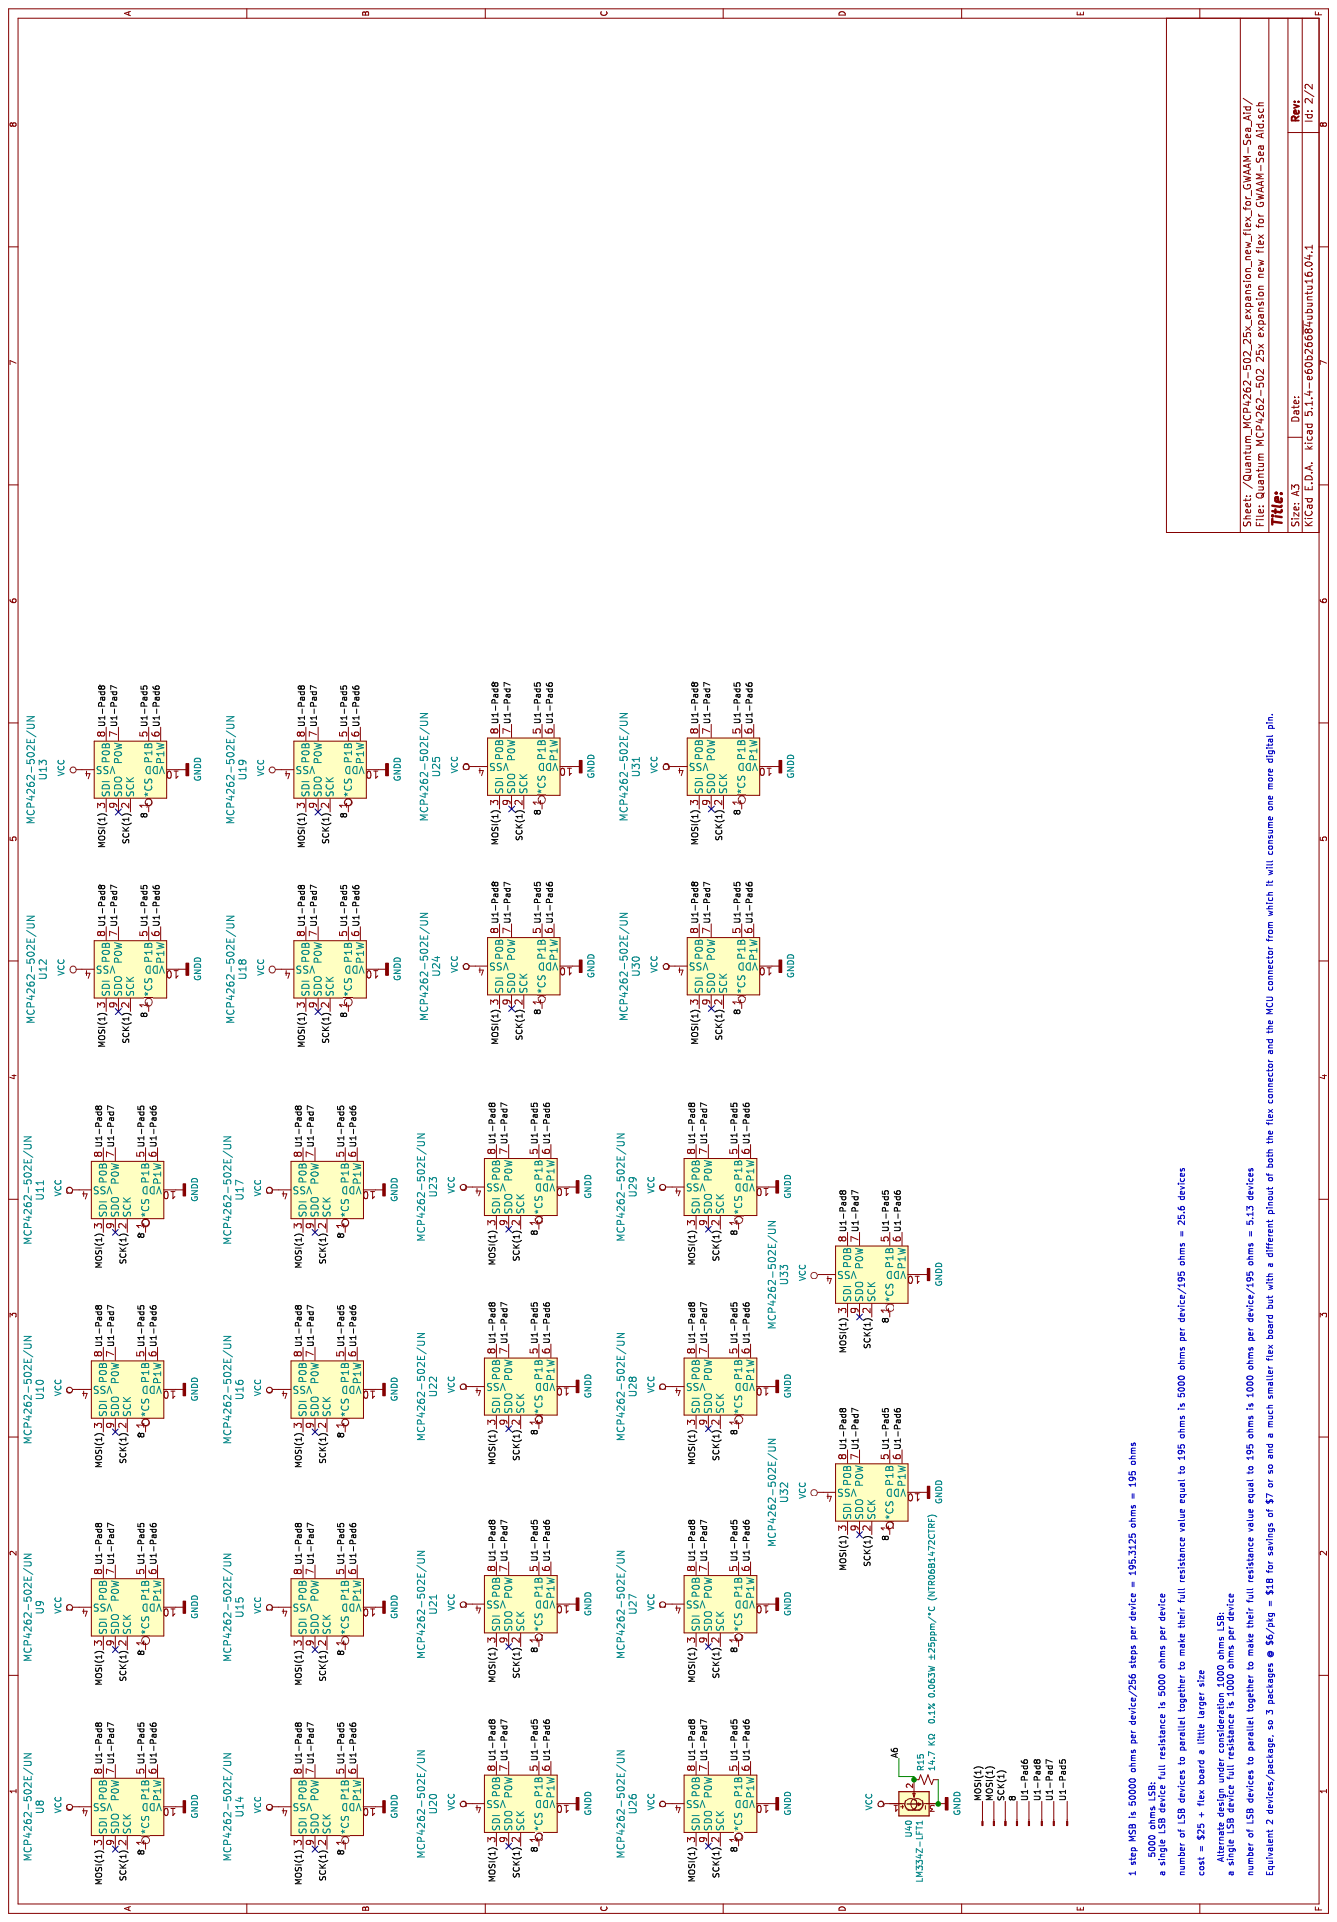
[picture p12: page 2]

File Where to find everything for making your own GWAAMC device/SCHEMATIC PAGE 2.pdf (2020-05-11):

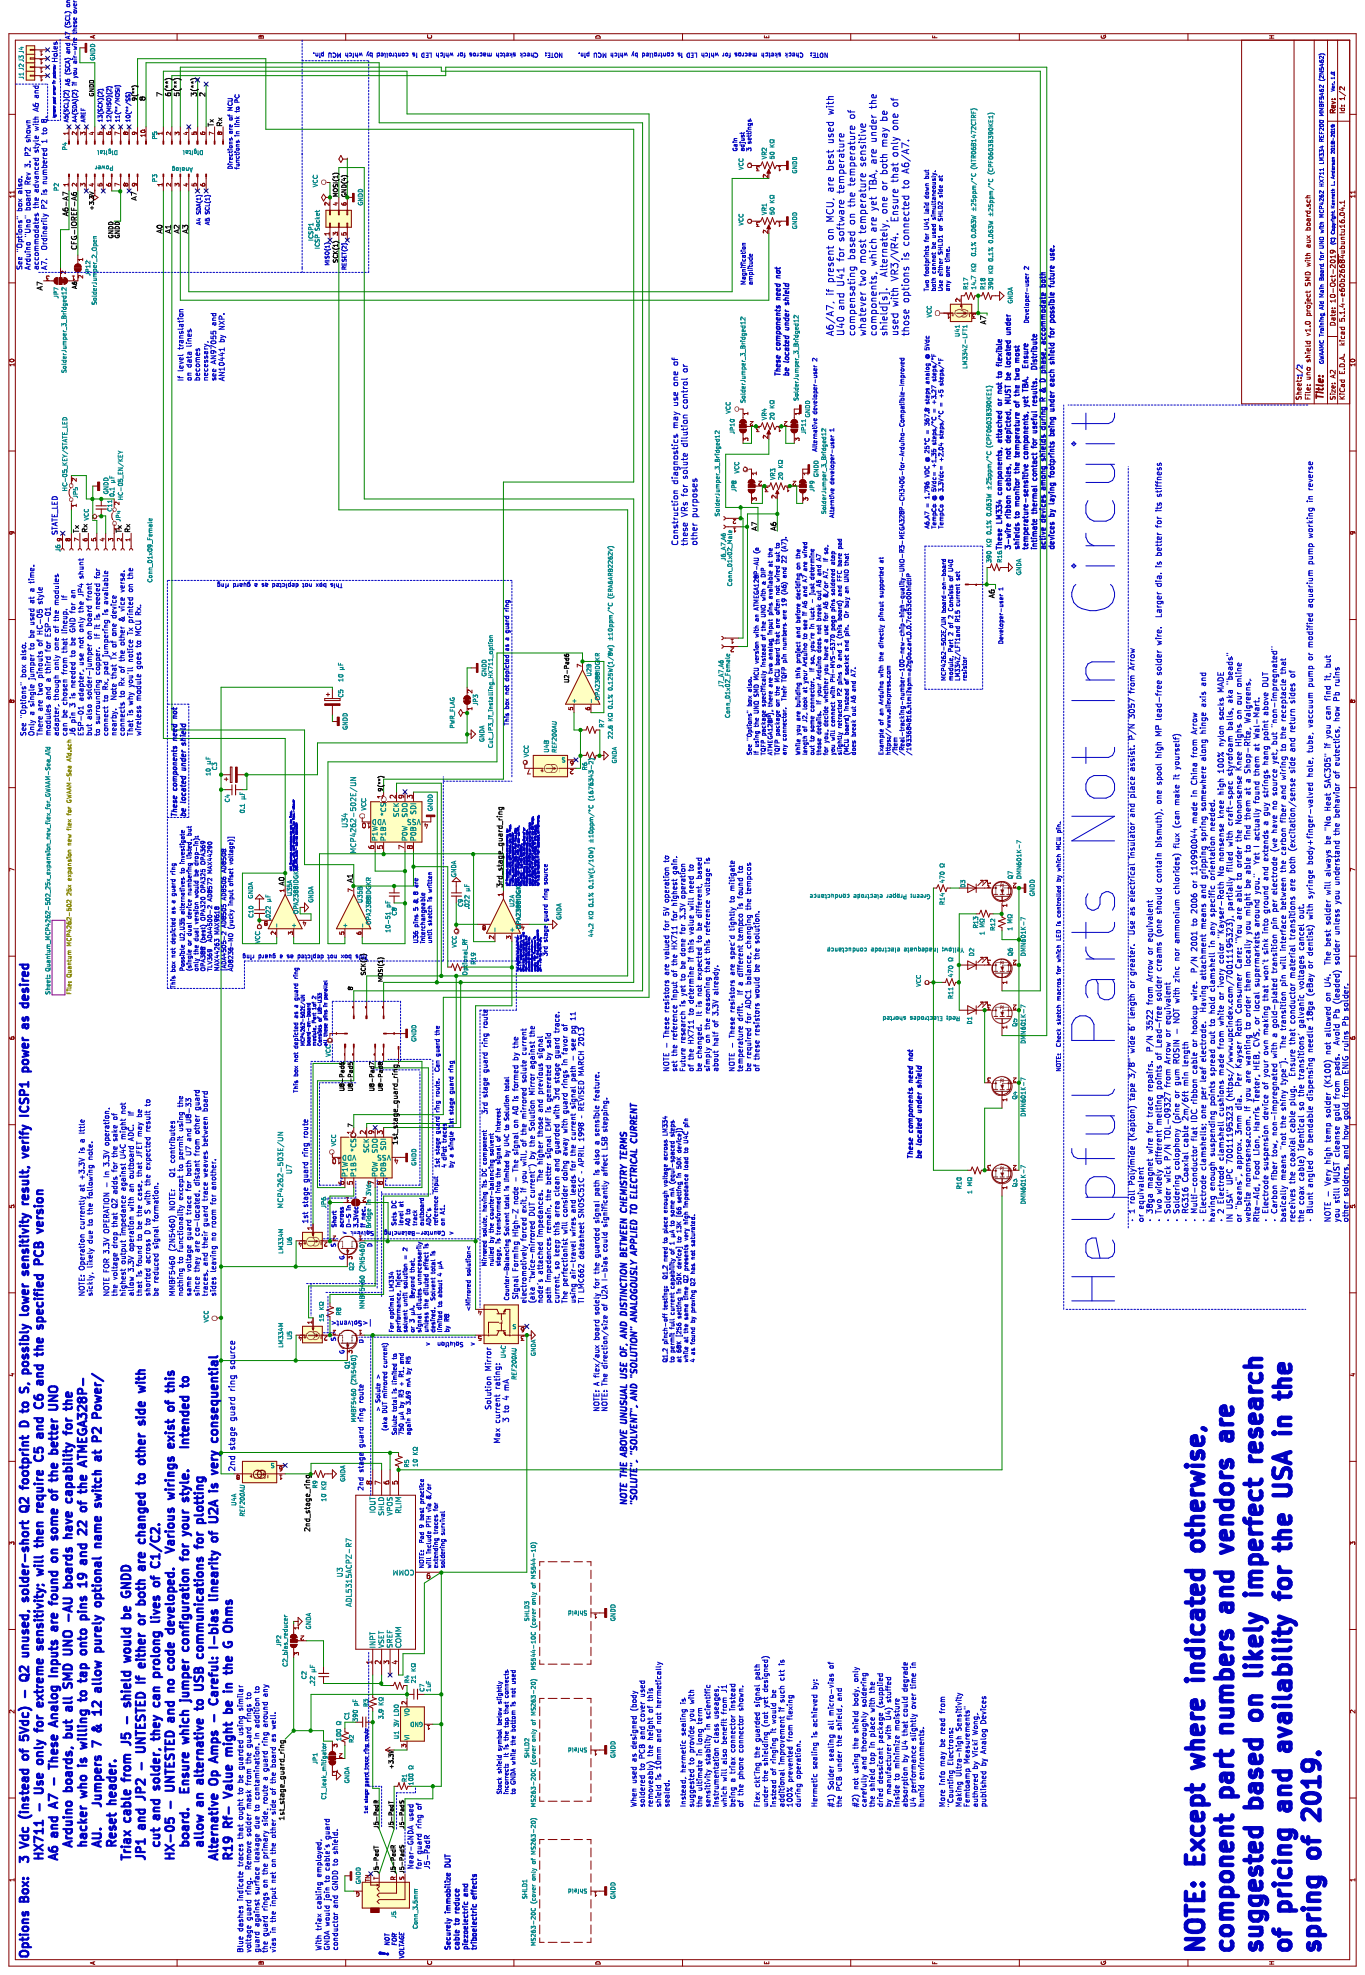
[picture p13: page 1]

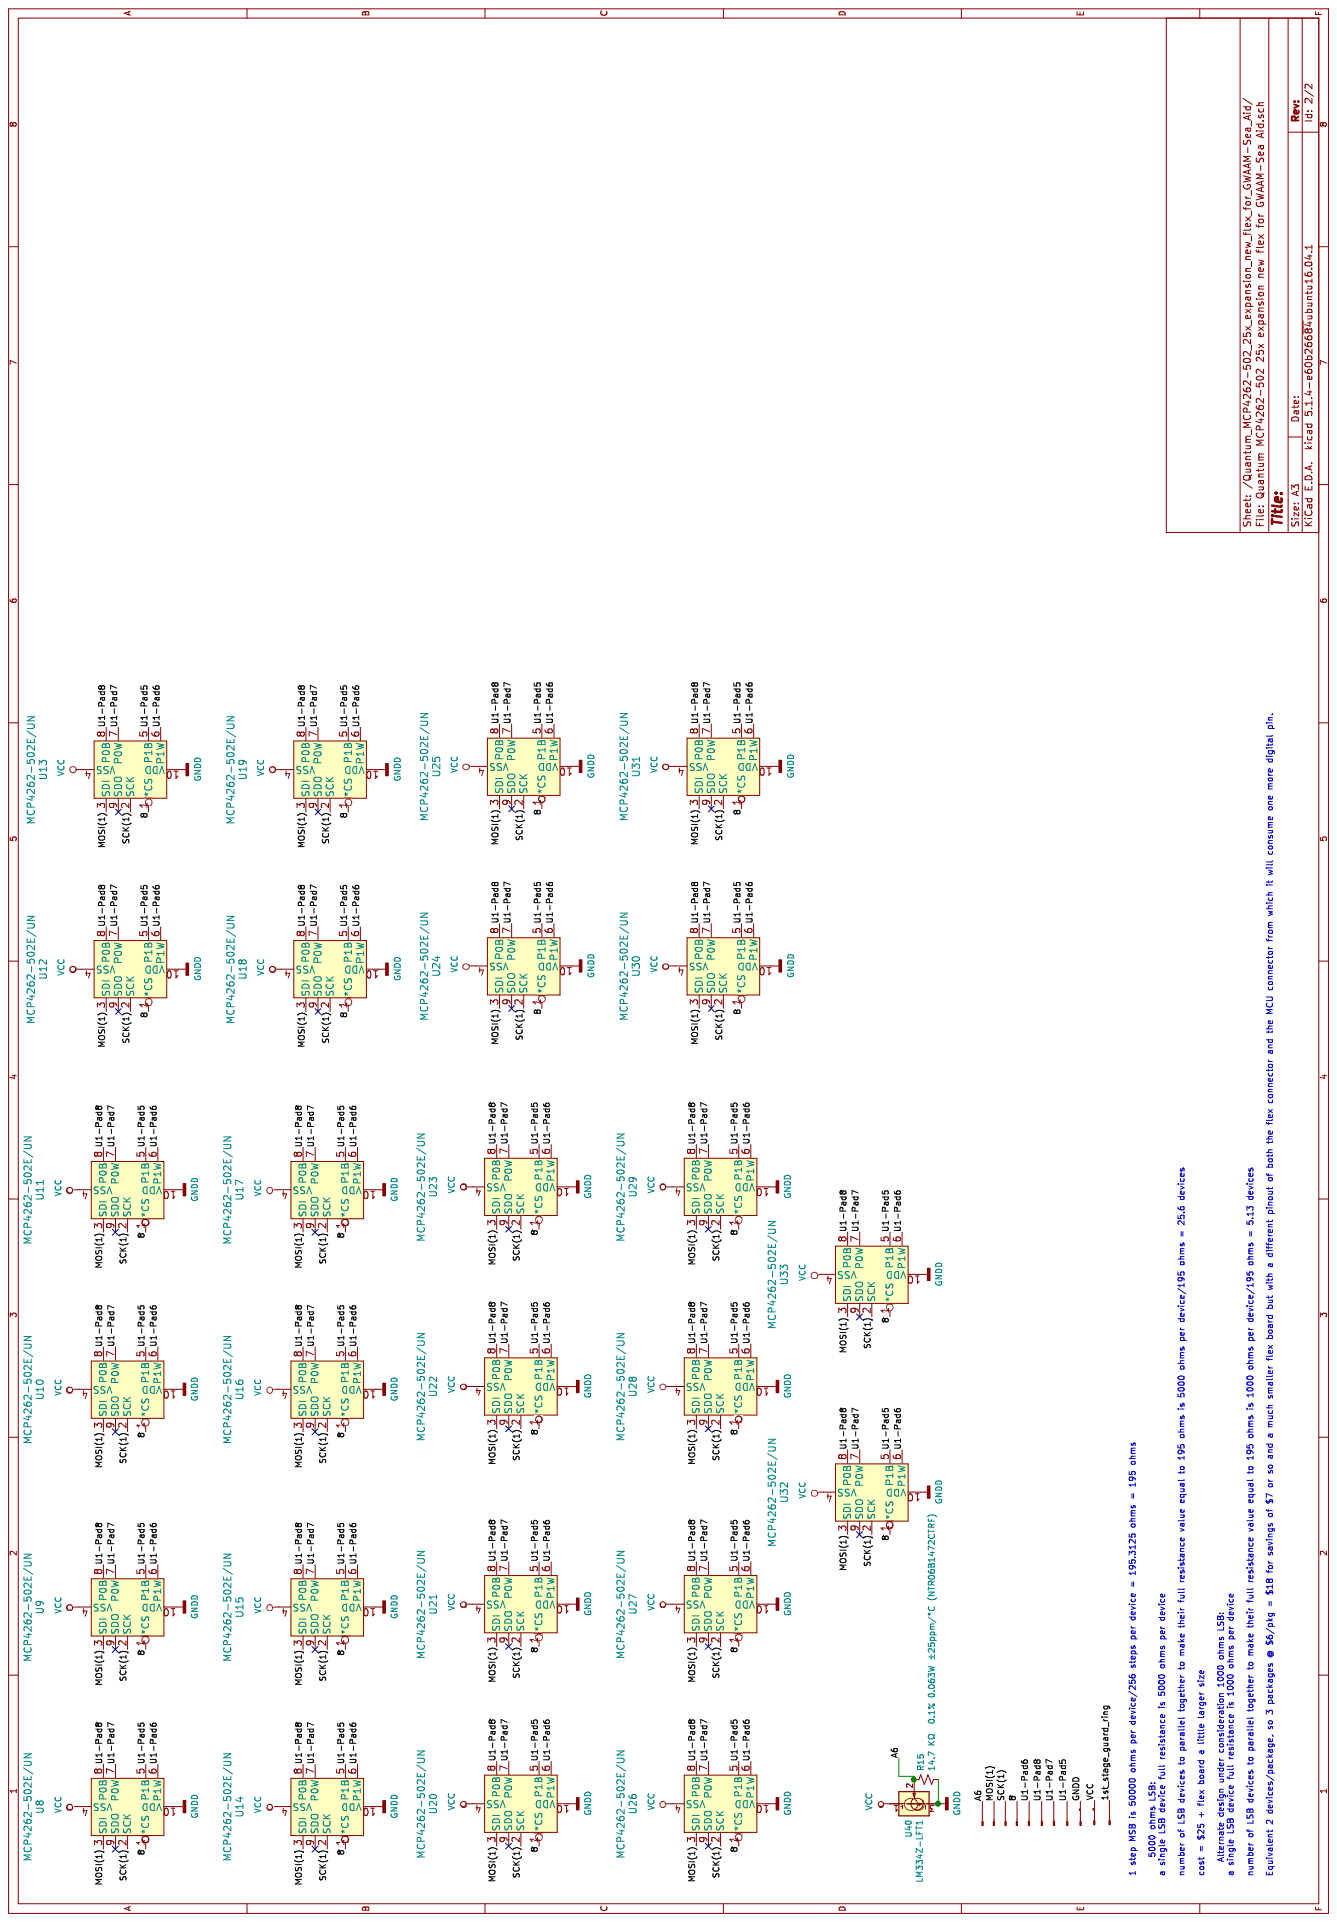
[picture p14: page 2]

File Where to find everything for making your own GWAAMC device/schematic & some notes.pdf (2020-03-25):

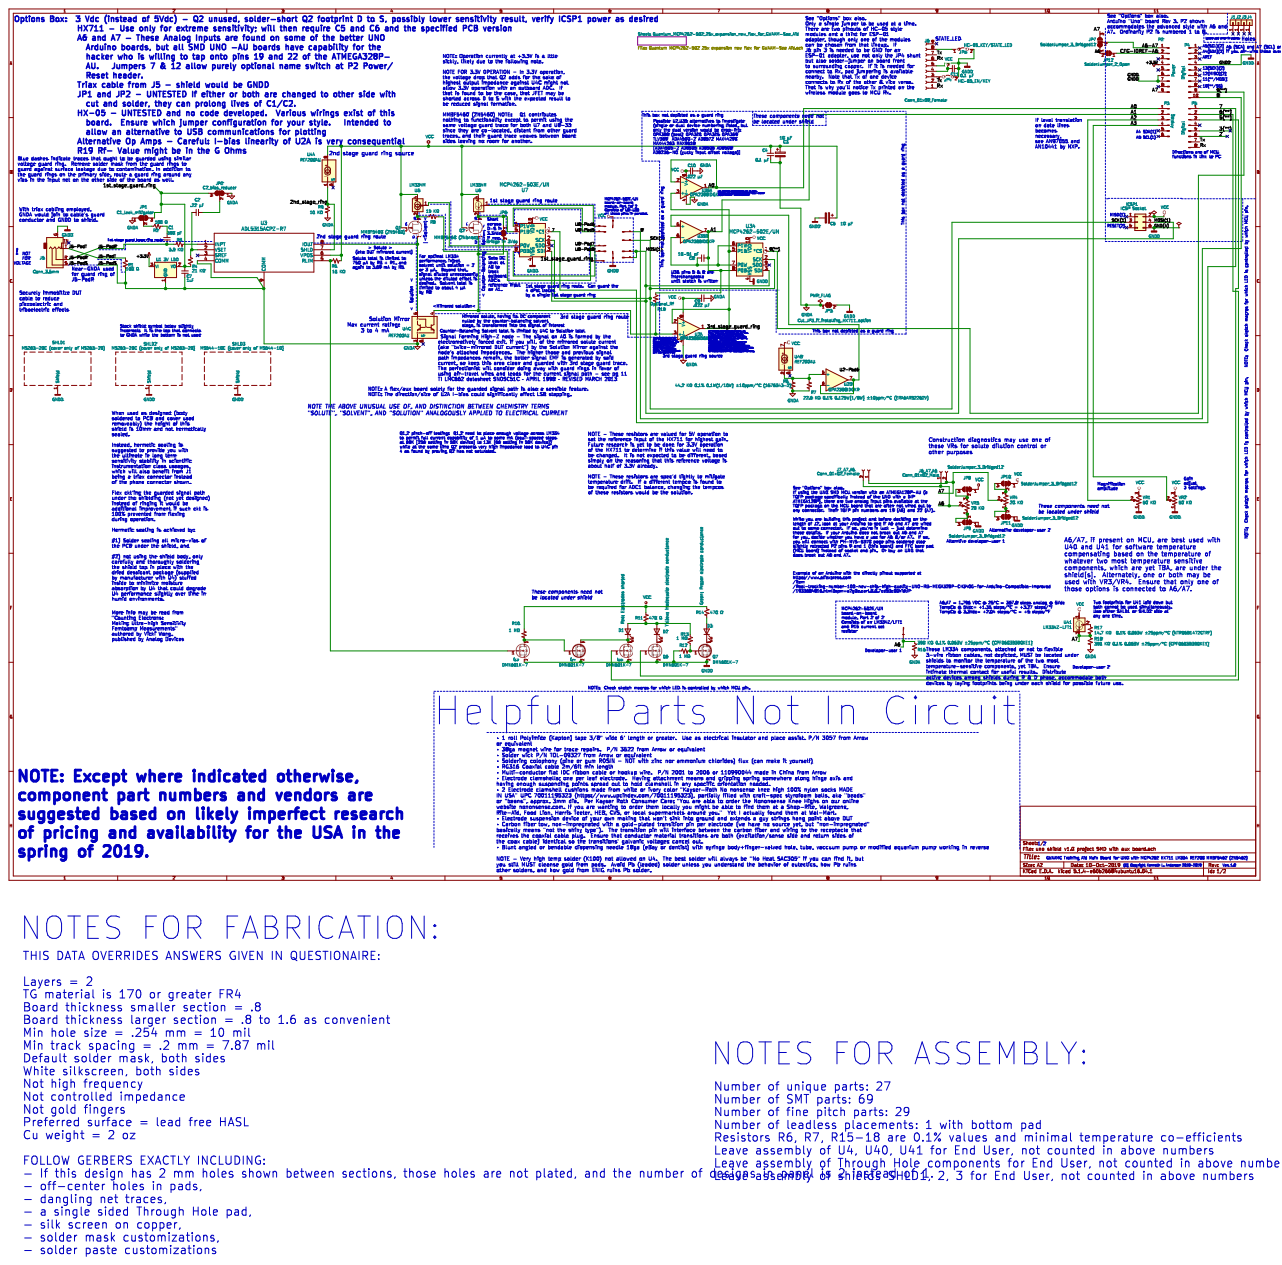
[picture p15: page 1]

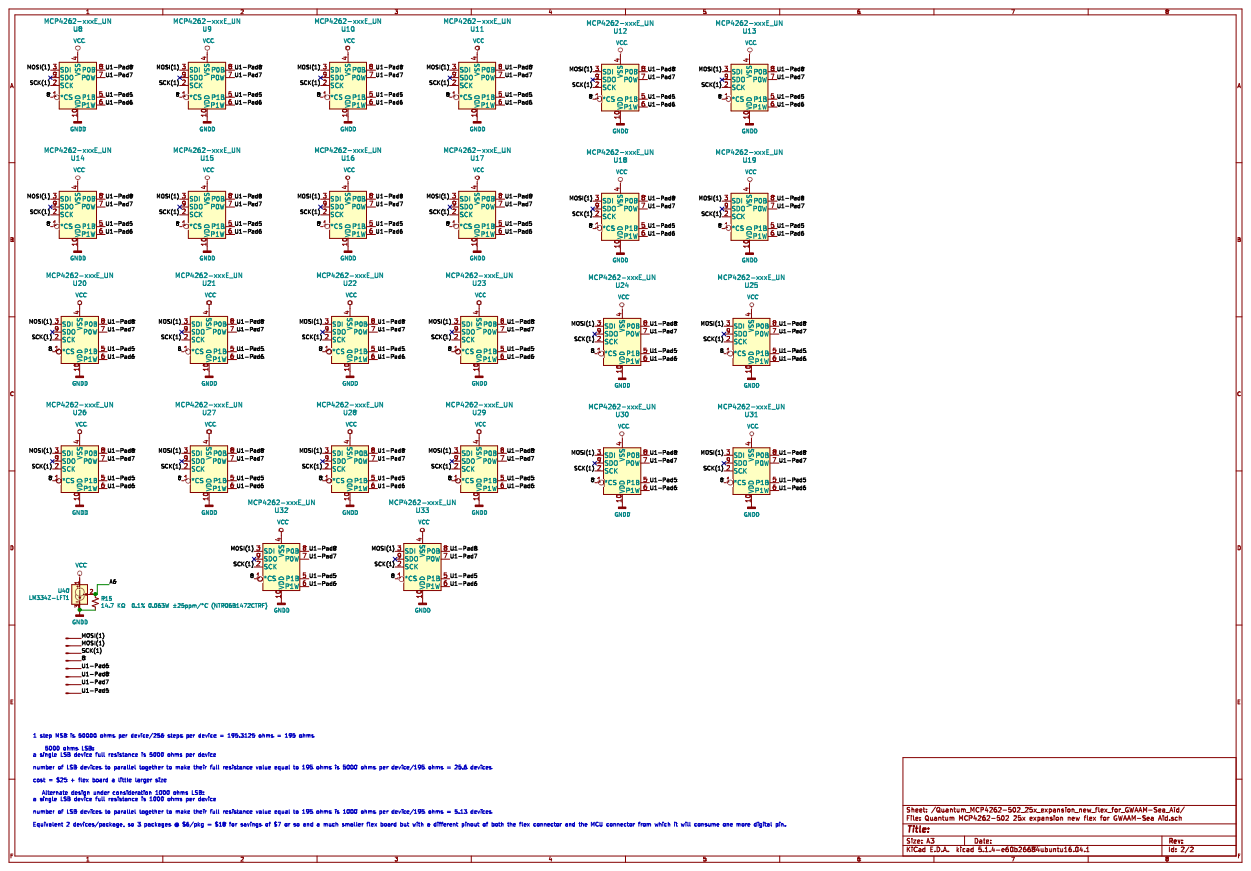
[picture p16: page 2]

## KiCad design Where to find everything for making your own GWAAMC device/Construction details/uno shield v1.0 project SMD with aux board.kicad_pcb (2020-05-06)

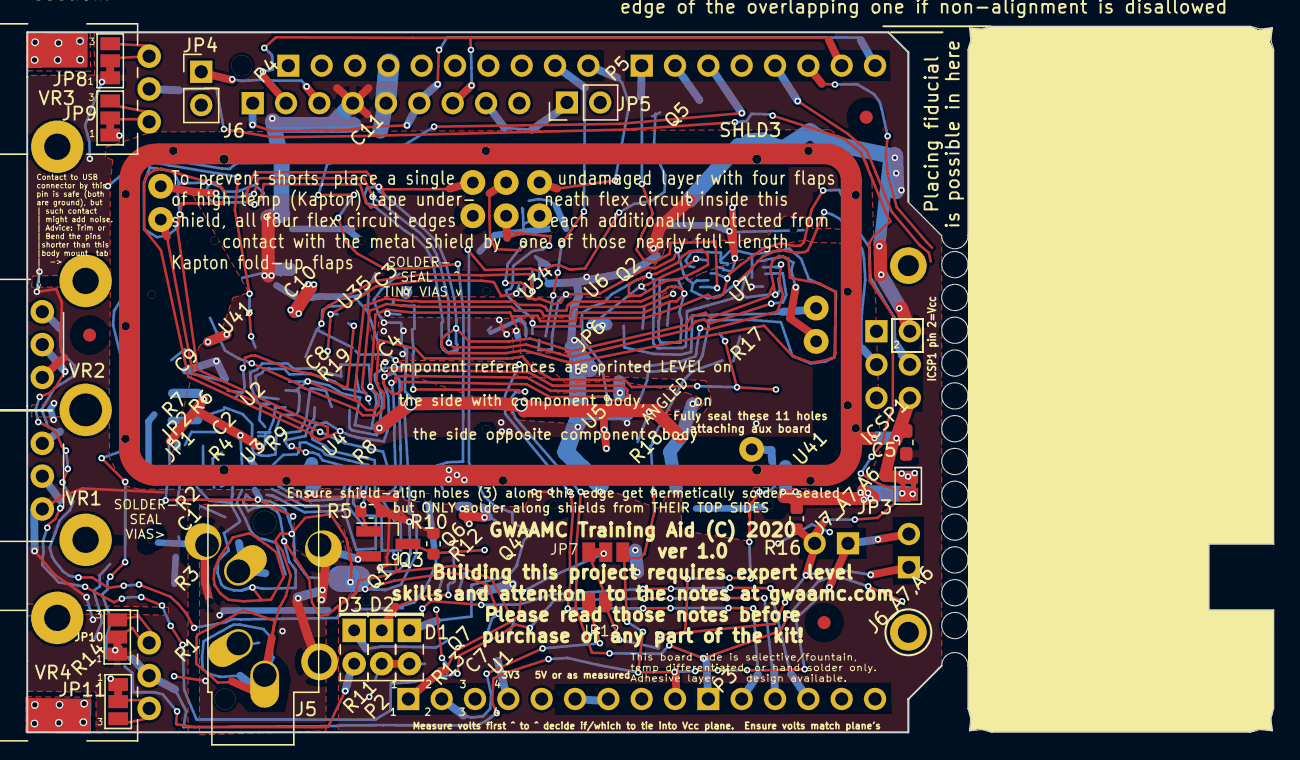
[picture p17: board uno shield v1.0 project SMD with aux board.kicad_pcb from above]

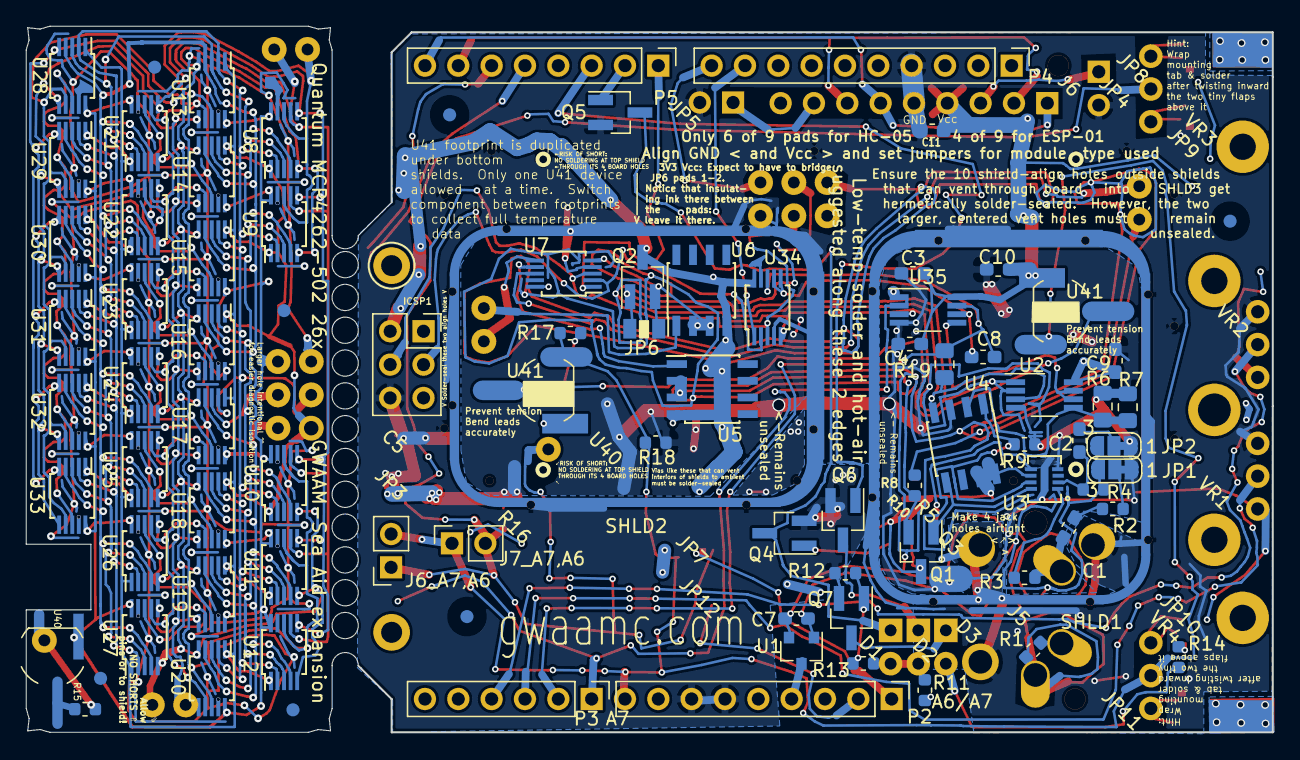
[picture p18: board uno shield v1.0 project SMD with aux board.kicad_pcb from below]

Board: 2 copper layers, 95.0 x 53.8 mm, 169 parts (100 on the bottom side), 59 nets.

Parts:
BreakGuide: MountingHole_2.1mm; BreakguideHole
BreakGuide#2, BreakGuide#3, BreakGuide#4, BreakGuide#5, BreakGuide#6, BreakGuide#7, BreakGuide#8, BreakGuide#9, BreakGuide#10, BreakGuide#11, BreakGuide#12, BreakGuide#13, BreakGuide#14, BreakGuide#15, BreakGuide#16, BreakGuide#17, BreakGuide#18, BreakGuide#19, BreakGuide#20, BreakGuide#21, BreakGuide#22, BreakGuide#23, BreakGuide#24, BreakGuide#25, BreakGuide#26, BreakGuide#27, BreakGuide#28: MountingHole_2.1mm; BreakguideHole
C1: 390 pF; C_0603_1608Metric_Pad1.05x0.95mm_HandSolder
C2: .22 µF; C_0603_1608Metric_Pad1.05x0.95mm_HandSolder
C3, C5: 10 µF; C_0603_1608Metric_Pad1.05x0.95mm_HandSolder
C4, C11: 0.1 µF; C_0603_1608Metric_Pad1.05x0.95mm_HandSolder
C7: 1uF; C_0603_1608Metric_Pad1.05x0.95mm_HandSolder
C8: 10-51 pF; C_0603_1608Metric_Pad1.05x0.95mm_HandSolder
C9, C10: .022 µF; C_0603_1608Metric_Pad1.05x0.95mm_HandSolder
D1: Red: Electrodes shorted; LED_Rectangular_W5.0mm_H2.0mm
D2: Yellow: Inadequate electrode conductance; LED_Rectangular_W5.0mm_H2.0mm_yellow
D3: Green: Proper electrode conductance; LED_Rectangular_W5.0mm_H2.0mm_green
FID1, FID2, FID3, FID4, FID5, FID6: Fiducial_1mm_Mask3mm
FID 7, FID 7#2, FID 7#3, FID 88: Fiducial_1mm_Mask3mm
ICSP1: ICSP Socket; PinSocket_2x03_P2.54mm_Vertical
J1, J2, J3, J4: CONN_01X01; TestPoint_Keystone_5010-5014_Multipurpose
J5: Conn_3.5mm; Jack_3.5mm_CUI_SJ1-3534NS_Horizontal_CircularHoles
J6: Conn_01x09_Female; PinSocket_1x09_P2.54mm_Vertical
J6_A7,A6: Conn_01x02_Male; PinSocket_1x02_P2.54mm_Vertical
J7, J8, J9, J10, J11, J12, J13, J14, J15, J16, J17: Conn_01x01_Male; Hole_0.5mm
J7_A7,A6: Conn_01x02_Female; PinSocket_1x02_P2.54mm_Vertical
J17#2, J18, J19, J20, J23, J24, J24#2, J24#3, J24#4, J25, J32: Conn_01x01_Male; Banana_Jack_2mm_1Pin
JP1: C1_leak_mitigator; SolderJumper-3_P1.3mm_Bridged12_RoundedPad1.0x1.5mm_NumberL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
JP2: C2_bias_reducer; SolderJumper-3_P1.3mm_Bridged12_RoundedPad1.0x1.5mm_NumberL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
JP3: Cut_JP3_if_installing_HX711_option; SolderJumper-2_P1.3mm_Bridged2Bar_Pad1.0x1.5mm
JP4: HC-05_EN/KEY; PinHeader_1x02_P2.54mm_Vertical
JP5: HC-05_KEY/STATE_LED; PinHeader_1x02_P2.54mm_Vertical
JP6: Bridge in 3Vdc; SolderJumper-2_P1.3mm_Open_Pad1.0x1.5mm
JP7: SolderJumper_3_Bridged12; SolderJumper-3_P1.3mm_Bridged12_Pad1.0x1.5mm
JP8, JP9, JP10, JP11: SolderJumper_3_Bridged12; SolderJumper-3_P1.3mm_Bridged12_Pad1.0x1.5mm_NumberLabels
JP12: SolderJumper_2_Open; SolderJumper-2_P1.3mm_Open_RoundedPad1.0x1.5mm
P2: Power; PinHeader_1x09_P2.54mm_Vertical
P3: Analog; PinHeader_1x06_P2.54mm_Vertical
P4: Digital; PinHeader_1x10_P2.54mm_Vertical
P5: Digital; PinHeader_1x08_P2.54mm_Vertical
Q1, Q2: MMBF5460 (2N5460); SOT-23_Handsoldering
Q3, Q4, Q5, Q6, Q7: DMN601K-7; SOT-23_Handsoldering
R1, R2: 100 Ω; R_0603_1608Metric
R3: 3.9 KΩ; R_0603_1608Metric
R4: 21 KΩ; R_0603_1608Metric
R5, R9: 10 KΩ; R_0603_1608Metric
R6: 44.2 KΩ 0.1% 0.1W(1/10W) ±10ppm/°C (1676343-2); R_0805_2012Metric_Pad1.15x1.40mm_HandSolder
R7: 22.6 KΩ 0.1% 0.125W(1/8W) ±10ppm/°C (ERA6ARB2262V); R_0805_2012Metric_Pad1.15x1.40mm_HandSolder
R8: 15 KΩ; R_0603_1608Metric
R10, R12, R13: 1 MΩ; R_0603_1608Metric
R11, R14: 470 Ω; R_0603_1608Metric
R15, R17: 14.7 KΩ 0.1% 0.063W ±25ppm/°C (NTR06B1472CTRF); R_0603_1608Metric
R16, R18: 390 KΩ 0.1% 0.063W ±25ppm/°C (CPF0603B390KE1); R_0603_1608Metric
R19: Optional_Rf; R_0805_2012Metric_Pad1.15x1.40mm_HandSolder
SHLD1, SHLD2: MS263-20C (cover only of MS263-20); Masach_Tech_MS26320_26x19.50mm
SHLD3: MS544-10C (cover only of MS544-10); Masach_Tech_MS54410_54x23.90mm
U1: 3V LDO; SOT-23
U2, U35: OPA2388IDGKR; VSSOP-8_3.0x3.0mm_P0.65mm
U3: ADL5315; ADL5315ACPZ-R7
U4: REF200AU; SOIC-8_3.9x4.9mm_P1.27mm
U5, U6: LM334M; SOIC-8_3.9x4.9mm_P1.27mm
U7: MCP4262-503E/UN; MSOP-10_3x3mm_P0.5mm
U8, U9, U10, U11, U12, U13, U14, U15, U16, U17, U18, U19, U20, U21, U22, U23, U24, U25, U26, U27, U28, U29, U30, U31, U32, U33, U34: MCP4262-502E/UN; MSOP-10_3x3mm_P0.5mm
U40: LM334Z; TO-92_Spread_for_LM334Z
U41, U41#2: LM334Z; TO-92_full pads_for_LM334Z
VR1, VR2: 50 KΩ; Potentiometer_Bourns_PTV09A-2_Single_Horizontal
VR3, VR4: 20 KΩ; Potentiometer_Bourns_PTV09A-1_Single_Vertical

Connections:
+3V3: P2.4, U1.3
/1st_stage_guard_ring: C7.1, J12.1, J24#3.1, JP1.3, JP2.3, R4.2, U1.2
/2nd_stage_ring: R9.1, U3.7, U4.1
/3rd_stage_guard_ring: U2.1, U2.2, U34.5, U35.3
/5(**): P5.3, Q6.1
/6(**): P5.2, Q5.1
/7: P5.1, U7.1
/8: J14.1, J23.1, P4.10, U8.1, U9.1, U10.1, U11.1, U12.1, U13.1, U14.1, U15.1, U16.1, U17.1, U18.1, U19.1, U20.1, U21.1, U22.1, U23.1, U24.1, U25.1, U26.1, U27.1, U28.1, U29.1, U30.1, U31.1, U32.1, U33.1
/9(**): P4.9, U34.1
/A0: P3.1, U35.1, U35.2
/A1: C8.1, P3.2, R19.1, U34.8, U35.7
/A2: P3.3, VR1.2
/A3: P3.4, VR2.2
/A6: J6_A7,A6.1, J7_A7,A6.2, J17.1, J17#2.1, JP7.1, JP12.2, R15.2, R16.1, U40.3, VR3.2
/A6-A7: JP7.2, P2.1
/A7: J6_A7,A6.2, J7_A7,A6.1, JP7.3, P2.9, R17.2, R18.1, U41.3, U41#2.3, VR4.2
/CFG-IOREF-A6: JP12.1, P2.2
/J5-PadR: C1.1, J5.R, R3.1
/J5-PadT: J5.T, R1.2
/MOSI(1): ICSP1.4, J16.1, J24#2.1, U7.3, U8.3, U9.3, U10.3, U11.3, U12.3, U13.3, U14.3, U15.3, U16.3, U17.3, U18.3, U19.3, U20.3, U21.3, U22.3, U23.3, U24.3, U25.3, U26.3, U27.3, U28.3, U29.3, U30.3, U31.3, U32.3, U33.3, U34.3
/Rx: J6.1, J6.6, P5.8
/SCK(1): ICSP1.3, J15.1, J25.1, U7.2, U8.2, U9.2, U10.2, U11.2, U12.2, U13.2, U14.2, U15.2, U16.2, U17.2, U18.2, U19.2, U20.2, U21.2, U22.2, U23.2, U24.2, U25.2, U26.2, U27.2, U28.2, U29.2, U30.2, U31.2, U32.2, U33.2, U34.2
/Tx: J6.2, J6.7, P5.7
/U8-Pad5: J8.1, J19.1, U7.6, U8.5, U9.5, U10.5, U11.5, U12.5, U13.5, U14.5, U15.5, U16.5, U17.5, U18.5, U19.5, U20.5, U21.5, U22.5, U23.5, U24.5, U25.5, U26.5, U27.5, U28.5, U29.5, U30.5, U31.5, U32.5, U33.5
/U8-Pad6: J7.1, J20.1, U6.1, U8.6, U9.6, U10.6, U11.6, U12.6, U13.6, U14.6, U15.6, U16.6, U17.6, U18.6, U19.6, U20.6, U21.6, U22.6, U23.6, U24.6, U25.6, U26.6, U27.6, U28.6, U29.6, U30.6, U31.6, U32.6, U33.6
/U8-Pad7: J10.1, J32.1, R8.1, U8.7, U9.7, U10.7, U11.7, U12.7, U13.7, U14.7, U15.7, U16.7, U17.7, U18.7, U19.7, U20.7, U21.7, U22.7, U23.7, U24.7, U25.7, U26.7, U27.7, U28.7, U29.7, U30.7, U31.7, U32.7, U33.7
/U8-Pad8: J11.1, J18.1, U7.8, U8.8, U9.8, U10.8, U11.8, U12.8, U13.8, U14.8, U15.8, U16.8, U17.8, U18.8, U19.8, U20.8, U21.8, U22.8, U23.8, U24.8, U25.8, U26.8, U27.8, U28.8, U29.8, U30.8, U31.8, U32.8, U33.8
GNDA: C3.2, C4.2, C7.2, C9.1, C10.1, J5.S, JP1.1, JP2.1, JP3.1, R1.1, R6.2, R7.2, R9.2, R16.2, R18.2, U1.1, U2.4, U3.4, U3.9, U4.3, U35.4
GNDD: C5.2, C11.1, ICSP1.6, J5.G, J6.5, J13.1, J24.1, JP3.2, JP4.2, JP5.2, JP9.1, JP11.1, P2.6, P2.7, P4.4, Q3.2, Q4.2, Q5.2, Q6.2, Q7.2, R12.1, SHLD1.1, SHLD2.1, SHLD3.1, U7.4, U8.4, U9.4, U10.4, U11.4, U12.4, U13.4, U14.4, U15.4, U16.4, U17.4, U18.4, U19.4, U20.4, U21.4, U22.4, U23.4, U24.4, U25.4, U26.4, U27.4, U28.4, U29.4, U30.4, U31.4, U32.4, U33.4, U34.4, VR1.1, VR2.1
unnamed: C1.2, R2.1
unnamed: C2.1, R4.1, U3.2
unnamed: C2.2, JP2.2
unnamed: C8.2, U34.6, U34.7, U35.6
unnamed: D1.1, Q4.3, Q5.3
unnamed: D1.2, D2.2, R11.2, R13.2
unnamed: D2.1, Q6.3
unnamed: D3.1, Q7.3
unnamed: D3.2, R14.2
unnamed: J6.3, JP4.1
unnamed: J6.8, JP5.1
unnamed: JP1.2, R2.2
unnamed: JP6.1, Q2.2, U6.2, U6.3, U7.5
unnamed: JP6.2, Q2.1, R19.2, U2.3, U4.4
unnamed: JP8.2, JP8.3, VR3.3
unnamed: JP9.2, JP9.3, VR3.1
unnamed: JP10.2, JP10.3, VR4.3
unnamed: JP11.2, JP11.3, VR4.1
unnamed: Q1.1, U3.8, U4.5
unnamed: Q1.2, R8.2, U5.2, U5.3
unnamed: Q3.1, R5.1, U3.5
unnamed: Q3.3, Q4.1, R10.2
unnamed: Q7.1, R12.2, R13.1
unnamed: R3.2, U3.1
unnamed: R6.1, R7.1, U2.5, U4.2
unnamed: R15.1, U40.2
unnamed: R17.1, U41.2, U41#2.2
unnamed: U2.6, U2.7, U35.5
unnamed: U5.1, U7.7
VCC: C3.1, C4.1, C5.1, C9.2, C10.2, C11.2, ICSP1.2, J6.4, J9.1, J24#4.1, JP8.1, JP10.1, Q1.3, Q2.3, R5.2, R10.1, R11.1, R14.1, U2.8, U3.6, U4.7, U4.8, U5.4, U6.4, U7.10, U8.10, U9.10, U10.10, U11.10, U12.10, U13.10, U14.10, U15.10, U16.10, U17.10, U18.10, U19.10, U20.10, U21.10, U22.10, U23.10, U24.10, U25.10, U26.10, U27.10, U28.10, U29.10, U30.10, U31.10, U32.10, U33.10, U34.10, U35.8, U40.1, U41.1, U41#2.1, VR1.3, VR2.3

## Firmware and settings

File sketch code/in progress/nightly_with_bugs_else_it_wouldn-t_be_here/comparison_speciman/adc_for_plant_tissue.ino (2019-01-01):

//        BEFORE COMPILING THIS SKETCH you must set or confirm the following preprocessor macros appropriately for your configuration and preferences !!!
#define LM334_BRIDGES 1                                        //Number of digipot Wheatstones you have topped with LM334s each leg, (schematically wired before bare DPot bridges) but this sketch revision level not tested beyond 1.  Remove if using Wheatstone bridge with only standard or DPot resistors.  make this the number of bridges with upper resistive elements being LM334s controllable with the MCP4162-104 pots
#define DPOTS_PER_LM334_LEG 3                                  //Not yet tested for any setting except 3, so verify it before trusting fully.  Due to their significant temperature coefficient, LM334s need to be used in pairs so their tempco offsets each other's; i.e., LM334 legs are invalid unless bridged with both legs topped by a LM334
//FUTURE #define BARE_DPOT_LEG_BRIDGES                         //(after LM334 bridges in terms of pin number order) Subject to change NOT CODED FOR YET, but this makes effects of DPot settings be reversed from when LM334s are used.  Note that higher values of DPot leg resistances are expected to be required.  This could mean more DPots per leg increasing the likelihood 74LV138 decoding will be necessary.
//FUTURE #define BARE_DPOT_LEGS_UNBRIDGED                    //(after active bridges in terms of pin number order, passive bridges using manual pots might include these legs)Subject to change NOT CODED FOR YET, but this makes effects of DPot settings be reversed from when LM334s are used.  Note that higher values of DPot leg resistances are expected to be required.  This could mean more DPots per leg.
#define INBOARDS_PLOTTED 2                              //The number of consecutive analog pins to plot, beginning with PIN_A0
//#define OUTBOARDS_PLOTTED 1                             //The number of consecutive "highest-sensitivity ADC" pins to plot, beginning with A0 and, if double-ended, A1.  OUTBOARD ADC ONLY - DOES _NOT_ INCLUDE INBOARD ANALOG INPUT PINS
//#define MAGNIFICATION_FACTOR 5                                 //Activates the plotting of magnified traces in all ADC linespaces; upper limit somewhere less than 4,294,967,295. Note: you can disable displaying magnified traces altogether by not defined this macro at all. Proper use of SUPERIMPOSE_FIRST_INBOARDS_IN_PAIRS will also disable magnified traces of the first two analog inputs
#define HIGHEST_SENSI_OUTBOARD_ADC_TYPE HX711                  //Proposing that "ADS1231" covers ADS1231; could make this "ADS1232" ( ADS1232), "ADS1242" ( ADS1242), "AD779x" ( AD779x), "AD7780" ( AD7780), "HX711" (HX711), "ADS1X15" ( ADS1015 or ADS1115), "MAX112x0" (MAX112X0...) or "LTC2400" (LTC2400) but code not included in v.FREE; ONLY ONE TYPE ALLOWED
#define HIGHEST_BIT_RES_FROM_HIGHEST_SENSI_OUTBOARD_ADC 24     //All ADC values will get scaled to the single-ended aspect of this,  15 is ADS1115 single-ended, 16 for double-ended when two LM334s are used.  change to 11 for ADS1015 single-ended or 12 with two LM334s, (future: change to 24 for HX711--NO b/c there is the ADS1231 at 24 bits)
#define SAMPLE_TIMES 2                                         //To better average out artifacts we over-sample and average.  This value can be tweaked by you to ensure neutralization of power line noise or harmonics of power supplies, etc.....
//#define MINIMIZE_COMMUNICATIONS_CLUTTER_FOR_HIGHER_MAX_SPEED_ONLY_COMPATIBLE_FOR_OFFICIAL_ARDUINO_IDE true//Doesn't catch much - future plan is to have different levels including DEBUG in this
#define MOST_PROBLEMATIC_INTERFERENCE_FREQ 60                                                               //This is here just in case you think that you might have some interference on a known frequency.
#define DELAY_TIME_BETWEEN_SAMPLES_MS ( 1000 / MOST_PROBLEMATIC_INTERFERENCE_FREQ / SAMPLE_TIMES )          //COARSE ADJUST
#define DELAY_TIME_BETWEEN_SAMPLES_US ( ( ( 1000000 / MOST_PROBLEMATIC_INTERFERENCE_FREQ ) - ( DELAY_TIME_BETWEEN_SAMPLES_MS * SAMPLE_TIMES * 1000 ) ) / SAMPLE_TIMES ) //FINE ADJUST.  THIS GETS ADDED TO COARSE ADJUST, PRECISION = TRUNCATED PRAGMATICALLY TO uSec TO ACKNOWLEDGE SOME OVERHEAD FOR LOOPING SUPPORT CODE   // End of this part of code update
#define FIRST_ANALOG_PIN_DIGITAL_NUMBER_FOR_BOARDS_NOT_HAVING_ANALOG_PINS_DEFINED_BY_PIN_A0_TYPE_DEFINES 14 //Some boards don't have good definitions and constants for the analog pins :-(
#define PERCENT_OF_LINESPACE_MAGNIFIED_VIEW_SKIPS_WHEN_REPOSITIONED_WHEN_LINESPACE_LIMITS_GET_EXCEEDED 85   //BETWEEN 0 AND 100 indicating how much of the display region in percent to skip when magnified view trace has to get repositioned because trace would be outside region bounds; NO BOUNDS CHECKING IS PROVIDED!!!
#define ANALOG_INPUT_BITS_OF_BOARD 10                                        //Most Arduino boards are 10-bit resolution, but some can be 12 bits.  For known 12 bit boards (SAM, SAMD and TTGO XI architectures), this gets re-defined below, so generally this can be left as 10 even for those boards
#define SECONDS_THAT_A_LGT8FX8E_HARDWARE_SERIAL_NEEDS_TO_COME_UP_WORKING 9   //8 works only usually
#define HIGHEST_SENSI_PGA_GAIN_FACTOR 128                                    //For HX711 a gain of 128 gets applied to channel A. Available to you for your own use PGA=Programmable Gain Amplifier: many ADCs will correlate a gain of one with full-scale being rail-to-rail, while a gain of anything higher correlates to full-scale being in the mV range (most sensitive and most noise-susceptible).
#define MIN_WAIT_TIME_BETWEEN_PLOT_POINTS_MS 1                              //Sets a maximum speed limit, but actual speed may be further limited by other factors
#define SUPERIMPOSE_FIRST_INBOARDS_IN_PAIRS 1                                //If defined allows the rail-to-rail inboard Analog Inputs to be used to adjust digipots, but mainly causes first inboard Analog Inputs to be paired (superimposed in pairs sharing plot-line spaces) so even manual pots can be adjusted easily.
//#define PLOT_ONLY_THE_SIGNAL_LEG_OF_SUPERIMPOSED_DPOT_LEG_BRIDGE_INBOARDS  //By defining this macro comparison between signal and reference is no longer possible but it could be less confusing this way since user doesn't need to manually adjust anything with DPots and especially with AUTO_BRIDGE_BALANCING. ADVISE without AUTO_BRIDGE_BALANCING in effect, this macro probably should not be defined either. But regardless for greatest flexibility, that macro won't affect this.
//#define AUTO_BRIDGE_BALANCING                                                //increases setup time and during which the plot timing line stays high, then spikes low and high to indicate balancing complete //Turns on auto-balancing in setup(), significant time elapse for this to complete!
#define CONTINUE_PLOTTING_DURING_AUTO_BRIDGE_BALANCE true                    //Without predictive balancing, this takes too much time if true
//#define DEBUG                                                              //Don't forget that DEBUG is not formatted for Serial plotter, but might work anyway if you'd never print numbers only any DEBUG print line
#define SHOW_LINEARITY_USING_THIS_BRIDGE_INDEX 0
#define INJECT_DIAGNOSTIC_SQUARE_WAVE_ON_SIGNAL_PIN_OF_SPECIFIED_OUTBOARD_ADC 0       //For testing - wobbles digipot settings on bridge index to impose a signal into Wheatstone bridge outputs. This imposes a signal on the signal leg
#define INJECT_DIAGNOSTIC_SQUARE_WAVE_ON_REFERENCE_PIN_OF_SPECIFIED_OUTBOARD_ADC 0    //For testing - wobbles digipot settings on bridge index to impose a signal into Wheatstone bridge outputs. This imposes a signal on the reference leg
#define DIAGNOSTIC_SQUARE_WAVE_TIME_PERIOD  10
//#define LEAVE_POT_VALUES_ALONE_DURING_SETUP                                         //First run should leave this undefined to load digi pots with some values
#define BIAS_IN_ANALOG_INPUT_BITS_TO_APPLY_TO_SIGNAL_LEG_TO_CENTER_THE_TRACE_BRIDGE0 0  //This offset will be applied to all signal lines of outboard ADCs, not just the first one, until further development.  Write some code yourself to expand.  Inboard Analog Inputs of 10 bits will make much change with little values, 12 bit inboard allows more flexibility here
#ifdef BIAS_IN_ANALOG_INPUT_BITS_TO_APPLY_TO_SIGNAL_LEG_TO_CENTER_THE_TRACE_BRIDGE0
#define ADDITIONAL_BIAS_IN_LSB_DPOT_SETTING_POSITION_TO_APPLY_TO_SIGNAL_TRACE_BRIDGE0 2 //To maintain consistent effect with the above, associated macro, this gets applied inverted. This is in lieu of setting by reading the ADCs and zeroing them.
#endif
#ifdef __LGT8FX8E__
#define BAUD_TO_SERIAL 19200                                                          //This speed is what works best with WeMos XI/TTGO XI board.  Experiment as desired.
#else
#define BAUD_TO_SERIAL 115200                                                         //YOU MAY SET THIS TO THE MAXIMUM VALUE THAT YOUR CONFIGURATION WILL FUNCTION WITH (UNLESS YOU'RE USING THE WeMos XI/TTGO XI, OF COURSE)
#endif
#define DPOT_RATIO 20 /* DPOT_RATIO: System-wide MSB/LSB.  Ex.: If the LSB digipot is 200 ohms/step and the MSB digipot is 2000 ohms/step, this value will be 10. (2000/200)
                      It is only used relative to the LSB digipot, so there can only be that one digipot per leg allowed to have a smaller resistance
                      per step than other digipots on the leg. All bridge legs in the system must be built with the same ratio scheme, and must always include one and
                      only one LSB digipot, with all non-LSB digipots matching each others' resistance/step values.  This macro limits LSB settings adjustments
                      when another digipot in the leg is set to less than MAX_DPOT_SETTG, but not otherwise, allowing LSB to reach MAX_DPOT_SETTG when non-LSBs are all at MAX_DPOT_SETTG.
                      As far as MAX_DPOT_SETTG, all digipots in the system are bound by the same MAX_DPOT_SETTG value. */
//#define MINIMIZE_COMPILED_SKETCH_SIZE_LEVEL 0      somehow this does the opposite!!!   //Number 0 produces smallest sketch giving least data output functionality
//#define LOOP_COUNTER_LIMIT_THAT_TRACE_IS_ALLOWED_TO_BE_OFF_CENTER 3                   //sets how soon run-time auto-balancing kicks in when trace goes off scale
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
void loop()
{
#if ( ( not defined MINIMIZE_COMMUNICATIONS_CLUTTER_FOR_HIGHER_MAX_SPEED_ONLY_COMPATIBLE_FOR_OFFICIAL_ARDUINO_IDE ) || ( MINIMIZE_COMMUNICATIONS_CLUTTER_FOR_HIGHER_MAX_SPEED_ONLY_COMPATIBLE_FOR_OFFICIAL_ARDUINO_IDE == false ) )
#if ( DPOTS_IN_ALL_LM334_BRIDGES + DPOTS_IN_ALL_BARE_LEG_BRIDGES + DPOTS_IN_ALL_BARE_LEGS_UNBRIDGED > 0 )
  for( uint8_t csIndex = 0; csIndex < DPOTS; csIndex++ )
  {
    Serial.print( F( "dPotSettings[" ) );
    Serial.print( dPotPins[ csIndex ] );
    Serial.print( F( "]=" ) );
    Serial.print( dPotSettings[ csIndex ] );
    if( csIndex < DPOTS - 1 )
      Serial.print( F( ",. " ) );
    else
      Serial.print( F( ",. " ) );
  }
#endif
#endif
  for( plotterLoops = 0; plotterLoops < 500 / 3; plotterLoops++ )
  {
    millisStart = millis();
    //        if( graphLine ) thisReadingTemp = 0;
    //        else thisReadingTemp = PLOTTER_MAX_SCALE;
    //        Serial.print( thisReadingTemp ); //This was originally last printed in the group.  It needs to be first instead so the line can be "notched" horizontally without needing to reprint all values.
    //        Serial.print( F( " " ) );
    //        readAndPlotFromAllADCsInAndOutboard( thisReadingTemp );
    readAndPlotFromAllADCsInAndOutboard( graphLine ? 0 : PLOTTER_MAX_SCALE );
#ifdef AUTO_BRIDGE_BALANCING //Unsure of how to relate this macro and macro DIFFERENTIAL
    for( uint8_t whichOutboardADCindex = 0; whichOutboardADCindex < OUTBOARDS_PLOTTED; whichOutboardADCindex++ )
    {
      if( masterReadingsArray[ INDEX_OF_OUTBOARDS + whichOutboardADCindex ].CurrentUnmagnifiedReading >= HEIGHT_OF_A_PLOT_LINESPACE - 1 ) //means signal leg is higher
      { ;
#if ( ( not defined MINIMIZE_COMMUNICATIONS_CLUTTER_FOR_HIGHER_MAX_SPEED_ONLY_COMPATIBLE_FOR_OFFICIAL_ARDUINO_IDE ) || ( MINIMIZE_COMMUNICATIONS_CLUTTER_FOR_HIGHER_MAX_SPEED_ONLY_COMPATIBLE_FOR_OFFICIAL_ARDUINO_IDE == false ) )
        Serial.print( F( " reading maxed out " ) );
#endif
#if ( defined DIFFERENTIAL ) && ( defined LOOP_COUNTER_LIMIT_THAT_TRACE_IS_ALLOWED_TO_BE_OFF_CENTER )
        if( --counterForTraceOutOfRangeTooLong[ whichOutboardADCindex ] < -LOOP_COUNTER_LIMIT_THAT_TRACE_IS_ALLOWED_TO_BE_OFF_CENTER )
        {
          //Process: raise reference leg if it is lower than commonmode... level until it reaches commonmode..., then lower signal leg until can't lower it any more, then resume to raise reference leg until can't raise it any more
          //                setSignalBridgeLegInput( whichOutboardADCindex ); // Instead maybe use AdjustBridgeOutput ative( bridge );
#if ( ( not defined MINIMIZE_COMMUNICATIONS_CLUTTER_FOR_HIGHER_MAX_SPEED_ONLY_COMPATIBLE_FOR_OFFICIAL_ARDUINO_IDE ) || ( MINIMIZE_COMMUNICATIONS_CLUTTER_FOR_HIGHER_MAX_SPEED_ONLY_COMPATIBLE_FOR_OFFICIAL_ARDUINO_IDE == false ) )
          Serial.print( F( "for longer than allowed " ) );
#endif
            configureForSignalLegWithBridgeIndexIncludingNonBridgedLegs( whichOutboardADCindex );
          adjustBridgeOutputNegative( whichOutboardADCindex );
          plotterLoops = 0;
        }
#endif
      }
      else if( masterReadingsArray[ INDEX_OF_OUTBOARDS + whichOutboardADCindex ].CurrentUnmagnifiedReading == 0 ) //means reference leg is higher
      { ;
#if ( ( not defined MINIMIZE_COMMUNICATIONS_CLUTTER_FOR_HIGHER_MAX_SPEED_ONLY_COMPATIBLE_FOR_OFFICIAL_ARDUINO_IDE ) || ( MINIMIZE_COMMUNICATIONS_CLUTTER_FOR_HIGHER_MAX_SPEED_ONLY_COMPATIBLE_FOR_OFFICIAL_ARDUINO_IDE == false ) )
        Serial.print( F( " reading zeroed out " ) );
#endif
#if ( defined DIFFERENTIAL ) && ( defined LOOP_COUNTER_LIMIT_THAT_TRACE_IS_ALLOWED_TO_BE_OFF_CENTER )
        if( ++counterForTraceOutOfRangeTooLong[ whichOutboardADCindex ] > LOOP_COUNTER_LIMIT_THAT_TRACE_IS_ALLOWED_TO_BE_OFF_CENTER )
        {
          //Process: lower reference leg if it is higher than commonmode... level until it reaches commonmode..., then raise signal leg until can't raise it any more, then resume to lower reference leg until can't lower it any more
          //                setSignalBridgeLegInput( whichOutboardADCindex ); // Instead maybe use AdjustBridgeOutput ative( bridge );
#if ( ( not defined MINIMIZE_COMMUNICATIONS_CLUTTER_FOR_HIGHER_MAX_SPEED_ONLY_COMPATIBLE_FOR_OFFICIAL_ARDUINO_IDE ) || ( MINIMIZE_COMMUNICATIONS_CLUTTER_FOR_HIGHER_MAX_SPEED_ONLY_COMPATIBLE_FOR_OFFICIAL_ARDUINO_IDE == false ) )
          Serial.print( F( "for longer than allowed " ) );
#endif
            configureForSignalLegWithBridgeIndexIncludingNonBridgedLegs( whichOutboardADCindex );
          adjustBridgeOutputPositive( whichOutboardADCindex );
          plotterLoops = 0;
        }
#endif
      }
#ifdef DIFFERENTIAL
      else
      {
        counterForTraceOutOfRangeTooLong[ whichOutboardADCindex ] = 0;
      }
#endif
    }
#endif
    //        Serial.println();
    /* The following commented code can be used for keyboard input */
#ifdef DEBUG
            char nextChar;
            nextChar = 0;
            while( Serial.available() )
            {
      //            pinMode( LED_BUILTIN, OUTPUT );                // These lines for blinking the LED are here if you want the LED to blink when data is rec'd
      //            digitalWrite( LED_BUILTIN, HIGH );             // These lines for blinking the LED are here if you want the LED to blink when data is rec'd
                nextChar = (char)Serial.read();
                if( nextChar != 0xD && nextChar != 0xA )
                {
                    szFull[ strlen( szFull ) + 1 ] = 0;
                    szFull[ strlen( szFull ) ] = nextChar;
                }
                else
                {
                    if( Serial.available() ) Serial.read();
                    nextChar = 0;
                }
            }
      //        digitalWrite( LED_BUILTIN, LOW );                  // These lines for blinking the LED are here if you want the LED to blink when data is rec'd
            if( !( szFull[ 0 ] == 0 || nextChar != 0 ) )        //The way this and while loop is set up allows reception of lines with no endings but at a timing cost of one loop()
            {
                #ifdef DEBUG
                    while( !Serial ); // wait for serial port to connect. Needed for Leonardo's native USB
                    Serial.print( F( "Received " ) );
                    Serial.println( szFull );
                #endif
        #if defined LEGS_PER_DPOT_STYLE_BRIDGE
                uint8_t DIGITAL_POT_;
                int offset_integer;
                if( szFull[ 1 ] == 'D' || szFull[ 1 ] == 'd' ) szFull[ 1 ] = '-';
                else if( szFull[ 1 ] == 'U' || szFull[ 1 ] == 'u' ) szFull[ 1 ] = '+';
                if( szFull[ 1 ] == '-' )
                {
                    if( szFull[ 2 ] == 0 )
                        offset_integer = -1;
                    else
                        offset_integer = 0 - atoi( &szFull[ 2 ] );
                }
                else if( szFull[ 1 ] == '+' )
                {
                    if( szFull[ 2 ] == 0 )
                        offset_integer = 1;
                    else
                        offset_integer = atoi( &szFull[ 2 ] );
                }
                else goto NoPotChange;
                if( offset_integer > MAX_DPOT_SETTG || offset_integer < 0 - MAX_DPOT_SETTG ) goto NoPotChange;
                if( szFull[ 0 ] == '1' ) DIGITAL_POT_ = dPotPins[ 0 ];
                else if( szFull[ 0 ] == '2' ) DIGITAL_POT_ = dPotPins[ 1 ];
                else if( szFull[ 0 ] == '3' ) DIGITAL_POT_ = dPotPins[ 2 ];
                else if( szFull[ 0 ] == '4' ) DIGITAL_POT_ = dPotPins[ 3 ];
                else if( szFull[ 0 ] == '5' ) DIGITAL_POT_ = dPotPins[ 4 ];
                else if( szFull[ 0 ] == '6' ) DIGITAL_POT_ = dPotPins[ 5 ];
                else goto NoPotChange;
                indexOfThisDPotCSPinInDPotArrays = atoi( &szFull[ 0 ] ) - 1;
                configureFromDPotIndex();
                offsetDPotOrMSBGroupValue( DIGITAL_POT_, offset_integer ); //configureFrom...() and configureFor...() must already be ran
                Serial.print( F( "Dpot " ) );
                Serial.print( DIGITAL_POT_ );
                Serial.print( F( " now set to " ) );
                Serial.println( dPotSettings[ atoi( &szFull[ 0 ] ) ] );
      NoPotChange:
        #endif
                szFull[ 0 ] = 0;
//                #ifdef DEBUG
                    while( !Serial ); // wait for serial port to connect. Needed for Leonardo's native USB
                    Serial.println();
//                #endif
            }
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

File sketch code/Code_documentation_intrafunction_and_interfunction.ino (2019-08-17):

/*
 * fix occurances of printing line numbers
 * effect various levels of verbosity
 * test with just two and just one dpot per leg


 
 
 
 
 
 
 
 
 
 
 
 
 
 
 
 
 
 
 
*/

/*

static uint16_t startLevelForCalculatingSettingUnitsPerAnalogUnit, startMSBSettingForCalculatingSettingUnitsPerAnalogUnit, startLSBSettingForCalculatingSettingUnitsPerAnalogUnit;
uint16_t bestOfFour( uint8_t );
#define MOST_ACCURATE true  //This belongs with the following function declare
uint16_t bestGuessAnalogInputreading( uint8_t = dPotLeg, bool = !MOST_ACCURATE, bool = true );
#define TARGET_LEVEL_DUMMY_VALUE 0
bool lowestLevelDPotLegSetpointing( uint16_t incomingInboardAnalogLevel, uint16_t targetLevel, bool justPerformOneStep = false )
{
}

bool stepAdjustDPotsForThisLeg( bool = TAKE_LEG_VOLTAGE_DOWN, uint16_t = 0, bool = false ); //default direction will be positive
bool midLevelDPotLegSetpointing( uint16_t incomingBestGuessAnalogInputreading, uint16_t targetLevel, bool justPerformOneStep = false )
{ //midLevelDPotLegSetpointing should do this stepsizes thing also but with LSB and bestGuessAnalogInputreading
}

uint16_t thirdLevelDPotLegSetpointing( uint16_t incomingBestGuessAnalogInputreading, uint16_t targetLevel, bool justPerformOneStep = false ) //The return value is used to caculate referenceLSBSettingUnitsPerAnalogInputUnit[ dPotLeg ] and analogInputUnitsPerReferenceMSBSettingUnit[ dPotLeg ]
{ //midLevelDPotLegSetpointing should do this stepsizes thing also but with LSB and bestGuessAnalogInputreading
}

#if ( ( defined AUTO_BRIDGE_BALANCING ) && ( defined DIFFERENTIAL ) )
bool highestLevelDifferentialBridgeSetpointing( uint8_t OutboardADCindex = whichBridgeOrOutboardADCindex, uint8_t limit = 15 )
{
}

bool setDPotLegMidPoint( uint8_t, bool, bool = !GO_IN_SMALL_STEPS, bool  = !USE_SIGNAL_LEGS_LEVEL_AS_TARGET_LEVEL ); //All this does without the third argument is set the reference leg to COMMON_MODE_LEVEL_FOR_MAX_GAIN_AS_READ_RAW_BY_INBOARD_ANALOG.
bool adjustBridgeOutputPositive( uint8_t bridge = whichBridgeOrOutboardADCindex ) //TODO: make this function faster through predictive step sizes
{ //If all pots are maxed (positive leg to positive and negative leg to negative) return false
}

bool setDPotLegMidPoint( uint8_t, bool , bool = !GO_IN_SMALL_STEPS,  bool  = !USE_SIGNAL_LEGS_LEVEL_AS_TARGET_LEVEL ); //All this does without the third argument is set the reference leg to COMMON_MODE_LEVEL_FOR_MAX_GAIN_AS_READ_RAW_BY_INBOARD_ANALOG.

bool adjustBridgeOutputPositive( uint8_t bridge = whichBridgeOrOutboardADCindex ) //TODO: make this function faster through predictive step sizes
{ //If all pots are maxed (positive leg to positive and negative leg to negative) return false
}

bool adjustBridgeOutputNegative( uint8_t bridge )
{ //If all pots are maxed (positive leg to negative and negative leg to positive) return false
}

uint16_t bestGuessAnalogInputreading( uint8_t dPotLegOrIndexedInboardAnalogInput, bool mostAccurate, bool usingGlobalValueOfDPotLegForAnalogPinArrayIndex )
//#else
//uint16_t bestGuessAnalogInputreading( uint8_t dPotLegOrIndexedInboardAnalogInput, bool mostAccurate, bool usingGlobalValueOfDPotLegForAnalogPinArrayIndex, uint8_t dPotLeg )
{ //returns an INBOARD Analog Input pin reading, same as leg reading
}

static uint8_t setDPotsStep = 0;
bool setDPotLegMidPoint( uint8_t bridge, bool thisIsReferenceLegOfBridge, bool justPerformOneStep, bool useSignalLegLevelAsTargetLevel ) //All this does without the third argument is set the reference leg to COMMON_MODE_LEVEL_FOR_MAX_GAIN_AS_READ_RAW_BY_INBOARD_ANALOG.
{ //recursive calls to this will not work if statics are used
}

1.  make best guess adjustment [caller checks if differential reading came into range, stayed same direction or changed direction]
2a. if came into differential range, adjust toward half scale until overshoots, then STOP
2b. if stayed same direction check if any closer, if yes recalculate a new setting and loop else stop if not
2c. if changed direction recalculate a new setting and loop







 */

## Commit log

2019-08-02 CAD picts simulated
    Note ADC1 is blanked out due to there is no CAD rendering I could find anywhere.
2019-08-02 Bare board renderings courtesy of OSH Park
    Bare board renderings courtesy of OSH Park
2019-08-03 Simulated board with components placed
    SHLD1 not shown so that components under it are visible
2019-08-03 Zipped gerber files: Order a PCB with this file
    Allows you not to be locked into OSH Park, but Chinese prices are rising to be less competitive for repeat orders if you specify OSH Park's quality for their product.
2019-08-03 Rename gerber files and shopping tool to gerber files and shopping tool.md
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2019-08-03 Schematic of main board plus auxiliary devices you need to build
    You'll need to build or buy a cable assembly with 1/8" plugs, preferably coaxial or at least shielded. A set of test dongles to simulate the DUT are also called for during assembly diagnostics. These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
2019-08-03 Views of PCB including components
    ADC1 blanked out since there is no 3D rendering online to be had
2019-08-03 Simulated board with components placed
    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
2019-08-03 Zipped gerber files: Order a PCB with this file
    Allows you not to be locked into OSH Park, but Chinese prices are rising to be less competitive for repeat orders if you specify OSH Park's quality for their product
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2019-08-04 Simulated board with components placed
    ADC1 blanked out since there is no 3D rendering online to be found
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2019-08-06 Offload this file to your computer else it won't open
    GitHub doesn't serve this file as a normal web page that you can open in your browser. You need to download it to somewhere that does, like your computer. Then your browser can render it like normal when you "Open File..." from your browser's menu.
    Kapton tape will be needed, but since it is not a circuit component, it doesn't get its own BOM line. If you want to laser cut stencils from it, get 2" wide and 6" long minimum plus what you'll need for short circuit protection underneath J1 and ADC1 and for place assist holding tape (3/8" wide, 6' long). Arrow has the narrow: P/N 3057, my source for the wide is AliExpress, which takes w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
2019-08-06 Raw KiCad format BOM netlist in case you want to modify
    This file is in the KiCad format you would need if you want to modify this BOM from within KiCad
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2019-08-10 Look to see if you need to purchase also
    1 roll Polyimide tape 3/8" wide 6' length or greater. Electrical insulator and place assist. P/N 3057 from Arrow or equivalent
    Electrodes have to be constructed from non-prepreg carbon fiber tow (good luck finding any, you may just have to use prepreg) as the electrode elements, women's nylon stocking, craft-rated styrofoam 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
2019-08-10 Look to see if you need to purchase also
    Kapton tape WILL be needed. It doesn't get into the BOM because it is not a circuit component. If you want to laser cut stencils from it, get 2" wide and 6" long minimum plus what you'll need for place assist holding tape (3/8" wide, 6' long)
    Electrodes have to be constructed from non-prepreg carbon fiber tow "yarn" (good luck finding any, you may just have to use prepreg, but don't get "spread" fiber) as the electrode elements, women's nylon stocking, craft-rated styrofoam "beans" that go inside the stockings, light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
2019-08-17 Offload this file to your computer else it won't open
    GitHub doesn't permit normal web page service that would allow this file to open directly in your browser. You need to download it to somewhere that will - your computer will work. Then your browser can render it like normal when you "Open File..." from your browser's menu.
    Kapton tape will be needed, but since it is not a circuit component, it doesn't get its own BOM line. If you want to laser cut stencils from it, get 2" wide and 6" long minimum plus what you'll need for short circuit protection underneath J1 and ADC1 and for place assist holding tape (3/8" wide, 6' long). Arrow has the narrow: P/N 3057, my source for the wide is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
2019-08-25 Schematic of main board plus auxiliary devices you need to build
    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
2019-08-25 This is very much NOT polished code!
    I threw some diagnostics together wile building the first board, but was too tunnel-visioned with the circuitry that I didn't bother to clean up this code.
2019-08-25 Schematic of main board plus auxiliary devices you need to build
    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
2019-08-29 Schematic of main board plus auxiliary devices you need to build
    Read all notes.
    Relative to purchase of components: You'll need to build or buy a cable assembly with 1/8" plugs, preferably coaxial or at least shielded. A set of test dongles to simulate the DUT are also called fo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
2019-09-06 Schematic of main board plus auxiliary devices you need to assemble
    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
2019-09-06 Simulated board with components placed
    Also not shown is auxiliary flex board containing U9-U33 in parallel
    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
2019-09-06 Simulated board with components placed
    Also not shown is auxiliary flex board containing U9 - U33 all in parallel
    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
2019-09-06 Schematic of main board plus auxiliary devices you'll need to assemble
    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
2019-09-06 In the latest state of progress...
    ...definitely not in working state, but where I'll resume work when I get back to things.
    [Coax Cable and Diagnostic DUT.sch, uno shield v.8 project SMD.kicad_pcb, uno shield v.8 project SMD.sch]
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2019-09-07 In the latest state of progress...
    I HAVEN'T DESIGNED THE FLEX CIRCUIT BOARD FOR U9-U33, THE PARALLELED MCP4262-502 DPOTS, BUT THE REST OF THESE FILES ARE COMPLETED AND FUNCTIONAL TO THE BEST OF MY UNDERSTANDING, INCLUDING THE MAIN BOARD BEING COMPLETE AND WORKING.
    [Coax Cable and Diagnostic DUT.sch, uno shield v.8 project SMD WITH U9-33.kicad_pcb, uno shield v.8 project SMD.kicad_pcb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]
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2019-09-10 Untested while awaiting bare PCB boards....
    These KiCad and zipped gerber files are fully designed but not yet tested while I await the bare boards on order now. I'm estimating mid- to late-October will see the final evaluation of operation of the entire device. Shortly after that, I would expect to demonstrate its concepts and operation via YouTube and personal travel.
    [Quantum MCP4262-502 25x expansion flex for GWAAM-Sea Aid.kicad_pcb, uno shield v.8 project SMD WITH U9-33.sch, uno shield v.8 project SMD.kicad_pcb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]
2019-09-11 Offload this file to your computer else it won't open &
    There are other items for you to obtain that aren't in this BOM because they aren't depicted in schematic symbols. Combine those items to these before ordering! Otherwise you'll end up paying extra ordering costs. They are found in this file: https://github.com/kenneth558/plant_resistance_primary_perception/blob/Free/Where%20to%20find%20everything%20for%20mak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
2019-09-15 Untested while awaiting bare PCB boards...
    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
2019-09-15 Schematic of main board plus auxiliary devices you'll need to assemble
    Read all notes. This is for the main board, not the flex board.
    Relative to purchase of components: You'll need to build or buy a cable assembly with 1/8" plugs, preferably coaxial or at least shielded. A set of test dongles to simulate the DUT are also called for during assembly diagnostics. These things are on the second sheet but their references may not match the BOM. The contacting material of the electrodes should be made of non-impregnated carbon fiber tow. You'll probably only find prepreg unless you really search hard for the non-impregnated tow. Where the carbon fiber connects into wire as it nears the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
2019-09-23 Untested while I'm building it out
    These KiCad and zipped gerber files are fully designed but not yet tested while I'm building the bare boards now. I'm estimating mid- to late-October will see the final evaluation of operation of the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
2019-09-23 Order from this materials and vendors list - Offload this file to your computer else it won't open
    Kapton tape will be needed, but since it is not a circuit component, it doesn't get its own BOM line. If you want to laser cut stencils from it, get 2" wide and 6" long minimum plus what you'll need for short circuit protection underneath J1 and ADC1 and for place assist holding tape (3/8" wide, 6' long). Arrow has th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
2019-09-23 Order from this materials and vendors list - Offload this file...
    ...to your computer or a normal web server else it won't open.
    Kapton tape will be needed, but since it is not a circuit component, it doesn't get its own BOM line. If you want to laser cut stencils from it, get 2" wide and 6" long minimum plus what you'll need for short circuit protection underneath J1 and ADC1 and for place assist holding tape (3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
2019-09-23 KiCad language BOM
    BOM=Bill Of Materials; components to order and which vendor to order each from
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2019-09-27 Untested while awaiting bare PCB boards...
    These KiCad and zipped gerber files are fully designed but not yet tested while I build the bare boards. I'm estimating mid- to late-October will see the final evaluation of operation of the entire device. Shortly after that, I would expect to demonstrate its concepts and operation via YouTube and personal travel.
2019-09-30 Untested while awaiting bare PCB boards....
    [Quantum MCP4262-502 25x expansion flex for GWAAM-Sea Aid.kicad_pcb]
2019-09-30 Gerbers, Untested while awaiting bare PCB boards....
    Gerbers for flex board
2019-10-10 Operation of this design verified Oct 9 2019...
    ...Note that the MCU RFI noise contributed from the flex board can be lowered greatly if you'll wrap the flex board in metal foil and insulate that foil. Standard wisdom is that the shielding also should be grounded somehow as an exception to its insulation.
    [Quantum MCP4262-502 25x expansion flex for GWAAM-Sea Aid-B_Cu.gbl, Quantum MCP4262-502 25x expansion flex for GWAAM-Sea Aid-B_Mask.gbs, Quantum MCP4262-502 25x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]
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2019-10-14 Main board zipped gerbers
    You'll also need to order the flex board using the flex board gerbers
2019-10-21 V1.0 working
    [Quantum MCP4262-502 25x expansion flex for GWAAM-Sea Aid with U7 expansion cutout-B_Cu.gbl, Quantum MCP4262-502 25x expansion flex for GWAAM-Sea Aid with U7 ex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]
2019-11-19 Removed this text
    [Version 1.0 PCB available for sale at OSH Park](https://oshpark.com/shared_projects/fMOmbNgI) and you will need to also order [the expansion flex board](https://oshpark.com/shared_projects/xzXltQcl). As of Oct 9, 2019 this revision level has been found to function as designed, but can benefit greatly from some metal foil wrapped around the flex board to better shield noise out. Of course, insulate both the flex board and metal foil with Kapton tape to prevent electrical shorts.
    ![A 3D rendering of a populated board was supposed to show here](https://github.com/kenneth558/plant_resistance_primary_perception/blob/Free/Where%20to%20find%20everything%20for%20making%20your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
2019-12-14 So new that the PCB is not caught up
    This latest schematic is so new that the PCB layout for it is still not finished
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2020-01-19 Schematic v1.0
    The optional HX711 ADC is now a break-off style tab due to lack of PCB space for it in the normal Arduino footprint. In my judgement, the noise headroom will be inadequate for it to provide useful output in the intended application anyway. No doubt other applications may be found that could make use of it so I will just leave it this way as an option.
2020-02-09 Download this file to local machine b/c way GitHub delivers it
    GitHub doesn't deliver this file like a web server would, so you must download it to your machine. It is a parts list with supply houses where to purchase each component. Components of the auxiliary board are not listed normally, but if you read the sources column you'll see the info all there just the same.
2020-02-10 Gerber files are .zip, solder mask files are .svg
    Solder mask files contain both board sides in a single file
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2020-05-06 Find FreeCAD Files at https://drive.google.com/drive/folders/1ULUulqfxnpEf3x2tb2fJzP_oNYusfH2K?usp=sharing
    Find FreeCAD Files for pick and place cassette at https://drive.google.com/drive/folders/1ULUulqfxnpEf3x2tb2fJzP_oNYusfH2K?usp=sharing
    [Quantum MCP4262-502 25x expansion new flex for GWAAM-Sea Aid.sch, Top PnP Component Stencil.stl, uno shield v1.0 project SMD with aux board.kicad_pcb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]
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2020-05-09 Find FreeCAD Files at https://drive.google.com/drive/folders/1ULUulqf… … ……xnpEf3x2tb2fJzP_oNYusfH2K?usp=sharing
    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
    [Top PnP Component Stencil.stl]
2020-05-09 Find FreeCAD Files at https://drive.google.com/drive/folders/1ULUulqf…… … … ……xnpEf3x2tb2fJzP_oNYusfH2K?usp=sharing
    Find FreeCAD Files at https://drive.google.com/drive/folders/1ULUulqf……
    … … ……xnpEf3x2tb2fJzP_oNYusfH2K?usp=sharing
    [Top PnP Component Stencil.stl]
2020-05-09 Find FreeCAD Files for pick and place cassette at https://drive.google.com/drive/folders/1ULUulqfxnpEf3x2tb2fJzP_oNYusfH2K?usp=sharing
    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
    [Bottom PnP Component Stencil.stl]
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2020-05-10 Open this in a spreadsheet
    [uno shield v1.xlsx]

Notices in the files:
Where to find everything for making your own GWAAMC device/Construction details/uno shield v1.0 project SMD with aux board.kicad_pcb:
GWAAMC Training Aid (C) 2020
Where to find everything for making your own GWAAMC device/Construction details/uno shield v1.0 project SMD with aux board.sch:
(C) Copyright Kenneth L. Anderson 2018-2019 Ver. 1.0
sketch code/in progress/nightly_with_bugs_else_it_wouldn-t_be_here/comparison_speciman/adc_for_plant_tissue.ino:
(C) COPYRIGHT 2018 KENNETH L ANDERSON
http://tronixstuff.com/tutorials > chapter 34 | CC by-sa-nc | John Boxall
